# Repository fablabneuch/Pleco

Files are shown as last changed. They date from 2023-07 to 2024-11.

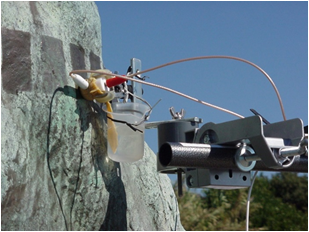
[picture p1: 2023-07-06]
wiki/images/5. Evaluation des protections/download (8).png

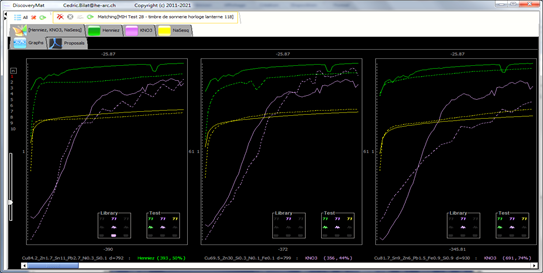
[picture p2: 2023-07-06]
wiki/images/1. Analyse - Outil CLAMTEC/download (2).png

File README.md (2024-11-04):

# Pleco

Pleco est un pinceau électrolytique d’un nouveau genre, constitué d’éléments à fabriquer et à assembler soi-même, ergonomique et d’utilisation facile. Conçu initialement pour le nettoyage localisé et par réduction électrolytique du ternissement de pièces en argent, il permet de proposer une alternative au traitement par immersion des éléments métalliques.

Shield: [][cc-by-sa]

This work is licensed under a
[Creative Commons Attribution-ShareAlike 4.0 International License][cc-by-sa].

[][cc-by-sa]

[cc-by-sa]: http://creativecommons.org/licenses/by-sa/4.0/
[cc-by-sa-image]: https://licensebuttons.net/l/by-sa/4.0/88x31.png
[cc-by-sa-shield]: https://img.shields.io/badge/License-CC%20BY--SA%204.0-lightgrey.svg

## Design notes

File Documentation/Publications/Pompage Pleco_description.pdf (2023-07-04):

# Travail de Bachelor Pompes Pleco

A l’attention de Vassili Tikhomirov et Christian Degrigny

Par Andreas Lazzarotto

Juillet 2017

### Abstract

The Pleco, an electrolytic tool designed by the HE-ARC, is an Open Source project involving two pumps. The pumps used are expensive laboratory pumps. Within the 2nd year of my bachelor diploma, I have been proposed to study the context of use of those pumps. Furthermore I have been asked to continue this work for my bachelor final work, and to design some cheap Open Source pumps for the Pleco.

This project first involved a complete context and user analysis to understand the end-users needs. The idea was to develop pumps that would be more adapted to the Pleco use. The design itself followed and permitted to build a first prototype. The final goal of this project was to produce a batch of pumps and a full documentation for anyone to make them.

### Résumé

Le Pleco, outil électrolytique développé par la HE-ARC, est un projet Open Source nécessitant l’utilisation de deux pompes. Les pompes utilisées jusqu’à aujourd’hui sont des modèles de laboratoire très coûteuses. Il m’a été proposé en deuxième année d’étudier le contexte d’utilisation de ces pompes, et de continuer cette étude en projet de bachelor en développant des pompes de remplacement bon marché et open source.

Ce projet a été mené d’abord par une analyse poussée du contexte et des utilisateurs qui a permis de bien comprendre les besoin réels et de créer des pompes plus adaptées et plus fonctionnelles que celle utilisées à l’origine. Suit la conception en elle-même, qui a mené à la construction d’un premier prototype fonctionnel. L’objectif final du projet est la fabrication d’une petite série de pompes et la mise à disposition complète de la documentation permettant de les construire.

### Remerciements

Je tiens à exprimer ma gratitude et mes remerciements à :

M. Christian Degrigny, professeur à la He-Arc, pour avoir proposé et suivi ce travail de bachelor,
M. Vassili Tichomirov, professeur à la He-arc, pour avoir tutoré ce travail de bachelor,
M. Romain Jeanneret, assistant de recherche à la He-Arc pour le temps qu’il m’a consacré en entretiens et observations,
M. Gaëtan Bussy, assistant de recherche à la He-arc pour son aide concernant l’électronique et la programmation, ainsi que son expertise concernant le FabLab,
Mme. Carole Baudin, professeur à la He-Arc, pour son soutien au cours du projet,
La société Minivalves (NL) pour la fourniture d’échantillons gratuits de duckbill valves,
L’association Fritzing Fab (D) pour la fabrication rapide de prototypes de PCBs.

## Table des matières

7.1.1 Boite | Erreur ! Signet non défini.

## 1 Introduction

Le sujet de mon projet de Bachelor est la conception de pompes, accessoires indispensables au fonctionnement du Pleco. Le Pleco est un nouveau pinceau électrolytique permettant le nettoyage d'objets patrimoniaux en argent terni ou la stabilisation d’objets en plomb sujets à des phénomènes de corrosion active. L'innovation vient du renouvellement continu de l'électrolyte via un système de pompage. Ce pinceau a été développé en collaboration entre la HE-ARC Ingénierie et la HE-ARC Conservation-Restauration. Il est entièrement fabricable dans un FabLab, un espace normalement équipé d’une imprimante 3D et d’une découpeuse laser. Le réseau FabLab est implanté dans de nombreux pays. De plus, le Pleco est mis à disposition du public sous licence Open Source, afin que la communauté mondiale des professionnels de la conservation-restauration puisse en bénéficier tout en ayant la possibilité de l'améliorer. Mon projet entre dans cette philosophie et a pour but de mettre à disposition de cette même communauté des pompes Open Source, à prix réduit et fabricables avec les mêmes outils que le Pleco. On devrait ainsi remplacer les pompes actuelles du pinceau électrolytique Pleco par une alternative open source / open hardware meilleur marché.

### 1.1 Objectif

L’objectif est de concevoir deux pompes pour le pinceau électrolytique Pleco en tenant compte de différentes contraintes liées à l’environnement de production, à la philosophie open source et à la conception orientée vers l’utilisateur, en abaissant au maximum le coût de revient.

Le cahier des charges officiel du travail de Bachelor est consultable en annexe A1

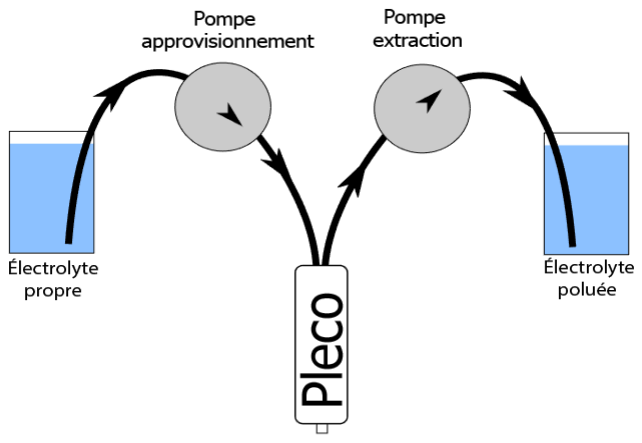
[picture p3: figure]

Schéma de fonctionnement du Pleco

Note : le volume d’électrolyte est en réalité suffisant pour n’avoir qu’un seul récipient avec une recirculation du fluide.

### 1.2 Pompes actuelles

Pompe de chimie KNF Simdos 10

Caractéristiques techniques :

- Débit de 1 à 100 mL/min grande précision
- Hauteur de colonne d’eau de 3m (aspiration)
- Pression max 85psig / 5.6bar
- Alimentation 100 - 240 V / 50 - 60 Hz
- Température d’opération +5 to +40° C
- Température du liquide +5 to +80° C
- Viscosité jusqu’à 500 cSt
- Précision +/-2% (nominal)
- Répétabilité +/-1%
- Consommation 24 W
- IP65
- Dimensions: 150 x 93 x 144 mm
- Poids: 0.9 kg

Avantage :

- Silencieuse
- Débit maîtrisé et mesuré
- Fonction amorçage
- Débit par à-coups
- Capable d’aspirer de l’air (non calculé dans le débit)
- Chimiquement résistant

Inconvénient :

- Prix élevée ~1000.-
- Trop d’options non-utilisées
- Difficultés d’accès au réglage à la volée
- Temps d’accès à la fonction d’amorçage trop long
- Nécessite un filtre pour protéger la pompe de toute microparticule, poussière issues du traitement et pouvant l’endommager
- Poids élevé, tout en restant gérable
- Réparation (due au blocage du système des membranes) nécessitant de faire intervenir le fabricant

### 1.3 Contraintes

- De fonctionnement
- Avoir un rapport de débit entre les deux pompes de 1 à 10 (débit entre 10 et 100mL/min) (Extraction avec un débit supérieur à l’approvisionnement)
- Avoir une fonction amorçage (bouton mettant débit max)
- Avoir une fonction pause
- Contraintes exogènes
- Faire circuler des bulles d’air dans l’électrolyte
- Supporter des pH compris entre 4 et 10.5
- Imposées par l’utilisateur
- Donner un moyen de comparaison visuel entre les débits
- Créer un produit robuste avec une bonne durée de vie
- Etre le plus silencieux possible
- Adapter l’ergonomie aux conservateurs-restaurateurs
- Mettre le projet sous licence Open Source / Open hardware
- Coûter le moins cher possible
- Autres contraintes
- Produire les pièces dans un Fablab (outils spécifiques)

## 2 Analyse de la demande

### 2.1 Cahier des charges fonctionnel

Une première analyse méthodique a permis d’identifier et de caractériser les fonctions que doit remplir l’objet. Cette analyse par méthode APTE® est en annexe A2.

De cette analyse découle une liste de fonctions qui doivent être satisfaites. La plupart de ces fonctions impliquent des solutions techniques simples pour être réalisées, et ne seront pas explicités dans le présent rapport. Les fonctions faisant intervenir le facteur humain ou l’environnement de travail sont plus complexes à traiter, et sont présentées dans la suite de ce cahier des charges.

### 2.2 Cahier des charges ergonomique

2.2.1 Fonctions sujettes à une analyse
Suite à la définition des fonctions, certaines requièrent une analyse ergonomique et anthropotechnologique pour mieux cerner les contraintes et l’attente des utilisateurs.
- FC1 : Faciliter l’assemblage
- FC2 : Fournir à l’utilisateur les informations et outils nécessaires au montage
- FP3 : Permettre à l'utilisateur de régler les deux pompes (physiquement)
- FP4 +FP4bis : Contrôler les 2 pompes (de manière différentielle)
- FC16 : S’intégrer sur le plan de travail
- FC17 : Contrôler la pompe (IHM et feedback)
- FP6 : Fabriquer la pompe dans un environnement Fablab

2.2.2 Analyses nécessaires

FC1 + FC2
Cerner les capacités de l’utilisateur (en l’occurrence des conservateurs-restaurateurs) en termes d’assemblage, et déterminer les limites de leurs compétences.
Déterminer les outils nécessaires à la compréhension des systèmes à assembler, et construire la documentation de montage en fonction de ces données.

FP3 + FP4 + FP4bis + FC17
Déterminer comment le réglage des pompes doit être opéré en fonction de l’utilisation du Pleco : différentes possibilités de réglages sont imaginables, elles doivent être testées pour déterminer laquelle est la plus appropriée.
Concernant le contrôle physique, il est nécessaire d’essayer deux types de curseurs : rotatifs et linéaires. Je suis personnellement convaincu que les curseurs linéaires donnent un meilleur feedback visuel de leur position par rapport à des curseurs rotatifs.
Une observation du travail journalier d’un conservateur-restaurateur pourrait aussi permettre d’identifier des routines reproductibles et ainsi alléger la charge cognitive.
La fonction FC17 : Contrôler la pompe, pose aussi la question de la position de l’interface de contrôle sur le plan de travail en parallèle à la position des pompes. Une observation de la fréquence de réglage des pompes, de l’environnement de travail des conservateurs-restaurateurs et de l’utilisation des pompes permettra de faire des choix sur ce sujet.

FP6
L’intégration dans la conception de l’environnement de fabrication et des outils à disposition est ici primordiale. Il faudra analyser les contraintes liées à l’environnement d’un Fab Lab.

## 3 Reformulation de la demande

Suite à ce premier travail d’analyse, la demande a été reformulée comme suit :

L’objectif du travail sera de concevoir un ensemble de pompes avec leurs contrôles en respectant les points suivants, dans leur ordre d’importance :

- Egaler les performances de débit des pompes originalement utilisées
- Fabriquer les pompes dans un FabLab
- Faire intervenir au maximum des outils Open Source
- Prendre en compte au maximum l’utilisateur dans la conception
- Limiter au maximum les coûts
- Faciliter les réglages des pompes
- Faciliter le transport et le rangement de l’ensemble
- Ajouter des fonctionnalités (contrôle de l’électrochimie)

## 4 Proof of concept

Le premier objectif de mon travail est de valider la possibilité de construire une pompe étanche et fonctionnelle dans un FabLab, avec comme outils principaux une découpeuse laser et une imprimante 3D.

### 4.1 Choix de la technologie

Il s’agit donc tout d’abord de choisir une technologie de pompage compatible avec la fabrication en FabLab, les débits définis ainsi que d’autres critères comme les saccades de débits.

Type | Péristaltique | À membranes

Illustration

Principe physique

On comprime un tube souple localement pour pousser le fluide qu'il contient

Un mouvement d'aller-retour d'une membrane dans une
chambre, associé à des valves antiretour met le fluide en mouvement
Stabilité du débit | pulsé | pulsé
Résistance chimique | Seul le tuyau est en contact avec le fluide | possibilité d'utiliser des membranes résistantes chimiquement (PTFE / AL / etc.)
Type d'étanchéité | Pas d'étanchéité | membrane / fermeture de carter
Précision de la fabrication | Très tolérante | Tolérante
Fabrication dans un Fablab | Facile | Moyennement difficile
Bruit | Bruyant | Modéré

Bon Acceptable Médiocre

Voir la boite morphologique complète en Annexe A3.
Après avoir essayé des pompes péristaltiques, j’ai pu noter que ces pompes réclament un très fort couple moteur et que le fonctionnement est assez bruyant, entre autre à cause des prise de contact alternatives des galets avec le tuyau. Cette solution n’a pas pu être choisie car le bruit est un des critères très importants pour le travail en continu avec les pompes du Pleco. Le choix s’est donc porté sur une technologie de pompes à membrane.

### 4.2 Conception d’une pompe à membrane

4.2.1 Définition

Les pompes à membrane fonctionnent avec, comme leur nom l'indique, une membrane qui oscille. L'oscillation de la membrane peut être créée par un excentrique mû par un moteur, un piston, un moteur linéaire, une vibration électromagnétique ou actionnée par de l'air comprimé.

Le mouvement de la membrane, accompagné de clapets d'entrée et de sortie, permet le plus souvent de réunir la fonctionnalité, pour tous les fluides, de pompages difficiles et précis.

La technologie de la simple ou double membrane, permet de réaliser des pompes capables de rester dans des dimensions extrêmement réduites (micro pompes) et d'être placées dans toutes les positions (même en immersion totale). D'autre part, elle ne transforme en rien la nature des liquides transportés.

Les applications touchent donc les secteurs, du médical, de l'alimentaire, de la chimie et pétrochimie, de l'analyse, de l'aquariophilie, du transport de liquides en petite quantité, etc.

[Wikipedia]

4.2.2 Principe de conception

Une solution simple serait de créer un empilement de plaques découpées au laser, prenant en sandwich une membrane en polymère.

Pompes « sandwich »

Se pose alors la question de l’étanchéité entre les plaques.

Utiliser une membrane en élastomère permettrait d’obtenir directement l’étanchéité en la serrant entre les plaques. Un joint pourrait être réalisé dans la même matière que la membrane pour l’interface chambre / couvercle.

Le point suivant est la mise en mouvement de la membrane. Percer la membrane reviendrait à créer une source de fuite potentielle, il faut donc identifier des moyens de mettre en mouvement la membrane sans la percer.

Une solution valable serait de maintenir la membrane entre deux aimants permanents (voir figure ci-contre), l’un étant dans la chambre et l’autre au bout d’une biellette à l’extérieur de la chambre.

4.2.3 Dimension de la membrane et de la chambre

Le débit max doit être de 100mL/minute

En considérant 2 cycles par seconde (chiffre empirique), au régime maximal, on obtient un volume par cycle de 0.85mL. En modélisant le volume balayé par la membrane avec un déplacement de la partie centrale de 3mm au centre, le diamètre minimal de la chambre a été fixé à 30mm.

Solide définissant le volume de la chambre de pompage

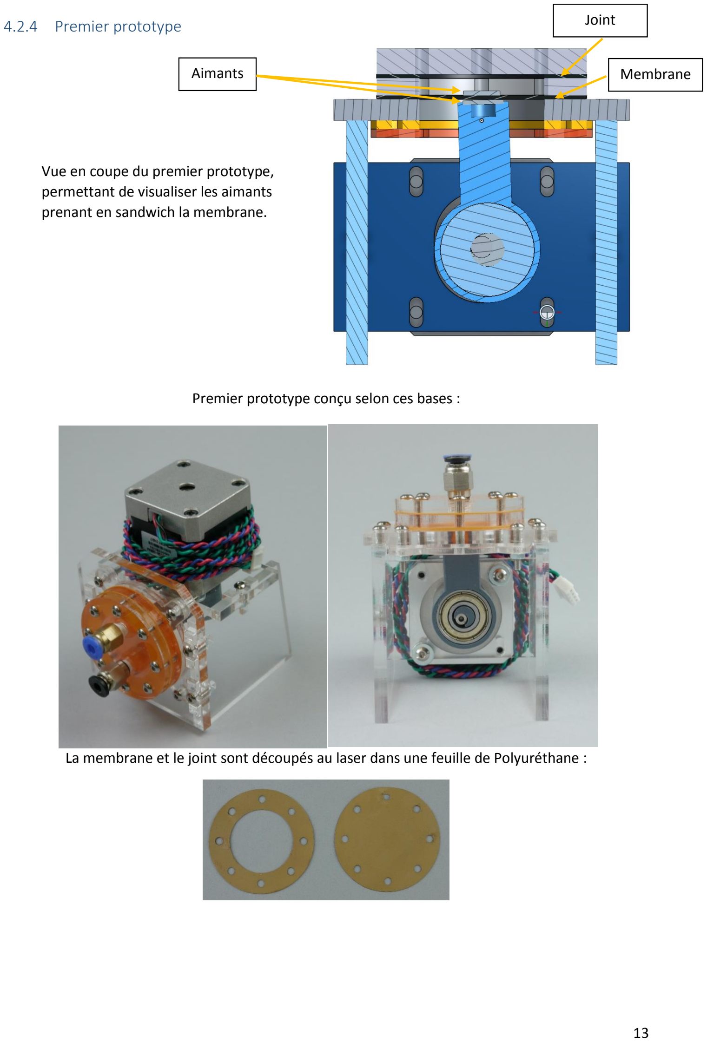
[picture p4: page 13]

4.2.4 Premier prototype

Premier prototype conçu selon ces bases :

La membrane et le joint sont découpés au laser dans une feuille de Polyuréthane :

Vue en coupe du premier prototype, permettant de visualiser les aimants prenant en sandwich la membrane.

Aimants | Membrane

Joint

Pour garantir le fonctionnement de la pompe, il faut ajouter des valves antiretour à l’entrée et à la sortie de la pompe.

Ces valves sont disponibles dans le commerce dans les secteurs de l’aquariophilie et dans le médical, où elles sont principalement utilisées dans les lignes de perfusion.

Ces valves fonctionnent pour la plupart sur la technologie « duckbill valve » (valve bec de canard).

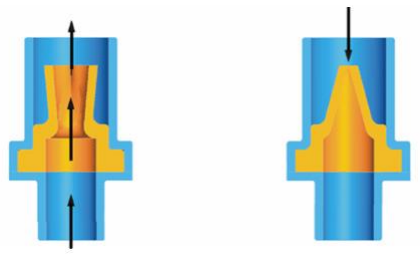
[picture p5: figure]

Fonctionnement d’une « duckbill valve »

Sur le premier prototype, ces valves sont des antiretours de perfusion obtenues auprès d’un assistant de recherche du domaine santé.

Elles sont montées sur les tubes d’entrées et sortie de la pompe.

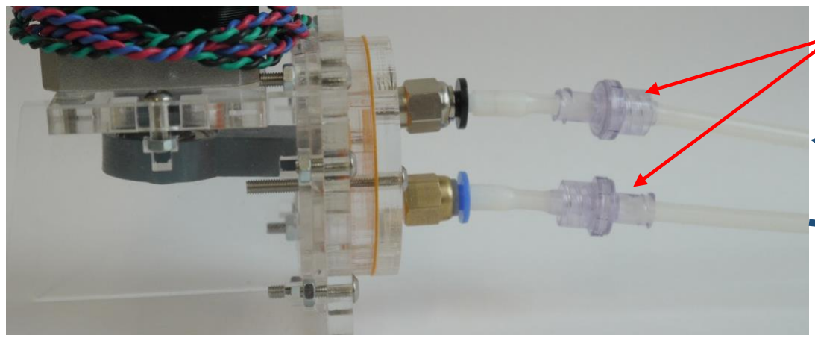
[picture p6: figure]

Antiretours de perfusion utilisés sur le premier prototype

4.3

### Validation du prototype

Le premier prototype s’est avéré fonctionnel, me confirmant qu’il est possible de construire une pompe à membrane dans un FabLab en utilisant des éléments standards disponibles partout dans le monde. Ce prototype n’est cependant pas parfait, et des défauts ont pu rapidement être identifiés : les aimants ont tendance à se décoller parfois, et la membrane est trop souple.

Antiretours

Circulation
d’électrolyte

Fluide en
contre
pression : la
valve bloque
le fluide

Fluide en
pression : la
valve laisse
passer le
fluide

### 4.4 Optimisation du prototype

Suite à cette première expérience, il semblait intéressant d’expérimenter l’utilisation de fil souple imprimé en 3D. Ces filaments sont disponibles chez plusieurs fabricants, et sont fabriqués à base de polyuréthane thermoplastique.

Le fait d’imprimer la membrane permet de lui intégrer un élément de mise en mouvement directe, évitant l’utilisation d’aimants. On peut ainsi accoupler directement la membrane avec la biellette sans autres éléments mécaniques.

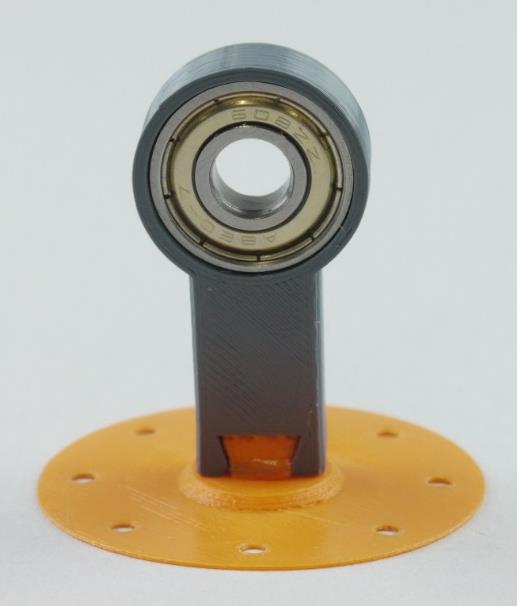
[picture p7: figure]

Assemblage de la membrane imprimée à la biellette

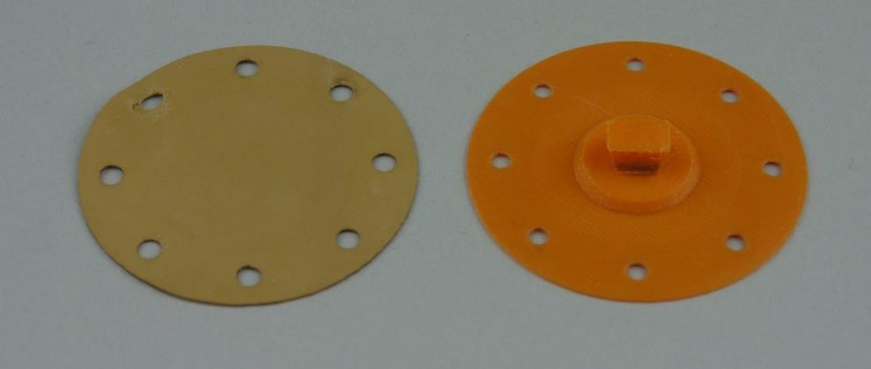
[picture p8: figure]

Comparaison entre les membranes découpée et imprimée

Suite à cette modification, le pompage s’est avéré plus constant (membrane plus rigide), le défaut de déconnection a disparu et l’étanchéité est restée parfaite.

Le principe de pompage est validé, et il faut maintenant s’intéresser à l’utilisation des pompes dans leur contexte particulier.

## 5 Recherches ergonomiques et anthropotechnologiques

### 5.1 Observations

5.1.1 Public concerné : les conservateurs-restaurateurs

La présente conception s’adresse à un public très ciblé : les conservateurs-restaurateurs (C-Rs). Afin de mieux centrer la conception autour des utilisateurs, il faut cerner leur profil et comprendre les représentations qu’ils se font de leurs outils et des pièces sur lesquelles ils travaillent.

Suite à plusieurs entretiens et observations avec Romain Jeanneret et Christian Degrigny (assistant de recherche et professeur du domaine C-R), le point le plus important est le fait que l’objet est le centre de leur attention. En effet, les objets à restaurer ou stabiliser ont une forte valeur historique et parfois une valeur pécuniaire élevée. La plus grande inquiétude des C-R est de dégrader l’objet, ce qui est une cause importante d’anxiété.

Il est intéressant de noter que leur travail s’articule autour des qualités suivantes : les C-R sont minutieux, précis, consciencieux et appliqués. Il est aussi important de prendre compte de l’environnement économique de la conservation-restauration. Ce milieu n’est pas facilement financé et les C-Rs sont souvent obligés de contourner un manque de moyen par du système-D. Ils sont donc assez bricoleurs et débrouillards.

5.1.2 Outil associé : le Pleco

Le Pleco est un pinceau électrolytique permettant le nettoyage de l’argent terni et la stabilisation de pièces en plomb oxydées. Il fait intervenir une solution électrolytique. Les réactions électrochimiques induites lors du nettoyage de l’argent génèrent des gaz, et il est donc préférable d’utiliser le Pleco sous une hôte.

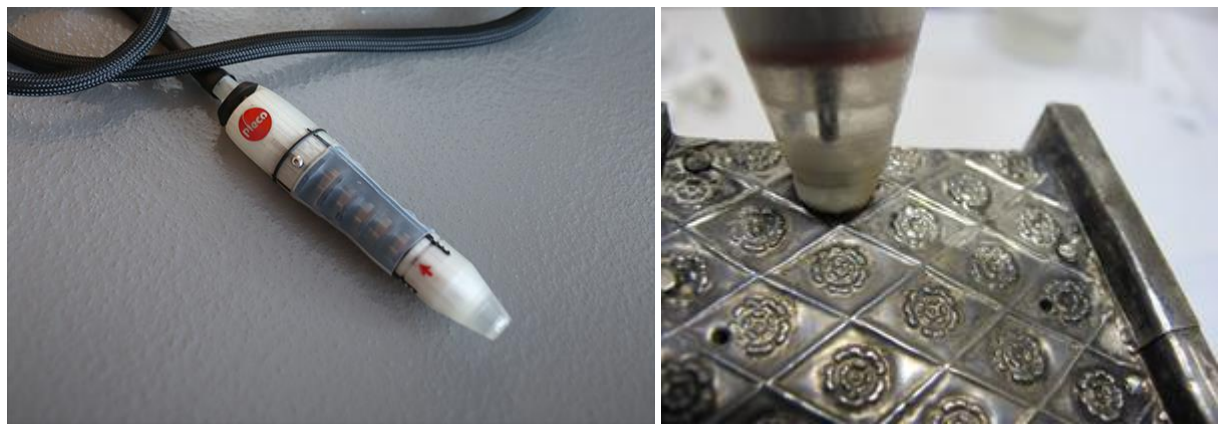
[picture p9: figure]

Le Pleco | Pièce en argent terni en cours de nettoyage
Cet | environnement | est | particulier :
paillasse carrelée avec peu de surface, souvent encombrée d’autres accessoires
(alimentation | stabilisée, | multimètre,
support, etc.). Il faudra tenir compte de cette observation pour optimiser la disposition des outils sur le plan de travail. Il faut aussi noter que les carreaux sont parfois humides, les matériaux des pompes devront donc être à l’épreuve de l’eau. (Il faut aussi prendre en compte le risque de fuite ou de fausses manipulations avec des liquides sur le plan de travail.)

L’un des aspects intéressants du Pleco est sa dimension communautaire. En effet, il a été développé pour et par une communauté de C-R, et des workshops permettent aux C-R de se rassembler pour construire et apprendre à utiliser leur nouvel outil. Le développement de cette petite communauté favorise une conception itérative par l’utilisation, comme elle est décrite dans le schéma suivant :

Cycle de conception du Pleco

5.1.3 Environnement de fabrication : Le Fab Lab

« La notion de Fab Lab (contraction de l’anglais FABrication LABoratory, traduction : laboratoire de fabrication) désigne un atelier composé de machines-outils pilotées par ordinateur pouvant fabriquer rapidement et à la demande des biens de nature variée. […] Pour être appelé Fab Lab, un atelier de fabrication numérique doit respecter la charte Fab Lab, (http://fab.cba.mit.edu/about/charter/) mise en place par le MIT. (http://fr.wikipedia.org/wiki/MIT) Les Fab Labs sont réunis en un réseau mondial très actif. » [Wikipédia]

La charte FabLab éditée par le MIT:

Mission: les fab labs sont un réseau mondial de laboratoires locaux, qui rendent possible l’invention en donnant aux individus accès à des outils de fabrication numérique.

Accès: vous pouvez utiliser le fab lab pour fabriquer à peu près n’importe quoi (dès lors que cela ne nuit à personne) ; vous devez apprendre à le fabriquer vous-même, et vous devez partager l’usage du lab avec d’autres usagers et utilisateurs.

Éducation: la formation dans le fab lab s’appuie sur des projets et l’apprentissage par les pairs ; vous devez prendre part à la capitalisation des connaissances et à l’instruction des autres utilisateurs.

Responsabilité: vous êtes responsable de :
– La sécurité : savoir travailler sans mettre en danger d’autres personnes ni endommager les machines,
– La propreté : laisser le lab plus propre que vous ne l’avez trouvé,
– La continuité : contribuer à entretenir et réparer les outils, à gérer les stocks de fournitures et à rendre compte des incidents.

Secret: les concepts et les processus développés dans les fab labs doivent demeurer disponibles pour un usage individuel même si la propriété intellectuelle peut être protégée.

Business: des activités commerciales peuvent être initiées dans les fab labs, mais elles ne doivent pas faire obstacle à l’accès ouvert. Elles doivent se développer au-delà du lab plutôt qu’en son sein et bénéficier à leur tour aux inventeurs, aux labs et aux réseaux qui ont contribué à leur succès.

[fablab-neuch.ch]

En d’autres termes, l’utilisation d’un Fab Lab s’articule autour du partage des ressources et des connaissances, et il faudra donc sensibiliser les utilisateurs du Pleco et de ses pompes à cette philosophie.

Ce milieu de fabrication particulier implique donc que les sources de l’objet créées soient disponibles, donc Open Source / Open Hardware.

Afin de protéger la propriété intellectuelle liée aux pompes, mais aussi afin de protéger ses créateurs contre toute action en justice liées à une utilisation inadéquate, il est nécessaire de placer les sources sous une licence spécifique réglementant l’usage des fichiers mis à disposition. Les licences standards Creative Common et leurs dérivés, plutôt appliquées aux créations artistiques, ne protègent pas les « objets » et la meilleure alternative pour l’open-hardware est la licence CERN, éditée par l’organisme du même nom dans le cadre de son programme de partage de technologies ouvertes. (Voir Annexe B1.1 pour la licence originale et B1.2 pour la licence traduite en français.)

Cette licence protège les créateurs de toute malfaçon ou mauvaise utilisation de l’objet, mais « oblige » aussi toute personne appliquant une modification à partager cette modification, tout en citant la source de base. Cette « obligation » est un encouragement au partage des connaissances et à l’amélioration continue à travers une communauté d’utilisateurs, et cette notion extrêmement importante devra être bien expliquée aux conservateurs-restaurateurs, notamment dans la notice de montage et au cours des workshops.

Les outils à disposition pour la fabrication des pompes, que l’on devrait pouvoir retrouver dans la plupart des FabLab, sont les imprimantes 3D (FDM disponibles partout), et une découpeuse laser. Il faudra se limiter au maximum à ces deux outils, et éviter les usinages « conventionnels », extrêmement chronophages et demandeurs de compétences et d’outillages peu répandus (tournage, fraisage)

5.1.4 Ergonomie de montage

[Note : il est admis que dans un premier temps la fabrication des éléments des pompes sera assurée par moi ou par une autre personne familiarisée avec le Fab lab, dans le but de créer des kits qui seront assemblés par des conservateurs-restaurateurs lors de workshops.

La question de la fabrication n’est donc pour le moment pas abordée dans d’autres mesures que de prévoir des petites séries]

L’assemblage du Pleco est principalement basé sur l’emboîtement d’éléments en plastique, maintenus en position par des boulons métriques. L’utilisation d’écrous noyés dans des emplacements spécifiques permet de mettre en place des vis dans des trous borgnes, sans avoir à maintenir manuellement l’écrou. Il permet de plus de fixer ensemble des plaques perpendiculaires les unes aux autres.

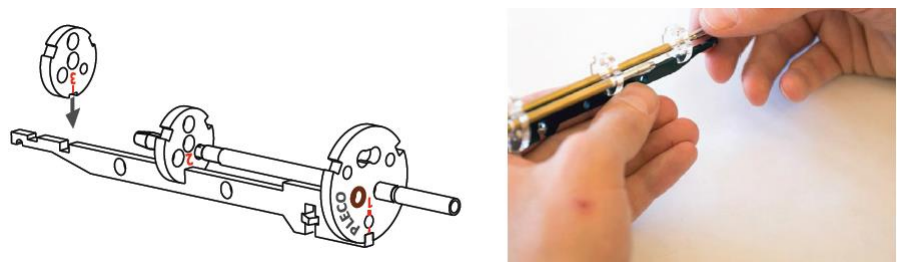
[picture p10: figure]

Illustrations extraites de la notice de montage du Pleco

Ces opérations sont simples à la condition que le logement d’écrou soit de la bonne taille, en garantissant un bon maintien de l’écrou, et que l’insertion de celui-ci ne brise pas la pièce.

L’assemblage par gaine thermo rétractable est intéressant dans son principe, mais s’est montré complexe à exécuter et requiert la création d’un outil d’assemblage spécifique.

Afin de simplifier le montage des pompes, il serait préférable de normaliser les types d’assemblages, en réutilisant la méthode des écrous noyés.

Il sera aussi important de normaliser la visserie (diamètre et longueur) afin d’éviter une charge cognitive supplémentaire lors du montage. 3 tailles de vis différentes au maximum semblent être idéales (en prenant en compte les vis déjà employées sur le Pleco). Ces vis devront toutes être assemblées avec le même outil, encore une fois dans un souci simplicité pour le monteur.

La question des compétences des monteurs reste entière, des tests itératifs sur des prototypes avec des notices provisoires permettront d’atteindre les objectifs fixés en termes de difficulté et temps maximum de montage.

La conception finale ainsi que la notice d’assemblage s’appuieront donc sur ces tests et sur les recommandations précédentes liées à l’assemblage.

### 5.2 Création de situations de références

Suite à ces observations, il reste quelques points obscurs pour lesquels aucune situation de référence n’a été trouvée. Il est donc nécessaire de les générer, en créant des tests impliquant les utilisateurs. Ces tests concernent la disposition des pompes sur le plan de travail, les méthodes d’assemblages et l’interface homme machine.

5.2.1 Disposition sur le plan de travail

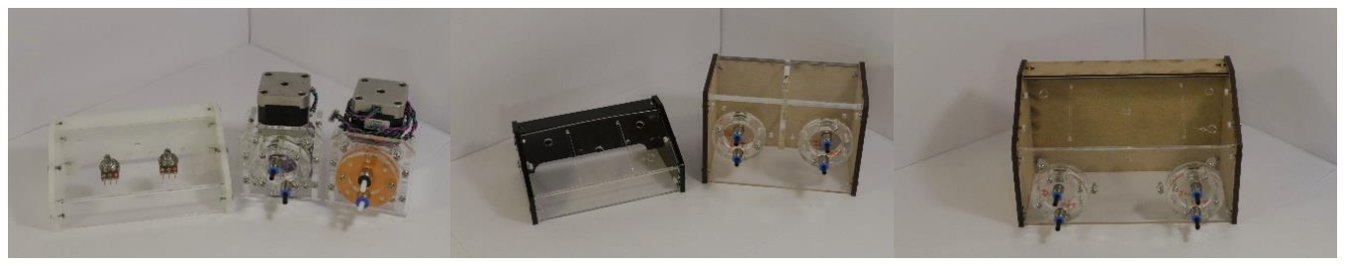
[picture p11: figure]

Console + 2 pompes | Console + pompes combinées | All in One

5.2.1.1 Test 1 : Pompes et console de contrôle séparés

Observations :

La console est placée en premier, à gauche de l’alimentation stabilisée, puis les pompes sont disposées de part et d’autre du réservoir d’électrolyte, au centre de la paillasse,
légèrement en arrière du statif.

Suite au constat que les pompes n’ont pas

besoin d’intervention durant l’utilisation, elles ont été reculées au fond de la paillasse pour dégager de la place autour de l’objet.

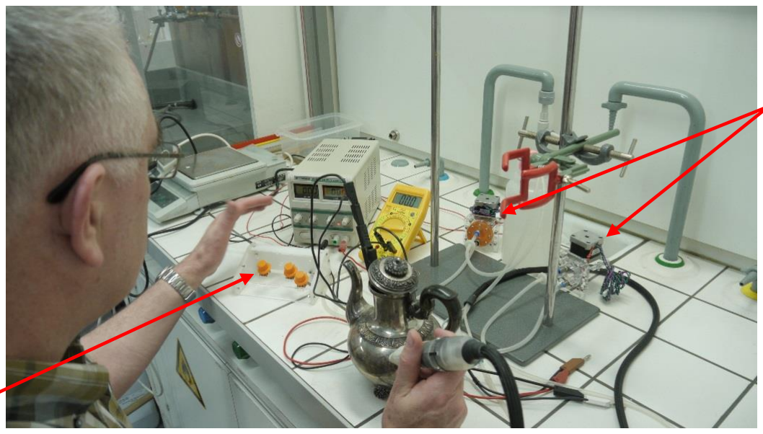
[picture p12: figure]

Pompes

Console de
contrôle

5.2.1.2 Test 2 : Pompes combinées et console de contrôle séparés.

Observations :

La console est placée à nouveau à gauche de l’alimentation stabilisée.

Le système des pompes est placé à côté du réservoir, avec une réflexion concernant le fait qu’elle pouvait être placée loin des mains. Elle est cependant placée bien en face de l’opérateur, à portée de vue.

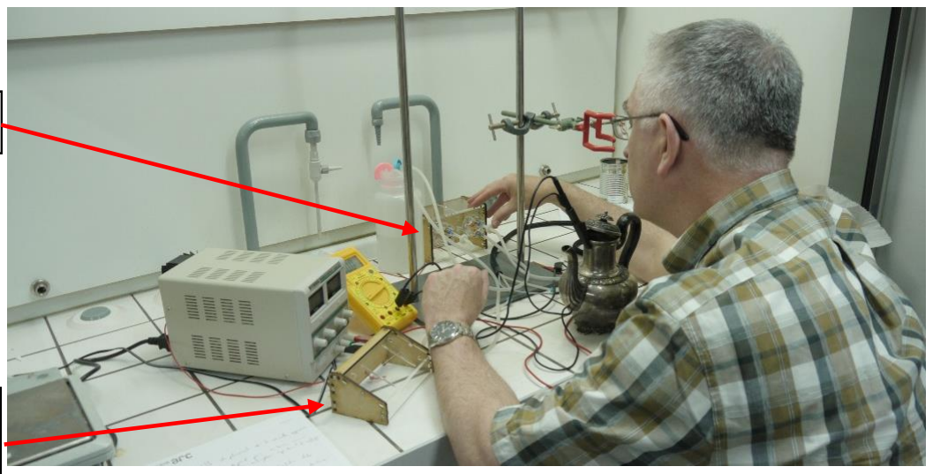
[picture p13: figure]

5.2.1.3 Test 3 : All in one

Observations :

Le boîtier est d’abord placé à gauche de l’alimentation stabilisée, puis un commentaire est fait sur la longueur des tubes pour aller au réservoir, jugés trop longs. Le boitier est alors déplacé entre l’alimentation stabilisée et le réservoir.
C. Degrigny constate alors que les contrôles sont trop loin. De plus la fluidique s’en retrouve très rapprochée des éléments électriques et circule entre l’utilisateur et les contrôles.

Pompes

Console de
contrôle

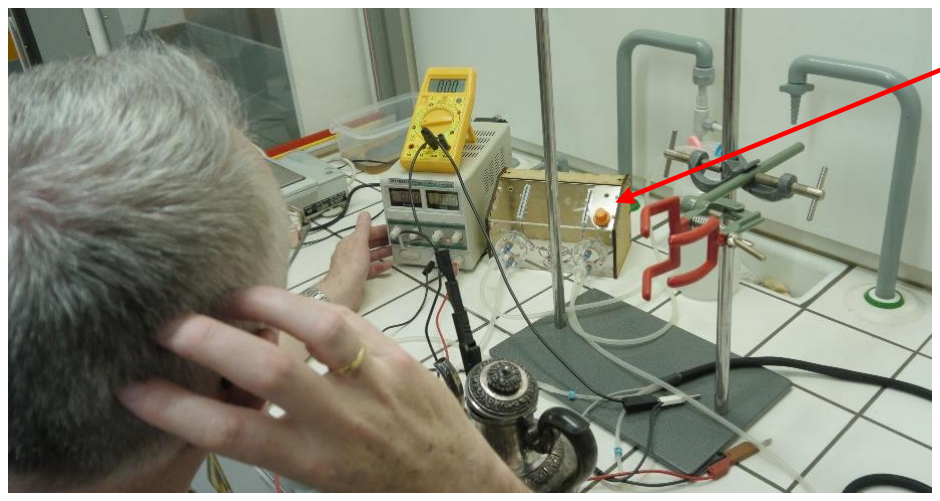
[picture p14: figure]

All in one

5.2.1.4 Choix suite à cette analyse

La solution All in one, séduisante par sa compacité et sa simplicité de mise en œuvre (aucun câble), se révèle inutilisable en situation réelle. Cette solution génère trop de risques de fausses manipulations, de débranchements accidentels de tubes et de potentielles éclaboussures. De plus, une impression de lourdeur se dégage de l’objet selon Mr Degrigny.

La solution de deux pompes séparées séduit Mr Degrigny, mais pose des problèmes techniques et pratiques à l’installation, comme le dédoublement des câbles qui augmente le risque d’erreurs de montage du système, et l’inversion possible des pompes. De plus, bien que les pompes soient individuellement plus compactes, elles occupent plus d’espace que la combinaison de pompes sur la paillasse. Elles offrent cependant plus de souplesse de positionnement. C’est de plus le système auquel
C. Degrigny est habitué.

Le choix du combo de pompes a été appuyé par R. Jeanneret et D. Witschard, qui considèrent que la solution des pompes séparées est à éliminer, convaincus que la multiplication des connections amène un risque d’erreur de manipulation trop important.

Le choix final se porte donc sur une combinaison de pompes et une console de contrôle séparée, avec la possibilité de les superposer.

5.2.2 Tests de montage

L’objectif ici n’était pas de mettre en concurrences des méthodes de montages différentes, mais de valider et améliorer celles utilisées dans le monde de l’open source.

5.2.2.1 Assemblage par vis-écrou encastré

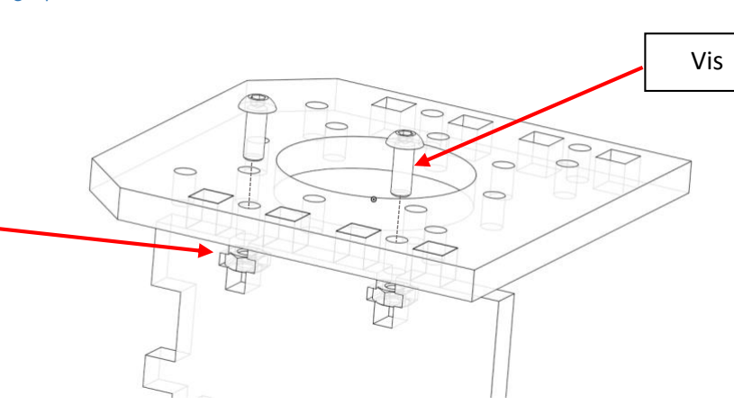
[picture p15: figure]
Vis

Exemple d’assemblage par écrou-vis encastré

La méthode d’assemblage par vis-écrou encastré est utilisée dans de nombreux projets utilisant des plaques découpées au laser. Elle a l’avantage d’être très simple à mettre en œuvre et de ne demander aucune retouche après découpe. Cependant, pour être pratique à utiliser, il faut que l’écrou, une fois inséré dans son logement, ne bouge plus. Cet encastrement est facile à obtenir dans des matériaux mous comme le MDF, mais plus compliqué dans du PMMA (plexiglass) car celui-ci est très cassant. Il est extrêmement difficile de trouver les cotes juste du logement de l’écrou pour qu’à l’insertion l’écrou ne passe pas à travers la plaque ni ne provoque une fissuration. De plus, la répétabilité dimensionnelle de la découpe des logements n’est pas excellente. Pour contourner ce problème, utiliser des écrous en nylon semble être la solution idéale. En effet, c’est l’écrou qui se déforme légèrement à l’insertion, ce qui évite de détériorer le PMMA.

Ecrou

5.2.2.2 Maintien d’écrous difficiles d’accès

La partie active de la pompe (le sandwich de plaques contenant la chambre) est maintenue sur la face avant du boîtier par 8 vis M3 sur son pourtour. Le but est de répartir au mieux le serrage pour garantir l’étanchéité. Une fois le boîtier fermé, les écrous sont très difficiles d’accès, c’est pourquoi il était nécessaire de trouver un moyen de les maintenir dans le cas d’une intervention sur les pompes, par exemple pour remplacer la membrane ou un joint.

Vue filaire du système de maintien des écrous

L’idée ici est de prendre en sandwich les écrous entre la face du boitier et une autre plaque, tout en les empêchant de tourner grâce à une plaque intermédiaire découpée à la forme des écrous. Ces deux plaques sont-elles mêmes maintenues à l’arrière de la face du boîtier par trois vis. Lors de l’assemblage, on commence par monter ces deux plaques et les écrous sur la face du boitier, ce qui permet d’ajouter la partie active des pompes en fin de montage.

Plaque empêchant la rotation des écrous

Corps de
pompe

5.2.3 Interface homme machine

Le dernier point critique concernant l’ergonomie d’utilisation est l’interface homme-machine. Sur les pompes originalement utilisées, l’IHM est complexe (accès aux fonctions par des menus/ sous menus, besoin de valider les valeurs, etc.). L’idée ici est de donner l’accès direct à chaque fonction à l’utilisateur pour simplifier le réglage, l’amorçage ou la purge des pompes.

La fonction la plus intéressante étant le réglage, plusieurs types de commandes sont disponibles : le potentiomètre linéaire, comme utilisé sur les tables de mixage sonore par exemple, et les potentiomètres rotatifs, plus courants.

Exemple de potentiomètres linéaires et rotatifs

Le choix de ces interfaces n’est cependant pour l’instant pas possible et des tests en utilisation réelle des pompes seront nécessaires. Ces deux solutions sont facilement permutables, et il n’est pas préjudiciable de continuer la conception sans en avoir choisi une.

## 6 Concept final

Le chapitre suivant décrit la conception des pompes et des périphériques intégrés. Il est à noter que cette conception sera poursuivie après le rendu du présent rapport, et que certains points de conception auront possiblement évolué ou disparu.

### 6.1 Modification du cahier des charges

A la semaine 5 du travail de bachelor, il a été ajouté au cahier des charges l’intégration d’un voltmètre programmable à l’électronique des pompes. Cette fonction était au départ listée dans les options à intégrer dans le futur. Il en résulte l’intégration d’un dispositif d’affichage comprenant un écran 16x2 caractères et d’un clavier 5 touches associé, ainsi que des bornes de connexion en façade de la console de contrôle (voir le chapitre « électronique » en page 35).

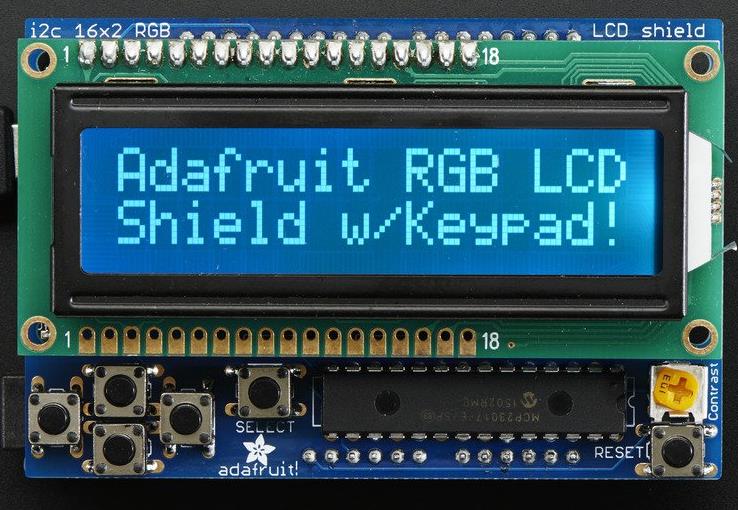
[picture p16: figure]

Il a aussi été demandé de trouver une solution mieux intégrée pour les valves antiretours des pompes. Les valves doivent être internes aux pompes et non en ligne sur les tubes sortants, afin d’éviter toute possibilité d’erreur de montage. L’utilisation d’éléments non disponibles dans les circuits de grande distribution est tolérée car la solution initiale utilisant des valves externes reste tout de même disponible pour qui voudrait fabriquer ces pompes en dehors d’un workshop organisé par le FabLab-Neuch (voir page 29 pour les détails de conception).

### 6.2 Scénario d’utilisation

6.2.1 Utilisation

Situation de départ : Le Pleco et les pompes, ainsi que tous les accessoires nécessaires au fonctionnement de l’outil sont rangés dans une boite. L’alimentation stabilisée, le statif, l’objet à nettoyer et le matériel de laboratoire sont déjà sur la paillasse.

Opérations :

- Sortir les éléments de la boite
- Disposer les pompes et la console de contrôle sur la paillasse
- Brancher le câble électrique entre les pompes et la console
- Brancher la fluidique du Pleco
- Brancher les câbles électriques du Pleco
- Remplir le réservoir d’électrolyte
- Brancher le transformateur des pompes au secteur
- Amorcer les pompes
- Régler le potentiel électrique à l’aide du voltmètre intégré à la console
- Régler le régime des pompes sur la console
- Nettoyer l’objet

6.2.2 Rangement et transport

Situation de départ : Le Pleco est en état d’être utilisé sur la paillasse.

Opérations :

- Purger les pompes
- Eliminer l’électrolyte souillé
- Débrancher le transformateur du secteur
- Débrancher les câbles électriques du Pleco
- Débrancher la fluidique du Pleco
- Débrancher le câble électrique entre les pompes et la console
- Ranger les éléments dans la boite
- (Ranger la boite dans le placard)
- (Ranger la boite dans un sac de protection et le transporter)

6.2.3 Débordement imprévu de l’électrolyte sur l’objet

Situation de départ : Le nettoyage de l’objet est en cours. L’électrolyte n’est pas suffisamment aspiré et une coulure apparaît sur l’objet.

Opérations :

- Appuyer sur le bouton forçant la pompe d’extraction au régime maximal
- Essuyer la coulure avec un chiffon
- Appuyer à nouveau sur le bouton pour revenir au régime réglé

### 6.3 Revue de conception

6.3.1 Principes d’ensemble

La conception des pompes, de la console de contrôle et de la boîte de rangement doit répondre à des exigences communes à ces trois objets, comme suit :

6.3.1.1 Machines à disposition

Comme indiqué précédemment dans l’analyse de l’environnement de production, les outils de production à disposition se résument aux imprimantes 3D (technologie FDM) et à la découpe laser.

6.3.1.2 Production en petite série

Le gros point faible du Pleco pour la production en petite série est sa conception articulée autour de pièces imprimées en 3D : les temps d’impression sont élevés et les pièces demandent à être ajustées après l’impression. Il faut en tirer la leçon suivante : limiter l’utilisation de pièces imprimées au maximum, et concevoir les pièces de manière à ce qu’elles ne demandent aucune retouche après l’impression. Il faut donc privilégier au maximum l’utilisation de la découpe laser qui est très fiable et rapide.

6.3.1.3 Matériaux

Les boîtiers des pompes doivent être découpables au laser et résistants à l’eau. Le plexiglass a donc été choisi pour sa facilité de découpe au laser, sa résistance élevée au milieu humide et sa disponibilité. De plus, il est disponible dans divers coloris (transparent, translucide, fumé, etc.)

La membrane et les joints seront imprimés en matériaux souple (filaflex, ninjaflex ou autre). Ces pièces demandent une attention particulière, et seront certainement le point faible pour la production en série.

6.3.1.4 Visserie

La visserie doit être normalisée au maximum. Des vis M3 à tète 6 pans creux, déjà utilisées sur le Pleco, seront employées au maximum. La longueur de ces vis doit elle aussi être uniformisée pour limiter le nombre de références et simplifier l’approvisionnement dans le cadre de petites séries.

Comme vu précédemment, les écrous utilisés seront en Nylon. Les vis elles seront en acier inox pour prévenir une oxydation due au milieu humide.

6.3.1.5 Logiciel de conception

Pour ce projet, le logiciel «OnShape » a été choisi pour le dessin 3D des pièces. Ce choix est justifié par la volonté des créateurs de ce soft à le mettre à disposition de makers. En effet, l’utilisation est gratuite pour les makers, et il est très facile de récupérer les fichiers 3D car ceux-ci sont stockés dans le cloud, et visible par le public.

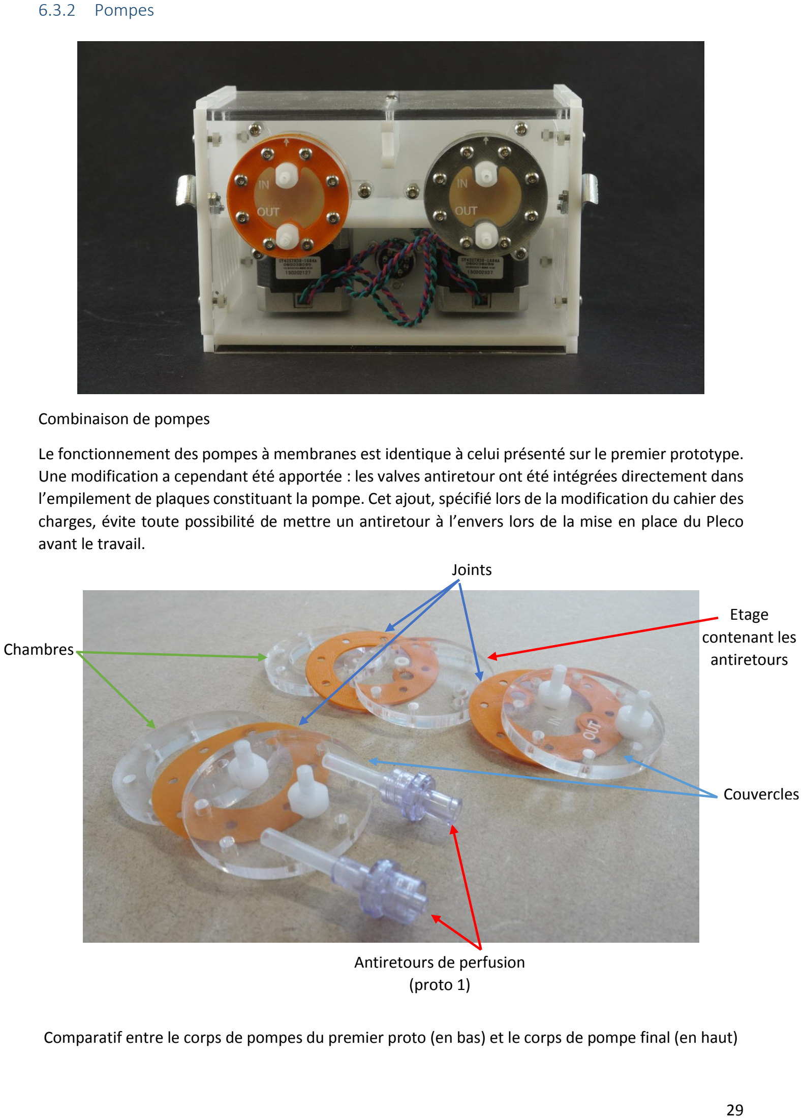
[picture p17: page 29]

6.3.2 Pompes

Combinaison de pompes

Le fonctionnement des pompes à membranes est identique à celui présenté sur le premier prototype. Une modification a cependant été apportée : les valves antiretour ont été intégrées directement dans l’empilement de plaques constituant la pompe. Cet ajout, spécifié lors de la modification du cahier des charges, évite toute possibilité de mettre un antiretour à l’envers lors de la mise en place du Pleco avant le travail.

Comparatif entre le corps de pompes du premier proto (en bas) et le corps de pompe final (en haut)

Chambres

Joints

Etage
contenant les
antiretours

Couvercles

Antiretours de perfusion
(proto 1)

Antiretour de perfusion et duckbill valve Détail de l’étage antiretour

Les duckbill valves utilisées ici proviennent de la société Minivalves dont le siège est au Pays Bas. Ces valves présentent des caractéristiques compatibles avec la pompe : pression d’ouverture de 0.05bar et contrepression admissible de 5bar.

Duckbill
valves

6.3.3 Console de contrôle

La console de contrôle intègre les éléments suivants :

- L’électronique de contrôle des moteurs
- Les éléments d’interaction pour le contrôle des pompes
- Bouton d’amorçage
- Bouton de démarrage/arrêt
- Bouton d’urgence
- Potentiomètres pour le réglage des débits
- L’écran affichant le potentiel entre la pièce et l’électrode de référence
- Les boutons servant à régler les potentiels de référence
- Les connectiques
- Puissance (12v venant du transformateur)
- Connecteur pour les pompes
- Electrochimie : fiches bananes 4mm blanche pour électrode de ref et noire pour masse

Amorçage

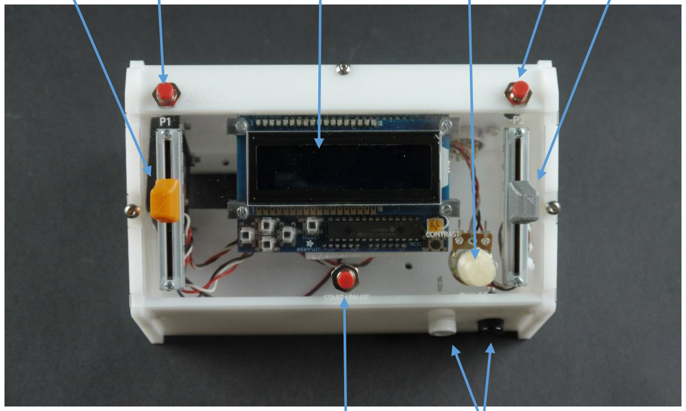
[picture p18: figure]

Bouton
start/stop

Borniers
voltmètre

Les contrôleurs de moteurs pas-à-pas chauffent rapidement, et pour les maintenir à température de fonctionnement il faut les ventiler, c’est pourquoi des évents sont creusés sur les flancs de la console. Un ventilateur de 40mm est intégré à la console pour garantir le refroidissement.

La console de contrôle peut être superposée aux pompes si besoin

7.1.1 Le coffret

Le coffret s’assemble sur le même principe que les pompes et la console de commande, et intégrera des logements et points de fixations pour ranger le Pleco, le transformateur électrique, une boite de tampons pour le Pleco, ainsi que le câble électrique reliant les pompes à la console. Le développement de ces espaces de rangement est prévu pour la poursuite du projet de Bachelor après le rendu du rapport.

La fermeture du coffretse fait grâce à deux ferrures standard facilement trouvables dans le commerce. Pour garantir le bon fonctionnement de ces fermetures dites « grenouillères » il faut donner un peu de souplesse à la structure qui les supporte. Pour ce faire, un emplacement pour un pad en caoutchouc est creusé dans les flancs du coffret. Le caoutchouc permettra de garantir l’auto verrouillage des grenouillères.

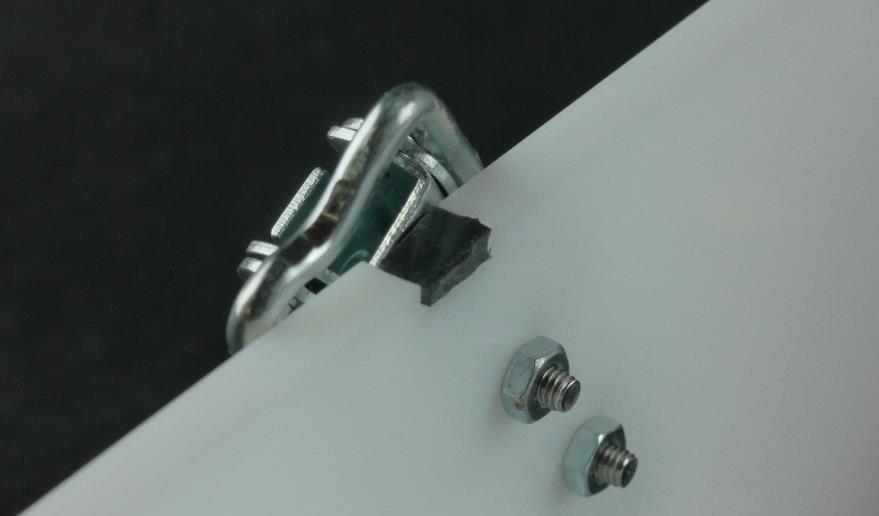
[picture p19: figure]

La poignée de transport est sur ce prototype une poignée de tiroir standard. Cette protubérance empêche l’empilement de boites, ce qui est péjoratif pour le stockage. Une réflexion autour d’une poignée escamotable sera menée après le rendu du présent rapport.

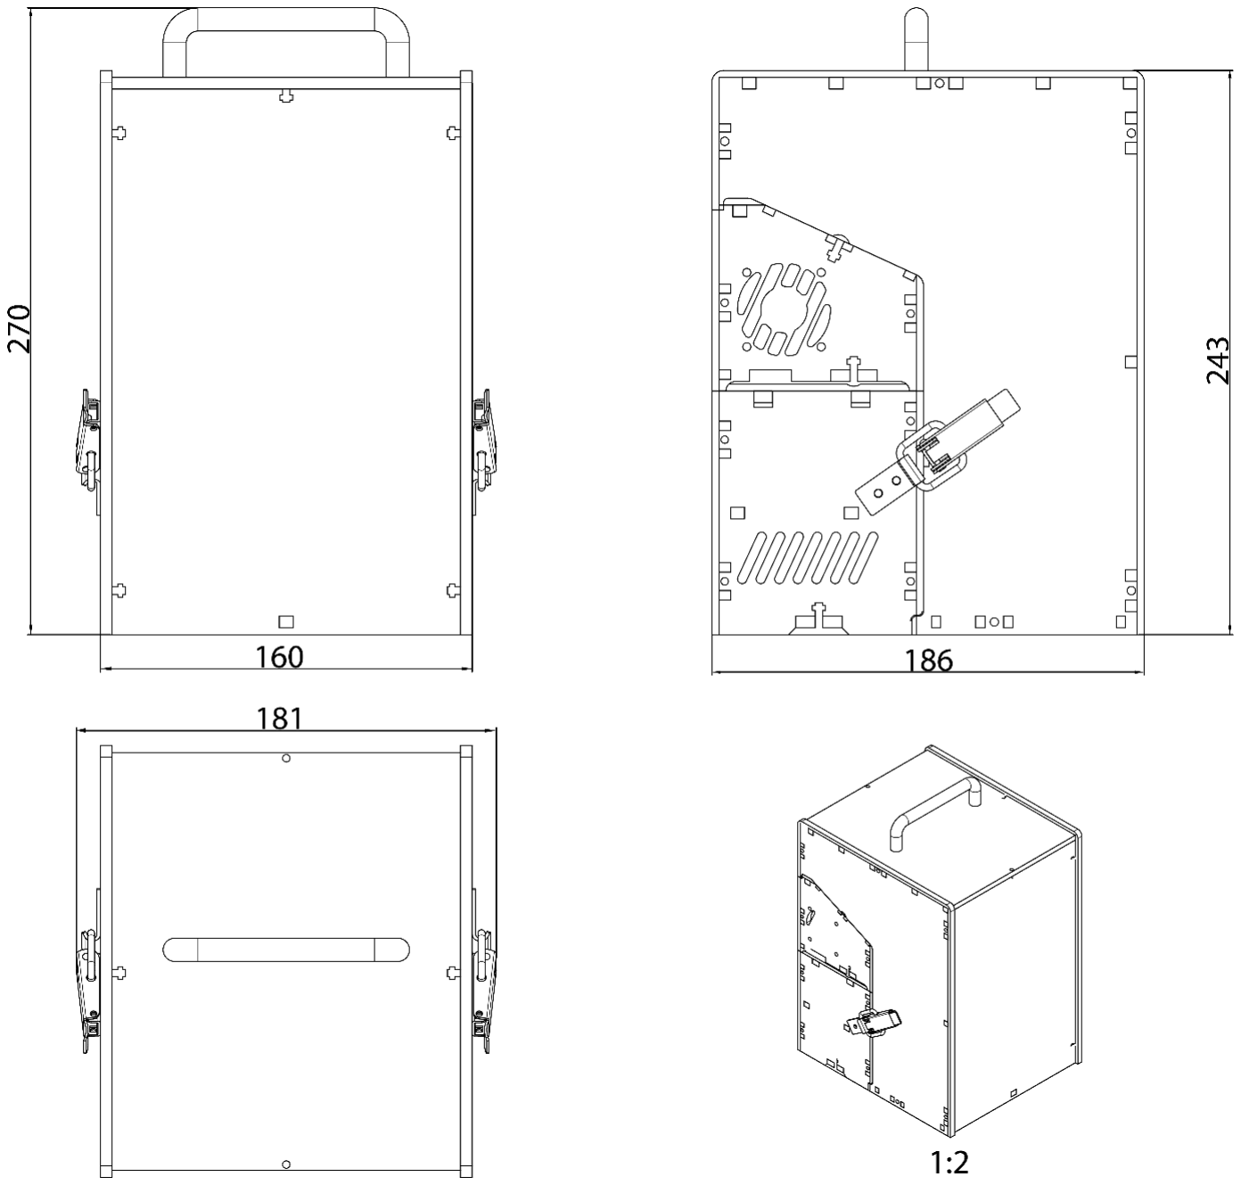
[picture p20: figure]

Dimensions générales des pompes dans leur coffret

7.1.2 Electronique

La conception de l’électronique ne fait au départ pas partie du cahier des charges de mon projet de bachelor. C’est cependant un point très important, aussi bien pour la conception de la console de contrôle que pour la réalisation de tests réels avec les prototypes futurs. Il a donc paru nécessaire de concevoir rapidement une électronique permettant le contrôle des pompes, en adéquation avec les contraintes ergonomiques mises en avant dans le présent rapport.
Ce module est divisé en deux parties : la commande et la puissance. La partie commande fait intervenir un microcontrôleur programmable et divers capteurs, boutons et potentiomètres. La partie puissance fait intervenir deux contrôleurs de moteurs pas-à-pas.

La partie commande emploie une carte Arduino Léonardo : le choix de
celle-ci est justifié par la simplicité du langage de programmation Arduino,
par la facilité à se procurer cette carte, et par le fait que l’ensemble du
projet arduino est Open Source. (Datasheet en Annexe B2)

Les contrôleurs de moteurs choisis sont du type Pololu A4988, car ils sont extrêmement faciles à se procurer du fait de leur très large emploie dans les imprimantes 3D. Ils ont de plus un coût très abordable, et font partie du matériel standard trouvé dans un FabLab. (Datasheet en Annexe B3)

L’interfaçage de la partie commande avec les différents capteurs et la partie puissance demande la création d’un montage électronique. Ce montage a d’abord été réalisé sur une plaque d’essai.

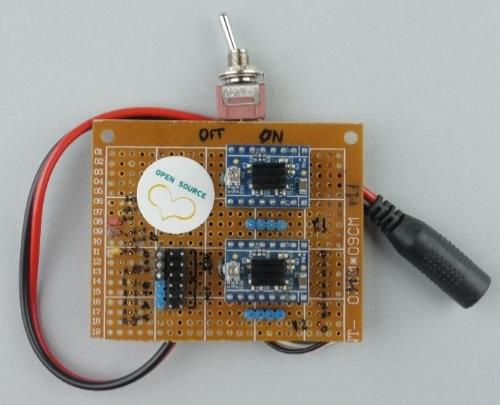
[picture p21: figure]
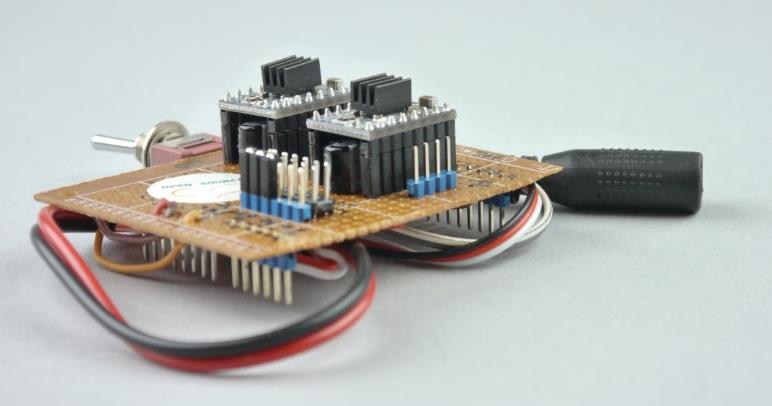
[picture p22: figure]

Cette première version a permis de valider le montage, et a servi de base à la création d’une version industrielle du PCB. Le shield (PCB accessoire emboitable sur un Arduino) a été dessiné sur Fritzing, un logiciel open-source, et produit par Fritzing-Fab, un service de fabrication de PCB à coût faible organisé par les créateurs de Fritzing.

Vue dessus / dessous du PCB conçu avec Fritzing

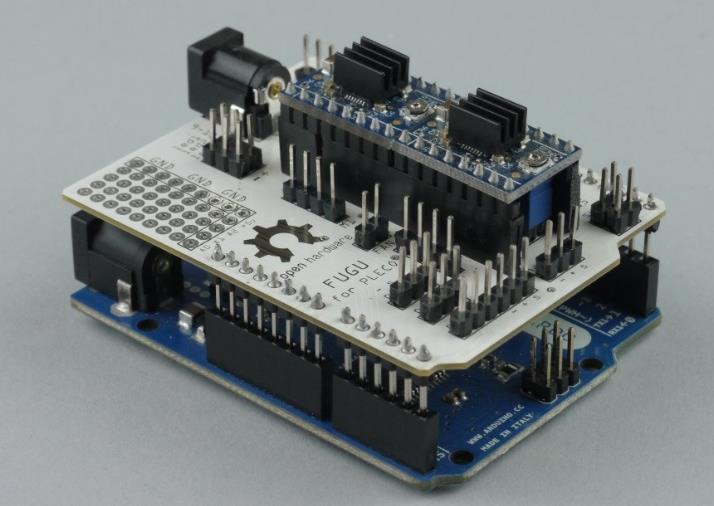
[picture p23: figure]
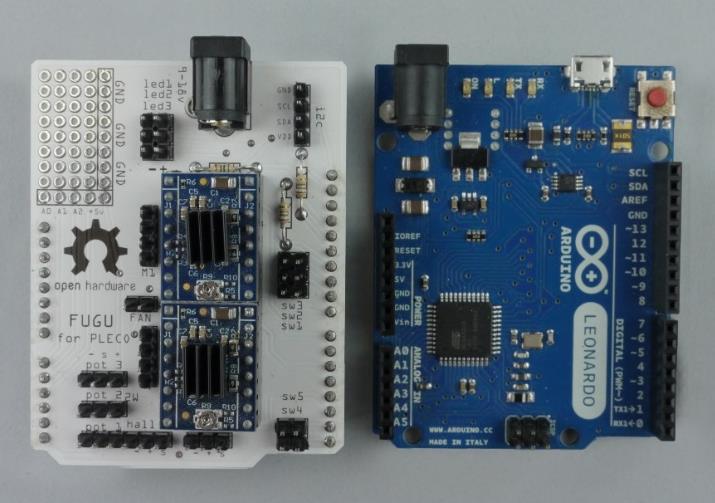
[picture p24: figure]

Le shield assemblé à côté d’un arduino Leonardo | Le shield monté sur l’arduino Léonardo

Ce premier shield a permis de valider complètement le choix de l’électronique, cependant il s’est avéré manquer une chose : des points de fixation. Lors de la conception de la console de commande, il a été décidé de modifier le PCB en y ajoutant des trous de fixation.

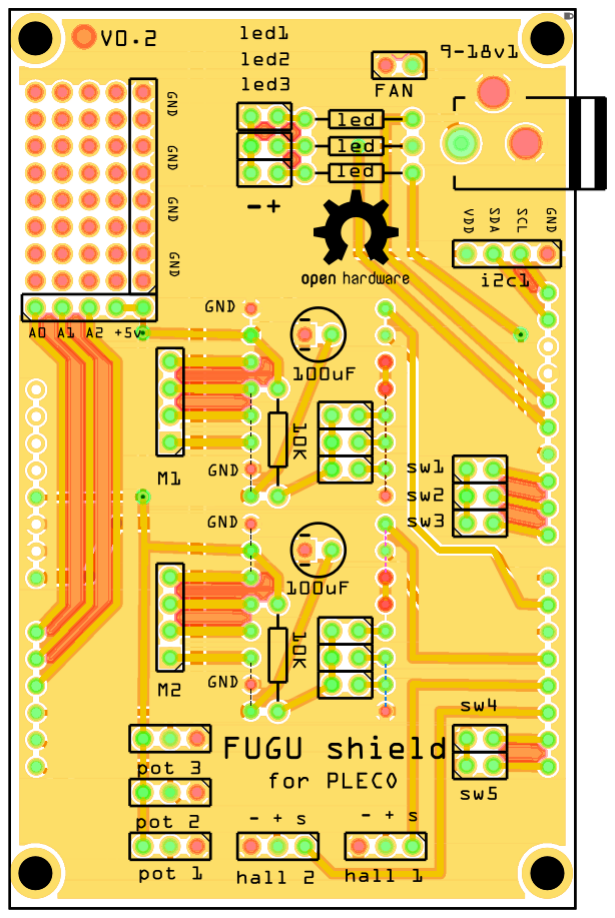
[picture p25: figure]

Shield V0.1 et V0.2 (échelle 1/1)

Le nouveau shield est un peu plus grand, mais intègre 4 points de fixation et voit sa prise d’alimentation déplacée pour faciliter l’intégration de l’électronique dans la console de commande.

Dans la perspective de la production d’une petite série, il sera possible d’avoir recours à une entreprise spécialisée dans la production de PCB.

## 8 Conclusion

### 8.1 Etat du projet

A la date de rendu du présent rapport, l’avancement du projet remplit les objectifs décrits par le cahier des charges. Un prototype fonctionnel a été réalisé. Les analyses fonctionnelles et anthropo-ergonomiques en début de projet ont permis de bien orienter la conception et de construire un produit au plus proche des utilisateurs. L’objet créé remplit des fonctions qui n’avaient pas été identifiées dans la demande initiale et qui s’avèrent très utiles, comme le coffret permettant le stockage des pompes et du Pleco dans un volume réduit.

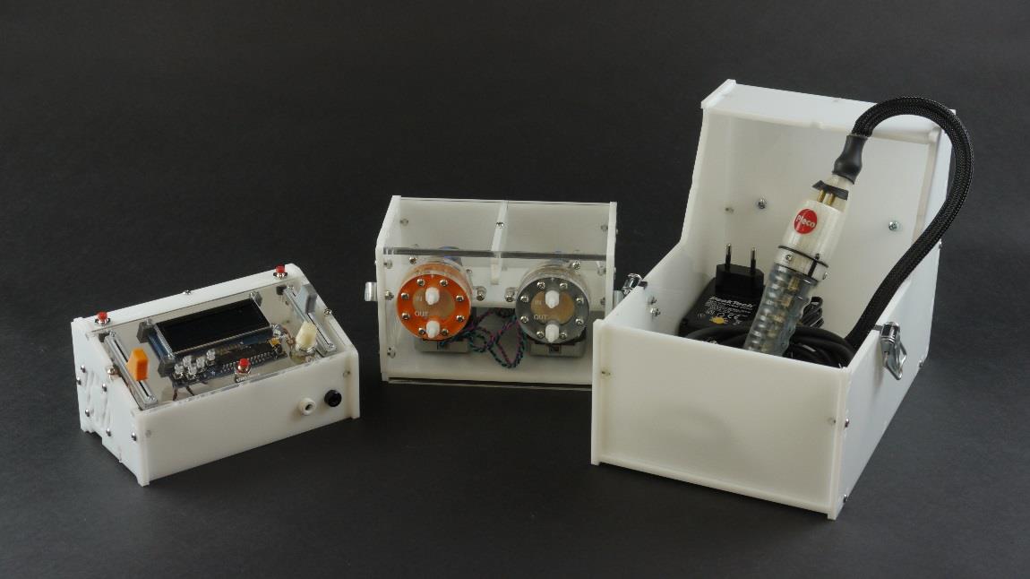
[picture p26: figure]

### 8.2 Poursuite

La suite du projet s’articulera autour de la documentation pour la construction des pompes ainsi que sur la fabrication d’une première petite série. L’objectif est de doter le département de conservation-restauration de quelques pompes à présenter lors du prochain workshop de fabrication du Pleco et de proposer aux C-Rs déjà équipés d’un Pleco d’acquérir un kit de pompes. L’utilisation des pompes par ces derniers sera la consécration du travail accompli et permettra l’amélioration du produit par ses utilisateurs.

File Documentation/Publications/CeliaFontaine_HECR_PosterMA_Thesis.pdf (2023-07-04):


Fig. 3: Détail de l‘interface métal/lacs de la bulle du Pape Nicolas V, conservée aux Archives départementales de Loire Atlantique, Nantes.


Fig. 2: Vue en coupe du principe de fonctionnement du Pleco : création de la cellule électrolytique (à gauche) et réduction des produits de corrosion (droite)

Introduction et problématique
Conservés dans un environnement contenant des vapeurs d‘acide organique, les objets en plomb et alliages plomb-étain peuvent développer une corrosion active se manifestant par la formation de produits de corrosion blancs et pulvérulents, de type carbonate. Des traitements électrolyques de réduction en immersion permettant la consolidation du métal réduit et la préservation du profil des produits de corrosion ont été développés. Bien que ces derniers aient fait leur preuve, ils présentent certaines limites. Les objets composites indissociables ne peuvent être immergés sans risque de dégradation des autres matériaux. Un projet de recherche a néanmoins rendu possible le traitement de réduction localisé sans immersion. Mené durant deux ans, le projet “Saint-Maurice“ dirigé par Christian Degrigny (Ra&D, HE-Arc CR) a permis le développement d‘un pinceau électrolytique, le Pleco. Conçu originellement pour traiter le ternissement de l‘argent, le Pleco a été éprouvé pour réduire localement les produits de corrosion du plomb et des alliages plomb-étain.
La recherche s‘est axée autour de deux problématiques de traitement:
- l‘interface métal/lacs (éléments de textile) des bulles attachées à des parchemins. Un protocole par immersion avait été mis au point au laboratoire Arc‘Antique (Nantes) mais ne donnait pas entière satisfaction car des zones de lacs non protégées apparaissaient au cours du traitement et étaient susceptibles d’être dégradées par l’électrolyte
- les objets peints présentant des lacunes au niveau desquelles se sont développés des produits de corrosion.

Echantillons
Afin de mener notre étude, trois types de matériaux de simulation ont été fabriqués. Les paramètres de traitement ont été déterminés en utilisant de simples coupons métalliques. D‘autres matériaux artificiels plus représentatifs d‘objets patrimoniaux simulaient des bulles attachées à des lacs en soie teintée et des objets peints avec un revêtement (apprêt + peinture glycérophtalique et peinture à l‘huile) lacunaires. Ces matériaux de simulation ont été corrodés artificiellement en présence de vapeurs d‘acide acétique et de copeaux de chênes.

Essais de traitement sur les simulations et cas pratique Les produits de corrosion situés au niveau de l‘interface métal/lacs ont pu être réduits au potentiel de -1.5V/CV sans que le textile, préalablement protégé par du cyclododécane, ne soit altéré. Le tampon du Pleco a été taillé en pointe de façon à se placer au plus près de l‘interface. Compte tenu des bons résultats obtenus, le protocole de traitement a été appliqué à une bulle en plomb du Pape Nicolas V datant du XVe

siècle et conservée au Archives départementales de Loire-Atlantique (Nantes) (Fig.3).
Concernant le traitement des matériaux de simulation d‘objets peints, les produits de corrosion sont réduits sans que le revêtement glycérophtalique ne semble altéré, contrairement à la peinture à l‘huile. En effet, celle-ci se plisse sous l’effet du traitement de réduction et lors du séchage de l’électrolyte, elle se soulève et se détache de la surface. Ce phénomène peut être dû au
Montage | fait que la peinture ne soit pas complètement sèche. électrolytique avec le Pleco
Tout montage électrolytique comprend trois électrodes en contact avec une solution conductrice appelée
électrolyte et nécessite un apport de courant.
Au sein du Pleco sont logées l‘électrode de référence en carbone vitreux CV (contrôle des réactions par mesure du potentiel entre elle et l‘objet) et la contre-électrode de platine. Leur extrémité située dans l‘embout de l‘outil sont immergées dans l‘électrolyte dont l‘apport et l‘extraction se fait par deux pompes à membranes. La solution passe au travers du tampon (mousse en formal polyvinylique) et mouille les produits de corrosion de l‘électrode de travail (objet en plomb). Il se crée ainsi une cellule électrolytique (Fig.2). Les électrodes sont reliées aux bornes d‘un potentiostat.

Etude voltammétrique
Les paramètres de traitement de réduction des produits de corrosion ont été déterminés en réalisant une étude voltammétrique dans le domaine cathodique. On impose une diminution du potentiel de l‘objet à partir du potentiel de corrosion. La densité de courant varie alors en fonction du potentiel appliqué et des pics de réduction sont mis en évidence. La valeur du potentiel de réduction des produits de corrosion, donné par rapport à l‘électrode de référence, correspond au maximum du pic de réduction. L‘électrolyte choisi est une solution neutre de sulfate de sodium (0.1M).

Etude chronoampérométrique
Une fois le potentiel de réduction des produits de corrosion déterminé, celui-ci est imposé à l‘objet faisant ainsi varier la densité de courant de l‘objet. L‘apport d‘électrons permet la réduction des produits de corrosion.

Résultats
Paramètres de traitement
Les produits de corrosion du plomb, type carbonate, sont réduits à partir de E=-1.1V/CV. La réaction est la plus rapide à E=-1.5V/CV. Dans le cas des alliages plomb-étain, on constate la formation d‘un second pic au potentiel E=-1.9V/CV. Ce dernier correspond à la réduction des oxydes d‘étain SnO2

qui se situent en dessous des produits de corrosion du plomb. Se réduisant à un potentiel plus négatif que les carbonates, ils pourront être conservés. En effet, ils sont stables et s‘ils sont réduits, les carbonates qui le sont également, n‘ont plus de points d‘accorches et se détachent de la surface.


Fig. 1: Pleco en cours d‘utilisation lors de la réduction des produits de corrosion au niveau de l‘interface métal/lacs de la bulle du Pape Nicolas V, conservée aux Archives départementales de Loire Atlantique, Nantes.

Présenté par : Célia Fontaine
Master of Arts HES-SO en Conservation-restauration Orientation : Objets scientifiques, techniques et horlogers

# Master-Thesis in Conservation-Restoration :

# Traitement électrolytique localisé des produits de corrosion du plomb et des alliages plomb-étain Mise en application du pinceau électrolytique, le Pleco

Mentor : Romain Jeanneret, Assistant de recherche, Ra&D HE-Arc CR, Neuchâtel
Resp.de stage : Dr. Elodie Guilminot, Ingénieure de recherche, Laboratoire Arc‘antique, Nantes Réalisation : semestre de printemps 2014

Conclusion
Le Pleco apparait aujourd‘hui comme un outil permettant la réduction localisée des produits de corrosion du plomb et des alliages plomb-étain. Ce type de traitement serait particulièrement approprié dans le cas de décors en relief dont la forme n‘est maintenue que par les produits de corrosion. Les réduire permettrait de conserver leur profil.
Il semble plus particulièrement adapté au traitement de surface d’aire réduite, comme nous avons pu le voir avec la réduction des produits de corrosion des bulles attachées à des lacs ou pour intervenir après traitement de réduction en immersion sur des zones non réduites. Enfin, il s‘agit d‘un outil dont l‘apprentrissage et la maîtrise sont aisées et rapides. Son avantage demeure également qu‘il peut être fabriqué par les conservateursrestaurateurs eux-mêmes.

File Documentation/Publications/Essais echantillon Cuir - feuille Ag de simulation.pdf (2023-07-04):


Echantillons de simulation feuille d’Ag ternie / cuir _ 2CRC | 1 | HE-Arc CR _ C. Degrigny / R. Jeanneret_ 27.02.2015

## Essais de nettoyage électrolytique avec le Pleco et en milieu NaNO3 tamponné d’échantillons de feuilles d’argent terni sur support cuir

Installation pour la définition des conditions opératoires du nettoyage électrolytique avec le Pleco utilisé en mode statique

Ces essais visent à tester la faisabilité du nettoyage électrolyte avec le Pleco de feuilles d’argent terni collées à la surface d’un support cuir simulant les panneaux en cuir doré polychrome (dits « cuirs de Cordoue ») utilisés aux XVI-XVIIIe siècles pour décorer les murs. Ces échantillons produits dans le cadre du projet CORDOBA de la Fondation des Sciences du Patrimoine ont été fournis par Laurianne Robinet du Centre de Recherche sur la conservation des Collections (CRCC – Paris) et Céline Bonnot-Diconne du Centre de Conservation et de Restauration du Cuir (2CRC¹
- Grenoble).

Les deux feuilles sont ternies à des degrés divers. Le ternissement est naturel (atmosphère de Paris).

1 www.bonnotdiconne.fr


Echantillons de simulation feuille d’Ag ternie / cuir _ 2CRC | 2 | HE-Arc CR _ C. Degrigny / R. Jeanneret_ 27.02.2015

Conditions du nettoyage :
- le contact électrique sur l’ensemble des feuilles a été vérifié préalablement.
- La solution est du NaNO3 tamponné (citrate de sodium / acide citrique, pH4.8). Les pompes à membrane sont réglées de telle sorte que leur débit limite au minimum la mouillabilité du tampon en mousse microporeuse : notre objectif est de prévenir toute humidification du support en cuir.
- Avant de procéder au nettoyage électrolytique en mode dynamique et à potentiel constant (chrono-ampérométrie – cliché ci-contre), nous avons déterminé les paramètres du traitement en mode statique (Pleco sur son support – cliché ci-dessus) par voltammétrie linéaire cathodique à
l’aide d’un potentiostat (OrigaLysâ, Origastat e200).

Le Pleco utilisé en mode dynamique

- Le balayage en potentiel a été mené de Ecorr à -1,8V/carbone vitreux (0,260V/ESH)) à une vitesse de 10mV/s, tout d’abord sur une plaquette d’argent ternie naturellement (référence) puis sur la feuille d’argent fortement ternie. Du fait du risque de provoquer un bullage d’hydrogène pouvant fragiliser la feuille d’argent, le balayage n’a été mené que jusqu’à -1.2V/carbone vitreux sur la feuille faiblement ternie (annexe).
- Le nettoyage a potentiel constant est mené à -1V/carbone vitreux, un potentiel correspondant à la réduction de certains produits de corrosion (Ag2S ?).

Le but recherché au cours des essais n’est pas de réduire l’ensemble des produits de corrosion mais de préciser le comportement du matériau composite au cours du nettoyage électrolytique (réductions possibles, pressions à appliquer sur le tampon en mode dynamique, risques d’épanchement de la solution).

Echantillons de simulation feuille d’Ag ternie / cuir _ 2CRC | 3 | HE-Arc CR _ C. Degrigny / R. Jeanneret_ 27.02.2015


Echantillons de simulation feuille d’Ag ternie / cuir _ 2CRC | 4 | HE-Arc CR _ C. Degrigny / R. Jeanneret_ 27.02.2015

Echantillon très terni

Utilisation d’un ruban d’aluminium maintenu sous | Tracé voltammétrique en cours jusqu’au bullage d’H2 | Vue approchée
pression pour assurer le contact électrique
L’échantillon après essai de nettoyage (non rincé) | Vue du revers du cuir : pas de tache | Le métal après rinçage à l’eau déionisée (décollement du film métallique)


Echantillons de simulation feuille d’Ag ternie / cuir _ 2CRC | 5 | HE-Arc CR _ C. Degrigny / R. Jeanneret_ 27.02.2015

Echantillon peu terni

Tracé voltammétrique en cours jusqu’au bullage d’H2 L’échantillon après l’essai de nettoyage (non rincé) | Vue du revers du cuir : légère marque
Le Pleco en modes chronoampérométrique | Poursuite du nettoyage (métal non rincé) | Vue du revers du cuir : pas de marque nouvelle
et dynamique


Echantillons de simulation feuille d’Ag ternie / cuir _ 2CRC | 6 | HE-Arc CR _ C. Degrigny / R. Jeanneret_ 27.02.2015

Poursuite des essais

Echantillon très terni : nettoyage en modes chronoampérométrique (-1V/C. vitreux) et dynamique

Echantillon peu terni (et non rincé) : poursuite du nettoyage en modes chronoampérométrique (-1V/C. vitreux) et dynamique

Partie nouvellement
nettoyée et non
rincée

Partie nouvellement
nettoyée et non rincée

Partie anciennement
nettoyée et rincée

Partie anciennement
nettoyée et non
rincée

Echantillons de simulation feuille d’Ag ternie / cuir _ 2CRC | 7 | HE-Arc CR _ C. Degrigny / R. Jeanneret_ 27.02.2015

Conclusion

Le nettoyage électrolytique localisé à l’aide du Pleco de l’argent terni sur support cuir est possible en milieu NaNO3 tamponné grâce à la bonne tenue de la feuille d’argent ternie naturellement. En effet le maintien, à la surface de la feuille, d’un contact électrique est une condition nécessaire à la bonne marche du traitement.

Le Pleco utilisé en mode statique pour la définition des paramètres de traitement ne repose que légèrement sur la surface métallique afin d’éviter tout risque d’épanchement de la solution contenue dans la cellule du pinceau par effet de pression. Cette précaution a pu entraîner des pertes de contact électrique (tracé bleu foncé ci-dessous). On a néanmoins pu mettre en évidence la présence de pics de réduction autour de -1V/C. vitreux sans pouvoir les interpréter clairement. Ce paramètre est utilisé ensuite pour mener le nettoyage en modes chronoampérométrique et dynamique. Le Pleco, pris en main, est déplacé à la surface de la surface à nettoyer.

En cas de ternissement faible, la réduction électrolytique est quasi immédiate et le Pleco peut être déplacé continûment sur la surface à nettoyer.

Si le ternissement est plus important, la réduction électrolytique prend davantage de temps. Le Pleco doit être maintenu en place plus longtemps (quelques secondes) avec le risque d’un épanchement éventuel si le tampon appuie trop sur la surface de l’objet à nettoyer.

Nous avons remarqué qu’après le nettoyage, le rinçage de la surface métallique à l’eau déionisée avec un papier absorbant occasionne la perte du décor métallique. Cela est dû à la colle de peau utilisée pour fixer la feuille métallique qui est soluble en milieu aqueux. Ce problème est accentué par l’effet abrasif du papier absorbant utilisé. Le problème est moindre si le rinçage se fait par tamponnage.

Pour conclure ces essais sont encourageants. Ils montrent toutefois que les paramètres de traitement, tout comme la manipulation du Pleco doivent être adaptés selon la nature du ternissement. Enfin les étapes de l’intervention (consolidation éventuelle de la feuille métallique et rinçage post-nettoyage en milieux non aqueux) doivent être redéfinies avec des spécialistes du matériau associé à l’argent, en l’occurrence des conservateurs-restaurateurs du matériau cuir.


Echantillons de simulation feuille d’Ag ternie / cuir _ 2CRC | 8 | HE-Arc CR _ C. Degrigny / R. Jeanneret_ 27.02.2015

Annexe

Tracés voltammétriques sur les feuilles d’argent différemment ternies (naturellement) et comparaison par rapport à une plaquette d’argent également terni naturellement (référence)

Les maxima des pics de réduction sont indiqués. L’attribution de ces pics sur les feuilles ternies naturellement n’est pas claire. Il semblerait qu’on observe des décalages des pics observés sur la plaquette d’argent.

Sur plaquette en
argent terni
(référence)

feuille Ag très
ternie / cuir

Feuille Ag peu
ternie / cuir

Potentiel de
réduction retenu

Ag2S

Pic intermédiaire

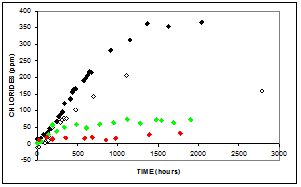
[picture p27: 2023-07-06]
wiki/images/Stockage des matériaux/download (1).png

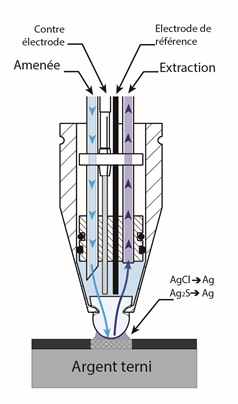
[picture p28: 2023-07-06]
wiki/images/Electrochimie - Principes de base/download (4).png

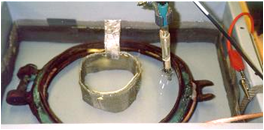
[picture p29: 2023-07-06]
wiki/images/4. Application en Conservation-restauration Stabilisation/download (3).png

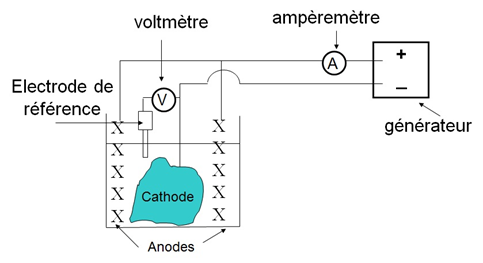
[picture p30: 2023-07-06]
wiki/images/Electrochimie - Principes de base/download (3).png

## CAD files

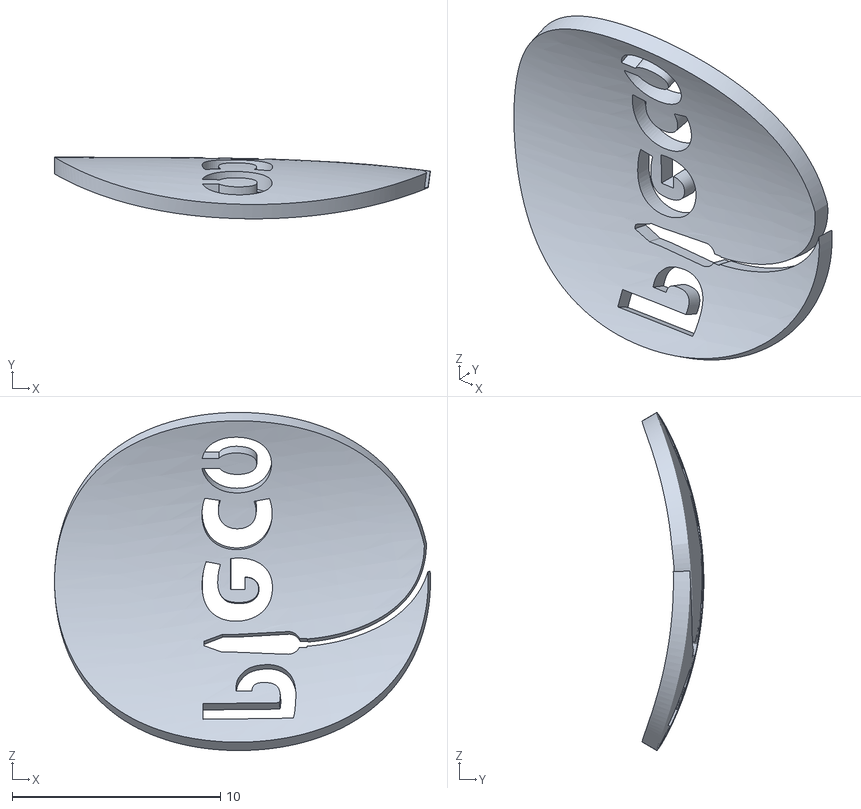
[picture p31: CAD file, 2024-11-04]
Fabrication/3DPrint_FDM/logo_aveccloche_2020.stl
18.0 x 2.96 x 16.2

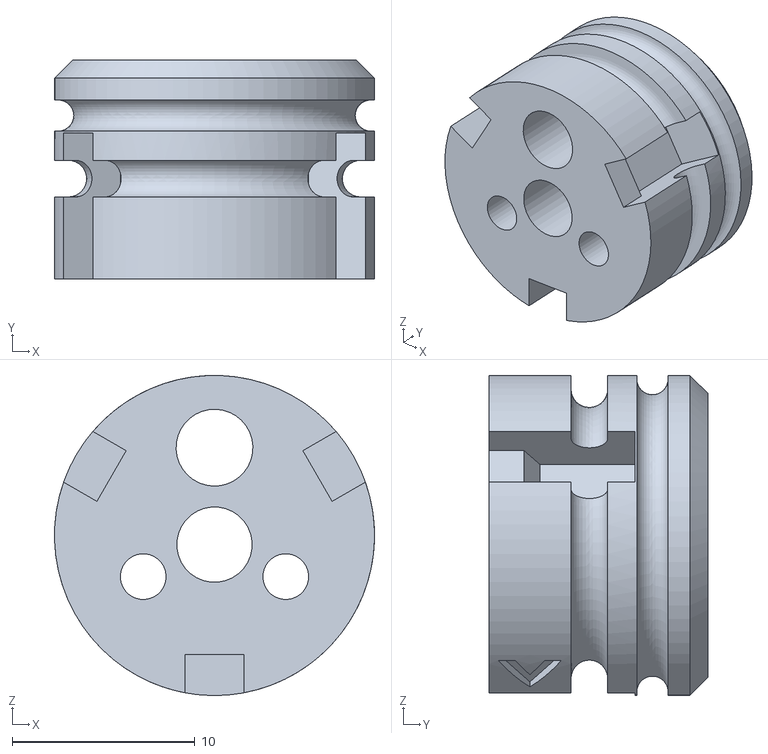
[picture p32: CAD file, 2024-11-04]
Fabrication/3DPrint_FDM/Tete_piston_2020.stl
17.5 x 12.0 x 17.5

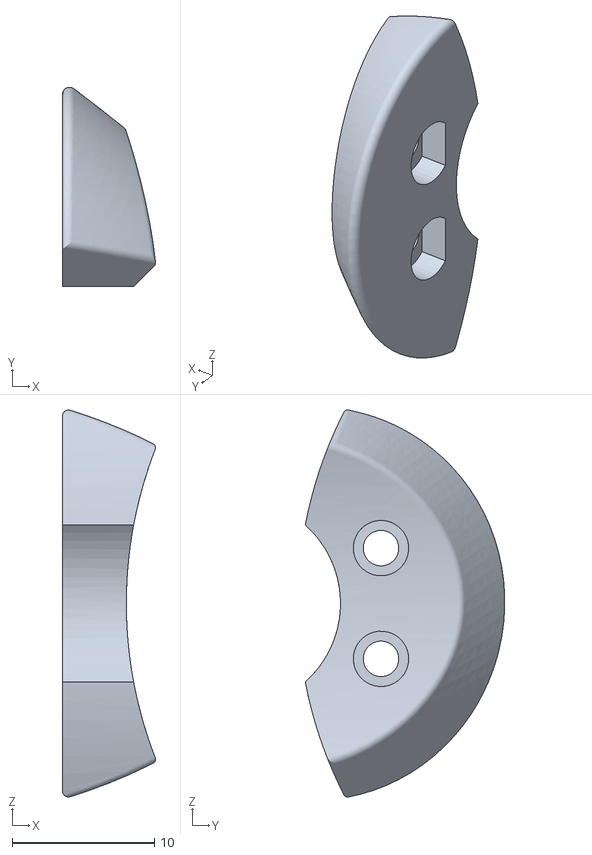
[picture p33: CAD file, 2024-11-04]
Fabrication/3DPrint_FDM/BoutonPoussoir_2020.stl
6.56 x 14.0 x 27.2

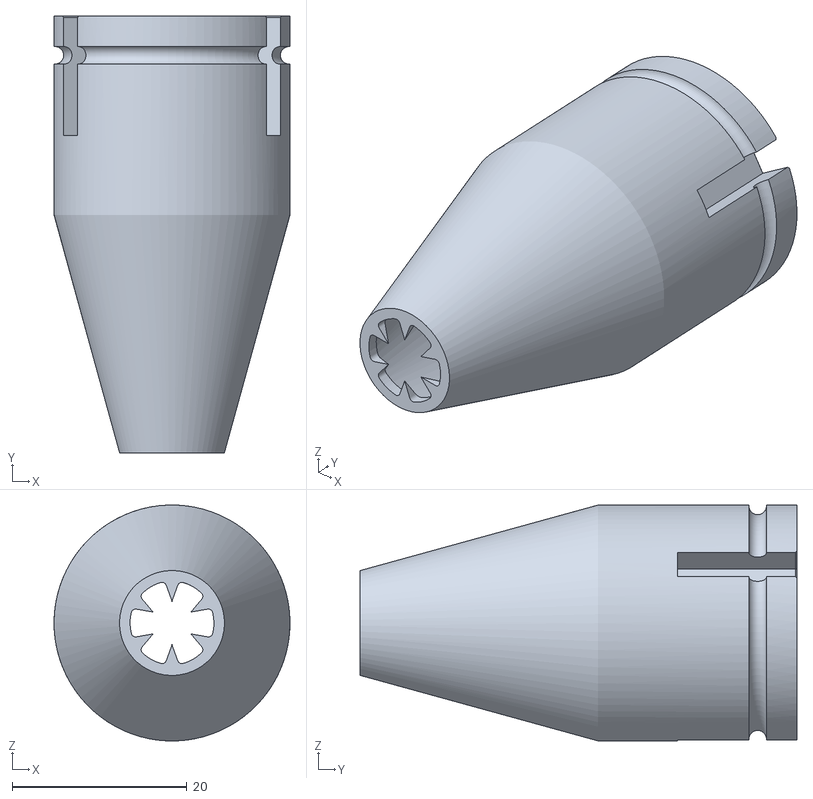
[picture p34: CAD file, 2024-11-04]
Fabrication/3DPrint_FDM/Embout_2020.stl
27.0 x 50.0 x 27.0

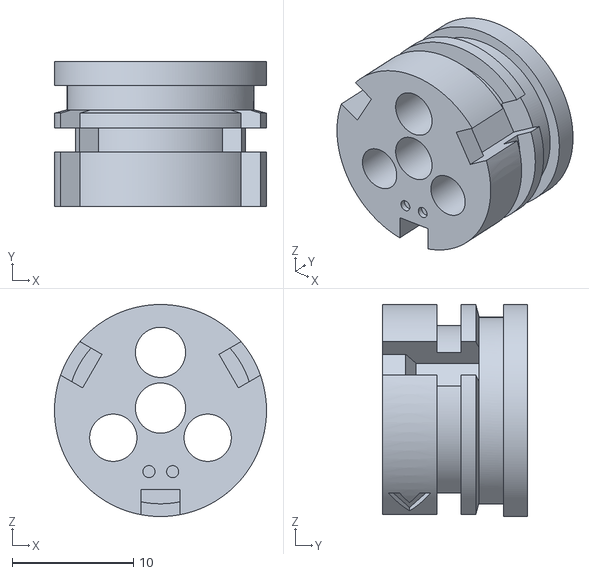
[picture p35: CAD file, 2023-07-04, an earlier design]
Fabrication/00_Archives/Impressions_3D_DLP/Tete_piston_3.9_oring_15.4_B9.stl
17.5 x 12.0 x 17.5

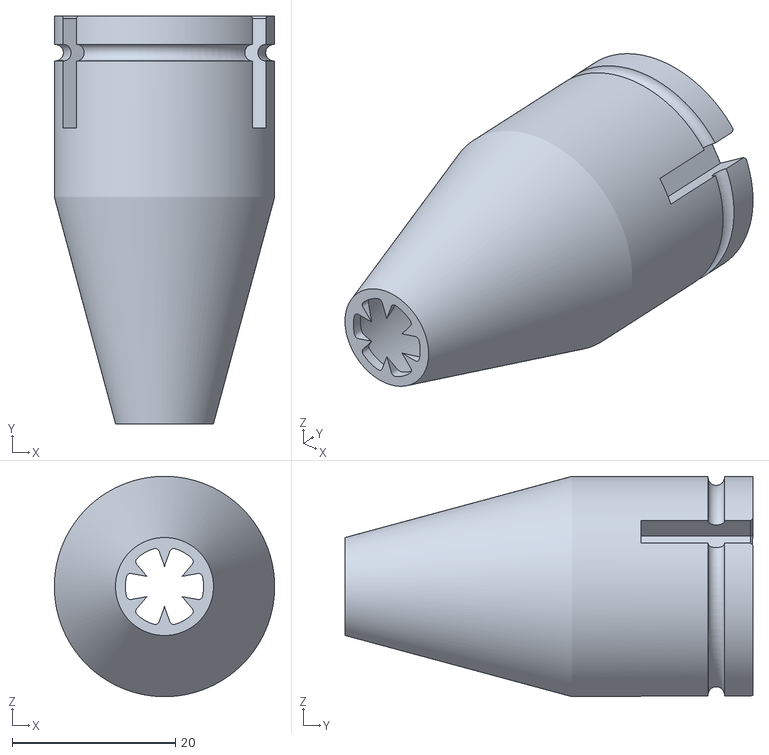
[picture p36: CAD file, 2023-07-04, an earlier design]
Fabrication/00_Archives/Impressions_3D_FDM/Embout_25.03.15.stl
27.0 x 50.0 x 27.0

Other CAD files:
Fabrication/00_Archives/Impressions_3D_FDM/BoutonPoussoir_25.03.15.stl

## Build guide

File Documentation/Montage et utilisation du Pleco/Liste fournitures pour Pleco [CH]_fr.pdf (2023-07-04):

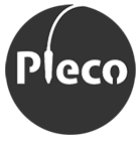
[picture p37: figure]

LISTE DES FOURNITURES POUR FABRICATION DU PLECO

## SUISSE

Distrelec | https://www.distrelec.ch
Type | Fabricant | Quantité (pour 1 Pleco) | N°article

Câble de commande sans
blindage 2 x 0.14mm2 | Kabeltronik | 1.7m | 513461
Gaine tressée 7...12mm noir | HellermannTyton | 1.4m | 506418
Fiche mâle 4mm blanc | SKS Kontakttechnik | 1 pièce | 104179
Fiche mâle 4mm brun | SKS Kontakttechnik | 1 pièce | 104177

Gaine thermo retractable 2:1 –
PVDF transparent 38.1mm x 19.1 mm x 1.2 m | HellermannTyton | 0.1m | 506820

Gaine thermo rétractable noir
19mm x 6mm x 1,2 m | TE Connectivity | 0.05m | 500094

Gaine thermo rétractable noir 6
mm x 2mm x 1,2 m | TE Connectivity | 0.05m | 500091

Gaine thermo rétractable noir
3mm x 1mm x 1.2m | Te Connectivity | 0.4m | 500090
Embout 0.34mm² / 5mm | Vogt | 6 pièces | 504239
Ruban de téflon | Fournisseur au choix | 1 pièce | 968094

Angst+Pfister | https://shop.angst-pfister.ch
Type | Fabricant | Quantité (pour 1 Pleco) | N°article

O-Ring NORMATEC NBR NT
70.11 OR 2118 DI 29,87 x | Angst+Pfister | 1 | 11.2003.0494
1,78mm
O-Ring NORMATEC NBR NT
70.11 OR 2093 DI 23,52 x
1,78mm
Angst+Pfister | 1 | 11.2003.0486

O-Ring NORMATEC NBR NT
70.11 OR 2050 DI 12,42 x
1,78mm
Angst+Pfister | 1 | 11.2003.0472

O-Ring NORMATEC NBR NT
70.11 ORM 0140-15 DI 14,00 x 1,50 mm
Angst+Pfister | 1 | 11.2003.0154

Plaque APSOplast HD-PE, noir
Epaisseur : 3 ± 0,12mm | Angst+Pfister | 0,1 x 0,2m | 01.2210.0030

Plaque APSOplast PMMA-XT,
transparent Epaisseur : 3 ± 0,15mm | Angst+Pfister | 0,07 x 0,03m | 01.2410.4030

CARL ROTH- | http://www.carlroth.com
Type | Fabricant | Quantité (pour 1 Pleco) | N°article

Tuyaux silicone Rotilabo
diamètres: int : 4mm, ext : 6mm | Rotilabo | 2m | 9566.1

Tuyaux silicone Rotilabo
diamètres: int : 2mm, ext : 4mm Rotilabo | 3.3m | 9559.1

Tuyaux silicone Rotilabo
diamètre: int : 1mm, ext : 3mm | Rotilabo | 0.1m | 9556.1

Raccord réducteur de mini-
flexibles Rotilabo (d1_int=2.4 d2_int=4 [mm]) | Rotilabo | 2 pièces | CT43.1

Raccord tubulaire mini Rotilabo
(d_int=2.4 [mm]) | Rotilabo | 2 pièces | CT34.1
HLD Clean Consult | http://www.hld.ch/
Type | Fabricant | Quantité (pour 1 Pleco) | Nomenclature produit
AION Clean Room Sponge D-3 | AION Co. | 1 (au minimum) | 39249011

Ressorts du Léman- | http://www.ressortsduléman.ch
Type | Fabricant | Quantité (pour 1 Pleco) | N°article

Ressort de compression:

De (diamètre extérieur en [mm])=5.33
D(diamètre du fil en [mm])=0.56 Lo (longueur libre en [mm])=17.53 Lc (longueur de compression max en [mm])=8.79 Fn(charge max en [N])=11.52 C(constante raideur en [N/mm])=1.31 | Ressort du Léman | 2 pièces | C02100220690M
Emballage (KIT) | Brieger (www.brieger.ch)
Type | | Quantité (pour 1 Pleco) | N°article
Sachet 12x18 cm | Brieger | 2 pièces | 77115
Sachet 10x15 cm | Brieger | 4 pièces | 77114
Sachet 6x8 cm | Brieger | 5 pièces | 77110

Boîte à montage rapide, brun,
Economy 232x165x60cm | Brieger | 1 pièce | 533/60

Quincaillerie | Kaufmann, la Chaux-de-Fonds
Type | Fabricant | Quantité (pour 1 Pleco) | N°article (chez Kauffman)

Vis M3 x 8mm à tête bombée à
6 pans creux, inox, BN 1593 | Bossard | 5 pièces | 3-00026226

Vis M3 x 10mm à tête bombée
à 6 pans creux, inox, BN 1593 | Bossard | 5 pièces | 3-00026227

Vis M2 x 8mm à tête
cylindrique avec fente, inox, | Bossard | 4 pièces | 3-0024595
bleu BN650
Vis M1.2 x 3 mm à tête
cylindrique avec fente, inox a,
BN 650
| Bossard | 4 pièces | 3-00026691

Ecrou hexagonal M3 (5,5 x 2,4
mm), inox, BN628 | Bossard | 8 pièces | 3-00024410

Colliers d’épaulement pour
arbres 2.3, inox, BN679 | Bossard | 4 pièces | 3-00025386
Rond plein laiton massif 4mm | - | 0.2m | 3-00253071

## Caran d’Ache

Sur demande auprès de la HE-Arc CR ou en ligne sur http://www.cultpens.com/i/q/CD02739/caran-dachereplacement-clutch-for-fixpencil (http://www.cultpens.com/i/q/CD02739/caran-dache-replacement-clutch-for-fixpencil)

Type | Fabricant | Quantité (pour 1 Pleco) | N°article
Mandrins pour fixpencil 2mm | Caran d’ache | 2 pièces | Non communiqué

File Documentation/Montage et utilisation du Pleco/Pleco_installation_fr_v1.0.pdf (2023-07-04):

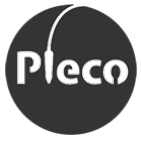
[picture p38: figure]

NOTICE D’INSTALLATION DU PLECO
www.fablab-neuch.ch/pleco

# Notice d’installation du Pleco

A. Liste du matériel requis pour le fonctionnement

Matériel et consommables nécessaires au Pleco

- Pleco monté.
- 1 électrode en carbone vitreux Metrohm® (tige : L 76mm et Ø 2mm) servant d’électrode de référence,
- 1 contre-électrode en platine (tige : L 40mm et Ø 2mm),
- 1cm de tuyau silicone, Øext 3mm et Øint 1mm, servant de joint d’étanchéité au niveau des électrodes,
- 1 éponge microporeuse en PVFM AION® (Clean Room Sponge D-3) pour la découpe des tampons.

Matériel nécessaire aux traitements électrolytiques
- 1 générateur de courant (potentiostat ou alimentation stabilisée),
- 1 système de contrôle du potentiel (boîtier de contrôle « Pleco » ou multimètre),
- 1 multiprise (min. 4 branchements perpendiculaires à la longueur du boitier), une pince crocodile, feuille d’aluminium et câbles électriques de laboratoire.

Eléments annexes

- pHmètre et conductimètre,
- 1 électrode de référence Ag-AgCl pour le contrôle de l’électrode en carbone vitreux,
- 1 multimètre de forte impédance,
- 1 statif de laboratoire ou support Pleco.

Matériel nécessaire à la circulation d’électrolyte

- 2 pompes doseuses à membrane SIMDOS 10 de chez ®KNF, modèle FEM 1.10KT (une pour l’amenée et une pour l’extraction de l’électrolyte),
- 2 filtres en-ligne FS 25T de chez ®KNF (liés aux pompes),
- 2m de tuyau silicone, Øext 6mm et Øint 4mm (Liaison Pleco → Pompes et Pompes → Réservoir),
- 5cm de tuyau en polyéthylène, Øext 6mm et Øint 4mm (Liaison filtre → Entrées des pompes),
- 1 bécher de récupération de l’épanchement de l’électrolyte à prévoir sous le support.

# Notice d’installation du Pleco

B. Préparation de l’électrolyte (solution 1% - en masse - de nitrate de sodium tamponné)

Pour une solution de 1L :
1. Préparer un litre d’eau deionisée ou distillée.
2. Préparer la quantité nécessaire de nitrate de sodium (1% - en masse).
- Peser 10g de nitrate de sodium et le mélanger à la solution.

### 3. Préparer la quantité nécessaire pour le tampon 10⁻⁴

M d’acétate de sodium et l’ajouter à la solution :
- Peser 0,0136g d’acétate de sodium trihydraté (préparation nécessitant l’utilisation d’une balance de laboratoire) et le mélanger à la solution.
-Insérer 0,1mL d’une solution 1M d’acide acétique dans la solution (d’où une dilution au final de 10 000 fois) et mélanger.

### 4. Contrôler la solution (valeurs attendues : pH 4,75 (+/- 0.5¹

) et conductivité 11,6mS/cm (+/- 0.5))
- Rincer les appareils avec de l’eau déionisée,
- Calibrer le pH-mètre et le conductimètre selon indication du fabricant,
- Vérifier le pH et la conductivité de l’eau deionisée (valeurs attendues : pH 6 (+/-1), conductivité <10µS/cm). Même chose avec la solution de nitrate de sodium tamponnée,
- Rincer les appareils avec de l’eau deionisée et les sécher en les tamponnant avec du papier absorbant.
C. Contrôle de l’électrode de carbone vitreux

### 1. S’assurer que l’électrode de référence de contrôle Ag-AgCl fonctionne correctement

(potentiel attendu autour de 210mV/ENH) avec une autre électrode Ag-AgCl de contrôle par comparaison de leur potentiel respectif en eau de ville.

### 2. Brancher les deux électrodes à un multimètre de forte impédance à l’aide des câbles de

laboratoire. L’électrode en carbone vitreux est connectée sur la sortie V et l’électrode de référence Ag-AgCl sur la sortie COM.
3. Changer l’eau de ville utilisée au point 1 pour la solution tamponnée de nitrate de sodium. Noter la différence de potentiel entre les deux électrodes qui doit décroître pour se stabiliser autour de +30 à +80mV. Cette valeur doit être inscrite dans un tableau afin d’appréhender d’éventuelles défectuosités de l’électrode en carbone vitreux. A noter que le potentiel de l’électrode en carbone vitreux (par rapport à ENH) doit également être inséré dans le logiciel de corrosion du potentiostat lors des tracés Ecorr vs temps et voltammétriques.

1 La valeur du pH dépend du pH de l’eau déionisée. Il est important de s’assurer que l’eau utilisée est correctement deionisée.

# Notice d’installation du Pleco

4. Rincer l’électrode de référence Ag-AgCl et la ranger dans sa boîte d’emballage.
5. Conserver l’électrode en carbone vitreux pour l’insérer dans le pinceau électrolytique (se référer à la section G3).
D. Rinçage et mise en forme des tampons
1. Déballer l’éponge microporeuse en PVFM (AION® Clean Room Sponge D-3, 125x85x35mm), normalement conservée humide dans une enveloppe en plastique étanche.
2. Rincer l’éponge afin d’éliminer toute substance biocide utilisée pour son conditionnement.
- L’éponge doit être rincée 5 fois dans des bains renouvelés d’eau déionisée. Pour chaque bain, l’éponge est pressée régulièrement pendant 5 minutes afin d’extraire le maximum de substances biocides. Entre chaque étape la mousse est rincée et à nouveau pressée sous eau déionisée courante.
- Un contrôle du pH de l’eau deionisée avant/après rinçage, permet de contrôler le bon rinçage de l’éponge.

### 3. Une fois rincée l’éponge doit être conservée sèche pour éviter un développement de

moisissure.

### 4. Débiter la mousse en petits morceaux :

- Humidifier l’éponge à l’eau deionisée,
- Découper aux ciseaux une bande de 12-15mm environ dans la largeur de l’éponge,
- Découper le long de cette bande des éléments de 12mm environ de large. Leur dimension est à peu près 12x12x35mm.
- Pour terminer, découper en deux parts égales ces éléments pour obtenir des petits blocs de mousse d’une dimension de 12x12x17mm environ servant ainsi d’ébauche pour la mise en forme des tampons.

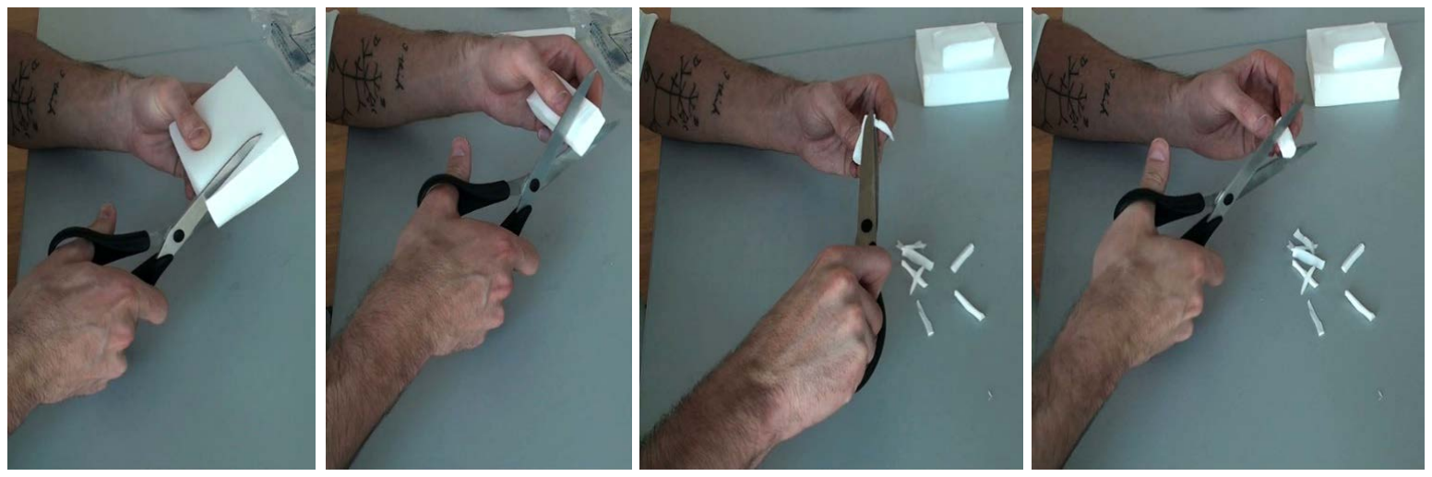
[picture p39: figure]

# Notice d’installation du Pleco

### 5. Mettre en forme un tampon :

- Si le tampon n’est pas humidifié, le faire
tremper dans l’eau déionisée,
- Tailler le tour du tampon au ciseau de sorte à fabriquer un cylindre de 10mm de diamètre,
- Tailler un arrondi à l’une des extrémités du tampon (hauteur d’environ un tiers à la moitié de la longueur totale).
- Pratiquer une fente sur le plat de l’autre
extrémité du cylindre pour l’insertion des
électrodes.

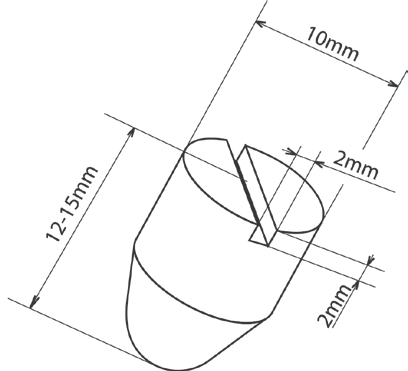
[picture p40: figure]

Astuce : Pour cela, réaliser deux incisions d’une profondeur de 2mm environ et distantes de 2mm, au milieu de la surface plane. Venir ensuite découper la languette formée en écartant avec les doigts les deux côtés du cylindre pour y glisser les ciseaux.

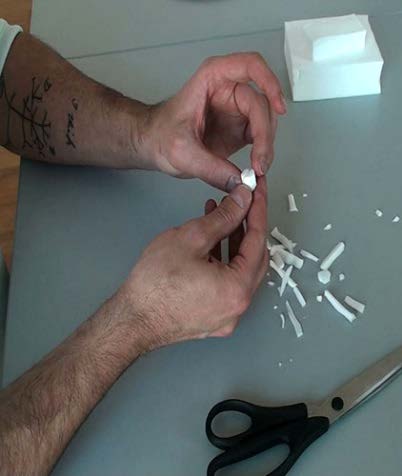
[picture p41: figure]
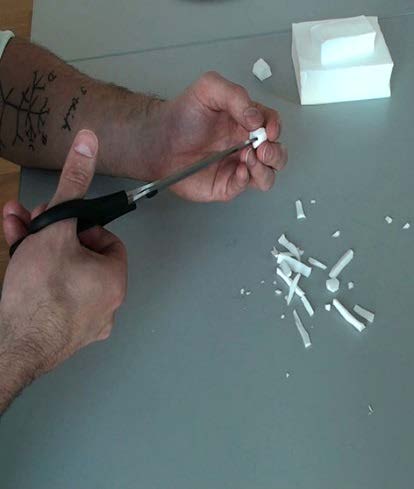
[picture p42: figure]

Voir vidéo de la découpe des tampons: http://www.fablab-neuch.ch/pleco/plus.php?id=17 .

### 6. Insérer le tampon humidifié dans l’embout en le compressant légèrement pour permettre

son insertion.

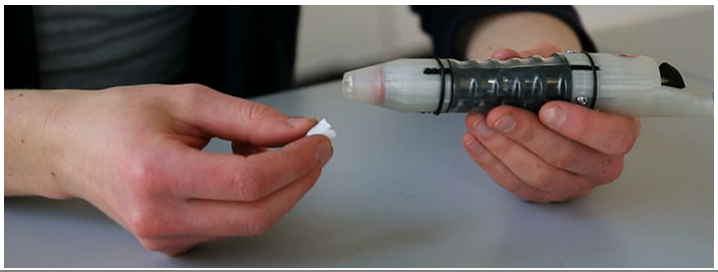
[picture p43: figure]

# Notice d’installation du Pleco

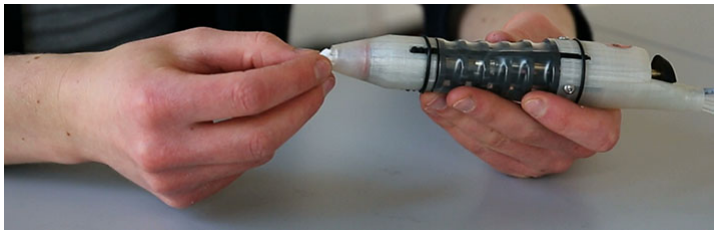
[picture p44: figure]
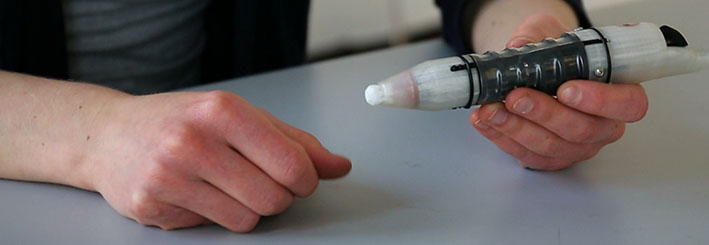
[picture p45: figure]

Voir vidéo de la notice de montage du Pleco: http://www.fablab-neuch.ch/pleco/plus.php?id=17 .

E. Branchement électrique pour un traitement cathodique
1. Disposer sur le plan de travail votre matériel.
2. Brancher la multiprise sur le secteur.
3. Brancher le câble d’alimentation du générateur de courant.

### 4. Brancher le câble d’alimentation du système de contrôle du potentiel ou de votre

multimètre (ou vérifier que la pile de ce dernier n’est pas usée).

### 5. Connecter l’électrode de travail et la contre-électrode:

- Brancher la fiche banane connectée à la contre-électrode du PLECO (fiche brune) dans la fiche + du générateur de courant ou la connexion CE (contre-électrode) du potentiostat. Si le fil est trop court vous pouvez utiliser un câble de laboratoire supplémentaire comme rallonge,
- Brancher un câble de laboratoire dans la fiche - du générateur ou la connexion WE (working electrode) ou ET (électrode de travail) du potentiostat. L’autre extrémité est connectée à une pince crocodile, elle-même reliée à l’objet à traiter. Une feuille d’aluminium repliée sur elle-même est placée entre la pince crocodile et l’objet afin d’éviter tout dommage mécanique de ce dernier.
Astuce : S’il n’est pas possible de fixer la pince crocodile sur l’objet vous pouvez préparer la feuille d’aluminium de sorte à créer une languette que vous insérerez dans

# Notice d’installation du Pleco

un interstice ou que vous pourrez maintenir sur la surface par une bande adhésive. Attention à bien nettoyer la zone à l’éthanol pour ne pas laisser de colle en surface. Il faut aussi éviter d’utiliser une bande adhésive sur une zone prétraitée pour ne pas laisser de marque.

### 6. Brancher le système de contrôle du potentiel/multimètre:

- Brancher la fiche banane connectée à l’électrode de référence du PLECO (fiche blanche) dans l’entrée COM ou REF du système de contrôle du potentiel/multimètre,
- Brancher un câble électrique de laboratoire dans le port V du système de contrôle du potentiel/multimètre. Brancher l’autre extrémité au dos de la fiche banane qui sera connectée à l’objet (là où vous avez branché la pince crocodile). Ce branchement vous permet de mesurer avec le boîtier de contrôle/multimètre le potentiel de votre objet par rapport à votre électrode de référence.

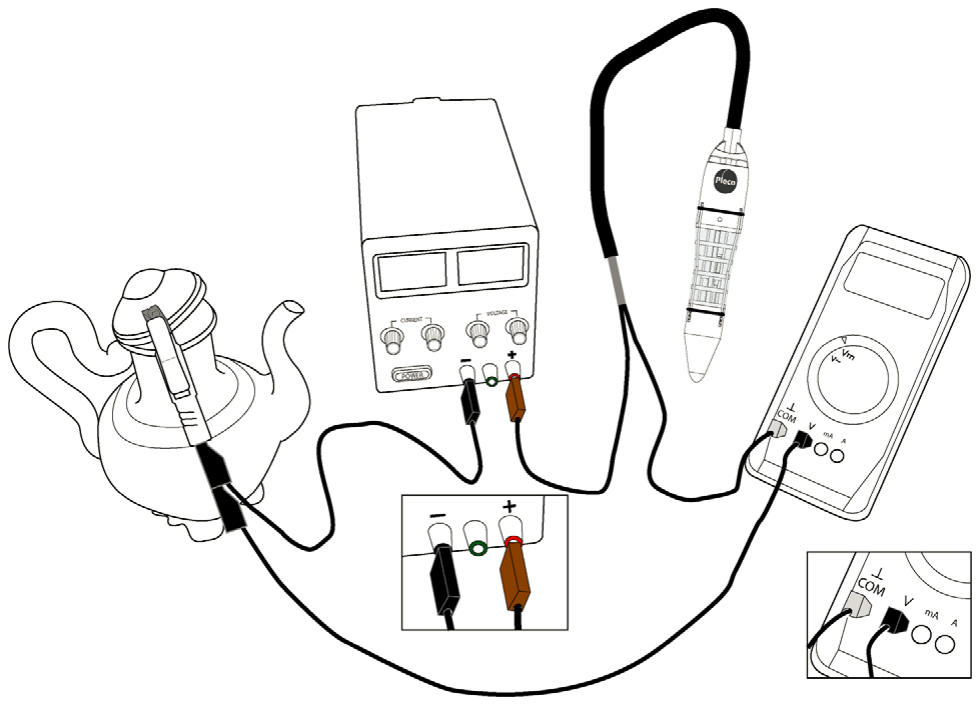
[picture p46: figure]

## F. Branchement électrique pour un traitement anodique

1. Disposer sur le plan de travail votre matériel,
2. Brancher la multiprise sur le secteur,

### 3. Brancher le câble d’alimentation du système de contrôle du potentiel ou de votre

multimètre (ou vérifier que la pile de ce dernier n’est pas usée),
4. Brancher le câble d’alimentation du système de contrôle du potentiel/multimètre,

# Notice d’installation du Pleco

### 5. Connecter l’électrode de travail et la contre-électrode:

- Brancher la fiche banane connectée à la contre-électrode du PLECO (fiche brune) dans la fiche - du générateur ou la connexion WE (working electrode) ou ET (électrode de travail) du potentiostat. Si le fil est trop court vous pouvez utiliser un câble de laboratoire supplémentaire comme rallonge,
- Brancher un câble de laboratoire dans la fiche + du générateur de courant ou la connexion CE (contre-électrode) du potentiostat. L’autre extrémité est connectée à une pince crocodile, elle-même reliée à l’objet à traiter. Une feuille d’aluminium repliée sur elle-même est placée entre la pince crocodile et l’objet afin d’éviter tout dommage mécanique de ce dernier.
Astuce : s’il n’est pas possible de fixer la pince crocodile sur l’objet vous pouvez préparer la feuille d’aluminium de sorte à créer une languette que vous insérerez dans un interstice ou que vous pourrez maintenir sur la surface par une bande adhésive. ! Attention à bien nettoyer la zone à l’éthanol pour ne pas laisser de colle en surface. Il faut aussi éviter d’utiliser une bande adhésive sur une zone déjà prétraitée pour ne pas laisser de marque.

### 6. Brancher le système de contrôle du potentiel/multimètre :

- Brancher la fiche banane connectée à l’électrode de référence du PLECO (fiche blanche) dans l’entrée COM ou REF du système de contrôle du potentiel/multimètre,
- Brancher un câble électrique de laboratoire dans le port V du système de contrôle du potentiel/multimètre. Brancher l’autre extrémité au dos de la fiche banane qui sera connectée à l’objet (là ou vous avez branché la pince crocodile). Ce branchement vous permet de mesurer avec le boîtier de contrôle/multimètre le potentiel de votre objet par rapport à votre électrode de référence.
G. Préparation et montage des électrodes
1. Monter le joint d’étanchéité en silicone sur la contre électrode (tige en platine).
- Découper une longueur de 5mm dans le tuyau en silicone (Øext 3mm, Øint 1mm),
- Enduire la tige de platine d’eau savonneuse pour faciliter l’insertion du joint,
- Insérer le joint silicone en laissant sous celui-ci une distance de 8 à 10mm. Ce montage nécessite d’appliquer une certaine force et peut prendre quelques minutes. Attention, à ne pas déchirer le joint lors de l’insertion.

### 2. Monter le joint d’étanchéité en silicone sur l’électrode de référence (tige de carbone

vitreux).
- Découper une longueur de 5mm dans le tuyau en silicone (Øext 3mm, Øint 1mm),
- Enduire l’électrode de carbone vitreux d’eau savonneuse pour faciliter l’insertion du joint,
- Insérer le joint silicone en laissant sous celui-ci une distance de 8 à 10mm. Ce montage nécessite d’appliquer une certaine force et peut prendre quelques minutes. Il faut faire très attention à ne pas briser l’électrode en carbone vitreux très fragile !

# Notice d’installation du Pleco

### 3. Retirer l’embout du Pleco pour avoir accès à la tête du piston et insérer les

électrodes :
- Insérer l’électrode de platine. Pour cela, presser sur le bouton de la cloche du Pleco, ce qui vous permet d’ouvrir le mandrin du support d’électrode le plus long. Soigneusement, insérer l’électrode au travers de la tête du piston jusqu’au mandrin, l’extrémité basse du joint en silicone arrivant au ras de la tête du piston. L’électrode dépasse ainsi de 8 à 10mm,
- Insérer l’électrode de référence (carbone vitreux) juste après son contrôle (voir section C). Attention, l’électrode de référence est très fragile ! Pour cela, presser sur le bouton de la cloche du Pleco, ce qui vous permet d’ouvrir le mandrin du support d’électrode le plus court. Soigneusement, insérer l’électrode au travers de la tête du piston jusqu’au mandrin, l’extrémité basse du joint en silicone arrivant au ras de la tête du piston. L’électrode dépasse donc de 8 à 10mm.
H. Branchement hydraulique
1. Brancher les câbles d’alimentation à l’arrière des deux pompes à membranes.

### 2. Dévisser les bagues filetées (deux par pompe) pour retirer les bouchons de protection

noirs que vous mettrez de côté afin de ne pas les égarer.

### 3. Découper le tuyau en polyéthylène (PE) de 5cm (Øext 6mm ; Øint 4mm) en deux sections

de même longueur.
4. Glisser sur les deux sections du tuyau en PE (1) les bagues filetées (2) et les collerettes
(3) correspondantes selon le schéma suivant :

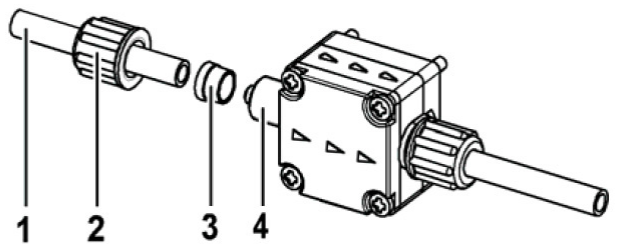
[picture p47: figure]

5. Insérer ces deux sections sur les entrées des pompes d’amenée et d’extraction jusqu’à la butée (4).
6. Revisser les bagues filetées correspondantes aux entrées des deux pompes.

### 7. Insérer un filtre en-ligne sur l’entrée des tuyaux en PE précédemment fixés sur les

pompes.

### 8. Brancher un tuyau silicone (Øext 6mm ; Øint 4mm ; L 75mm) pour l’amenée de

l’électrolyte entre le réservoir et le filtre de la pompe d’amenée.

### 9. Brancher un tuyau silicone (Øext 6mm ; Øint 4mm ; L 20mm) pour l’amenée de

l’électrolyte entre la sortie de la pompe d’amenée et le rapport réducteur – ou connecteur hydraulique (sur tube d’amenée du Pleco). Pour le branchement sur la pompe se rapporter aux points H2 à H5.
10.Brancher un tuyau silicone (Øext 6mm ; Øint 4mm; L 20mm) pour l’extraction de l’électrolyte entre le deuxième rapport réducteur – ou connecteur hydraulique (sur tube d’extraction du Pleco) et le filtre de la pompe d’extraction.

©KNF

# Notice d’installation du Pleco

11.Brancher un tuyau silicone (Øext 6mm ; Øint 4mm ; L 75mm) pour l’extraction de l’électrolyte entre la sortie de la pompe d’extraction et le réservoir. Pour le branchement sur la pompe se rapporter aux points H2 à H5.

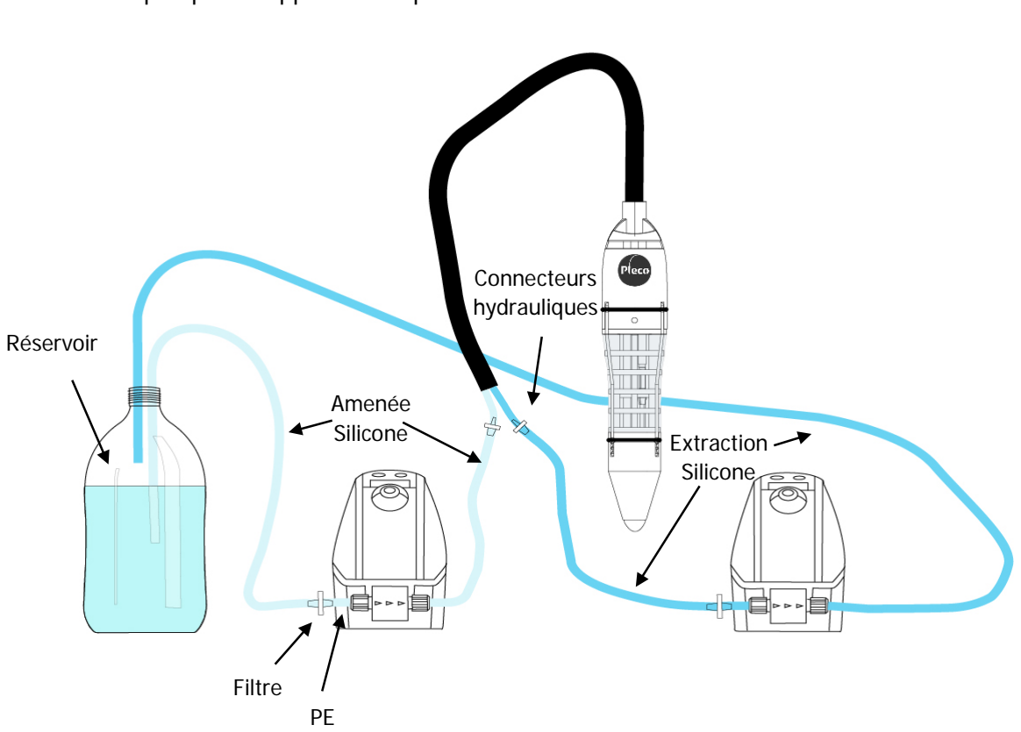
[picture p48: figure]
Filtre; Amenée Silicone; Connecteurs hydrauliques; Extraction Silicone; Réservoir

Vidéo du branchement hydraulique et électrique: http://www.fablab-neuch.ch/pleco/plus.php?id=17 .

I. Amorçage des pompes et réglage du débit de l’électrolyte

(Pour l’utilisation détaillée des pompes à membranes, le mode d’emploi du fournisseur est disponible en téléchargement sur le site internet de KNF). (http://www.knf.ch/?eID=downloadDialog)

### 1. Mise en route des pompes à membrane en maintenant une pression sur la touche

« mise sous tension » pendant 2-3 secondes.

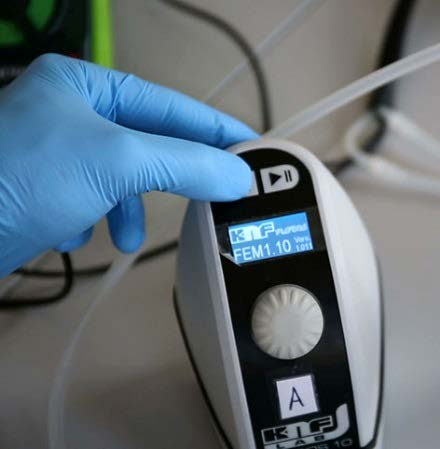
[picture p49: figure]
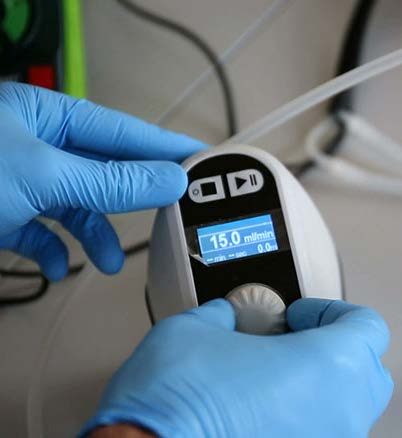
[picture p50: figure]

# Notice d’installation du Pleco

### 2. La première fois que vous utilisez les pompes, prérégler le débit de la pompe d’amenée

à 15mL/min en utilisant la molette de contrôle.
- En tournant la molette on peut parcourir le menu,
- Par pression on sélectionne le paramètre à modifier,
-Ensuite, en tournant à nouveau la molette on modifie le paramètre ou la valeur,
- Pour terminer on valide la modification par une nouvelle pression sur la molette.
3. De manière similaire, prérégler le débit de la pompe d’extraction à 30mL/min.
4. Amorcer les deux pompes simultanément.
- Placer un bécher de récupération sous le pinceau en raison du risque d’épanchement de la solution,
- Présélectionner le champ « Amorcer » puis presser sur la molette pour remplir les tuyaux,
- Le système est amorcé lorsque le tube d’extraction relâche l’électrolyte dans le réservoir.

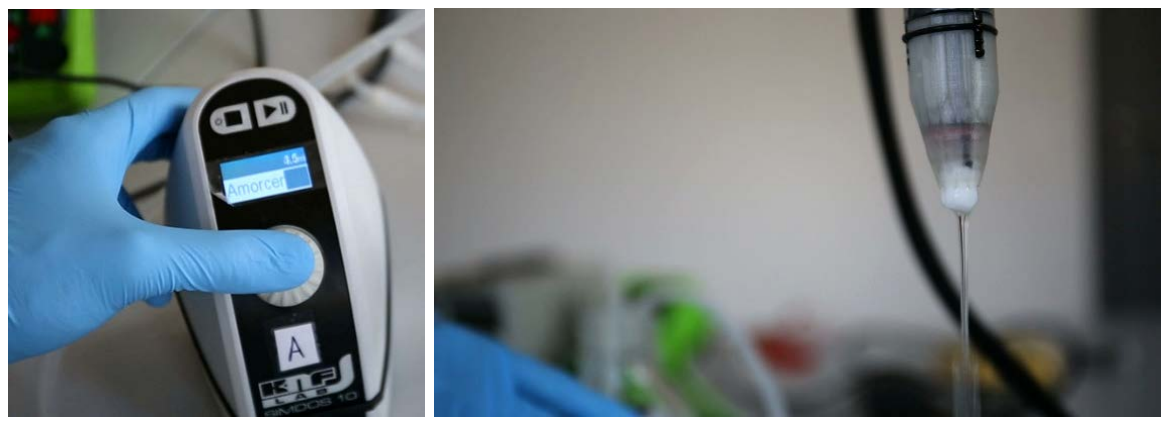
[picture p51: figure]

### 5. Une fois le système amorcé, il convient de régler l’équilibre amenée/extraction pour

que l’électrolyte imbibe suffisamment le tampon tout en évitant l’épanchement. L’état d’équilibre est atteint lorsque l’électrolyte « pulse » dans le tampon sans couler.
- Enclencher les pompes en appuyant sur le bouton « démarrer »,
- En fonction de l’humidification du tampon (trop sec, stable ou épanchement), il faut modifier les valeurs de débits des deux pompes afin d’atteindre un état stable,
- Pour s’assurer que l’état d’équilibre est atteint, il est conseillé de venir appuyer avec une plaquette métallique ou avec le doigt pour s’assurer qu’en mode dynamique de nettoyage (par déplacement du Pleco) le liquide ne s’épanche pas.

Voir vidéo de l’amorçage des pompes et réglage du débit de l’électrolyte : http://www.fablab-neuch.ch/pleco/plus.php?id=17 .

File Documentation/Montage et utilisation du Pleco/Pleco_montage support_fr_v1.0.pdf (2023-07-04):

### NOTICE DE MONTAGE DU SUPPORT DU PLECO

www.fablab-neuch.ch/pleco

# Notice de montage du support du Pleco

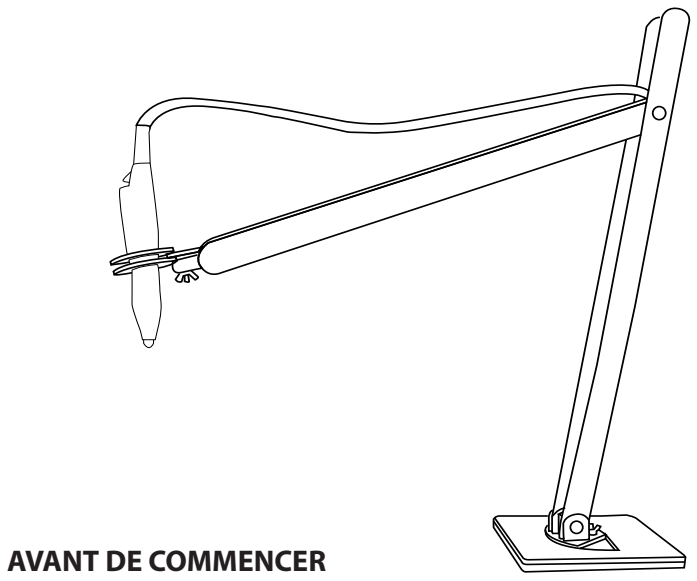
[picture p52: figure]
AVANT DE COMMENCER

Ce support adapté du Pleco a été réalisé afin d’améliorer le confort d’utilisation de ce dernier. Il est conçu selon la même philosophie que celle suivie pour fabriquer le Pleco (http://www.fablab-neuch.ch/pleco/plus.php?id=4).

Le support est entièrement réalisé à l’aide d’une découpe laser. Plusieurs assemblages consistent en des pièces emboitées et chassées les unes dans les autres. Ainsi, il faudra régulièrement appliquer une force importante pour assembler les différentes parties. Un marteau peut même s’avérer nécessaire.

### ASSEMBLAGE CENTRE - page 6

### BAGUE -

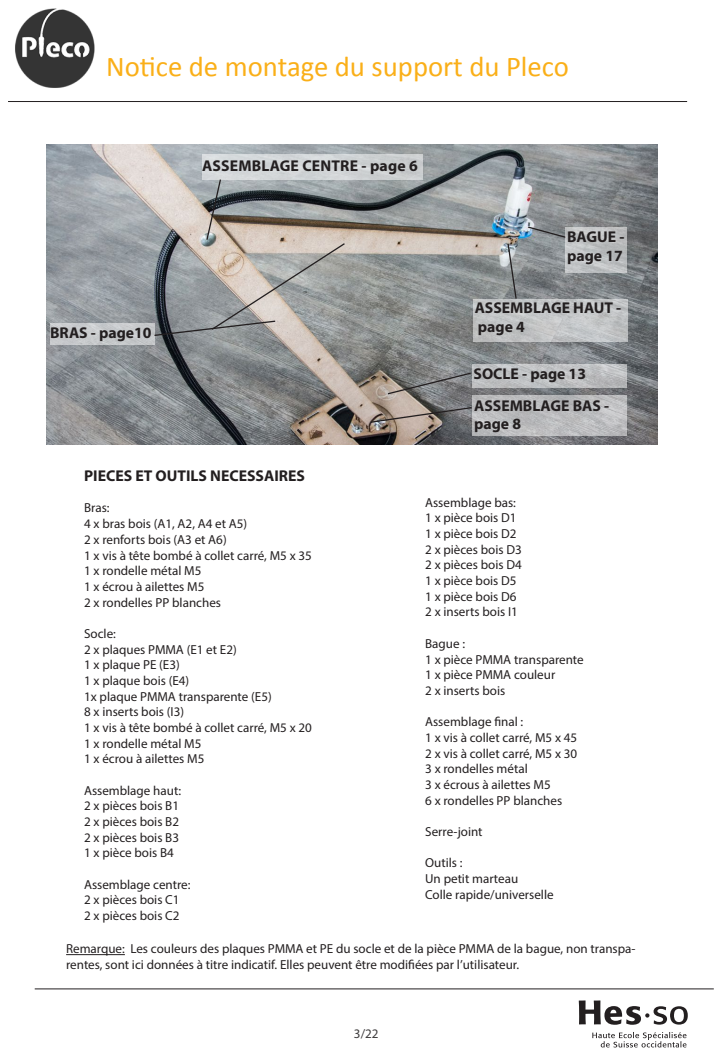
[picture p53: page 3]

PIECES ET OUTILS NECESSAIRES

Bras:
4 x bras bois (A1, A2, A4 et A5)
2 x renforts bois (A3 et A6)
1 x vis à tête bombé à collet carré, M5 x 35
1 x rondelle métal M5
1 x écrou à ailettes M5
2 x rondelles PP blanches

Socle:
2 x plaques PMMA (E1 et E2)
1 x plaque PE (E3)
1 x plaque bois (E4)
1x plaque PMMA transparente (E5)
8 x inserts bois (I3)
1 x vis à tête bombé à collet carré, M5 x 20

Remarque: Les couleurs des plaques PMMA et PE du socle et de la pièce PMMA de la bague, non transpa-
rentes, sont ici données à titre indicatif. Elles peuvent être modifiées par l’utilisateur.

### 1. MONTAGE DE L’ASSEMBLAGE HAUT

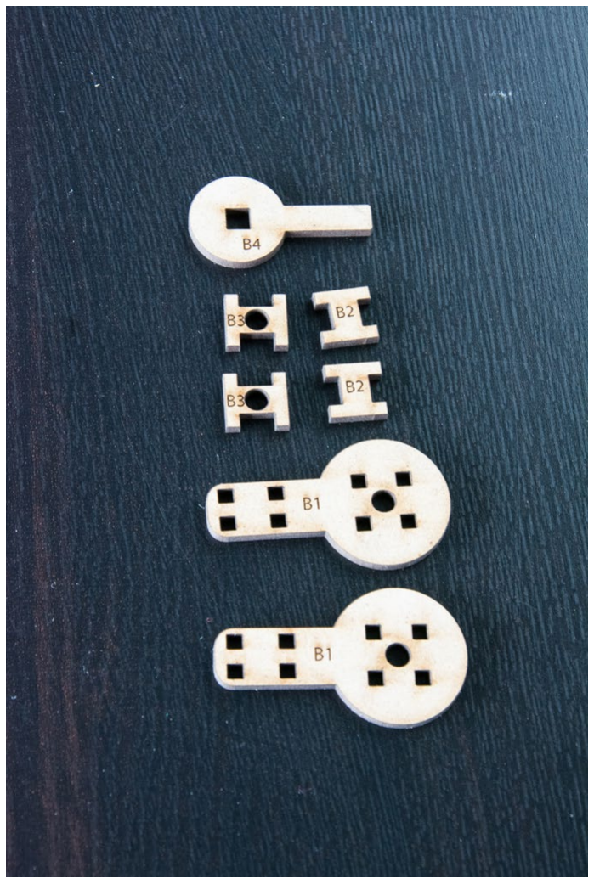
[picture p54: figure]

Dans le sachet « assemblage haut » :

2 x pièces bois B1
2 x pièces bois B2
2 x pièces bois B3
1 x pièce bois B4

### 1. MONTAGE DE L’ASSEMBLAGE HAUT

1.1
Chasser les 2 pièces B2 et les deux pièces B3 dans une des pièces B1.

1.2

Chasser la seconde pièce B1 sur l’ensemble précédent jusqu’à ce que le tout soit bien emboîté.

Astuce:

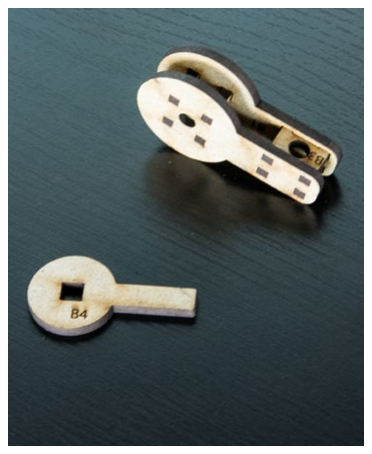
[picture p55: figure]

La découpe laser engendre une légère différence dimensionnelle entre le recto et le verso des pièces. Veillez à ce que les assemblages se fassent toujours du côté de la face marquée des différentes pièces.

### 2. MONTAGE DE L’ASSEMBLAGE CENTRE

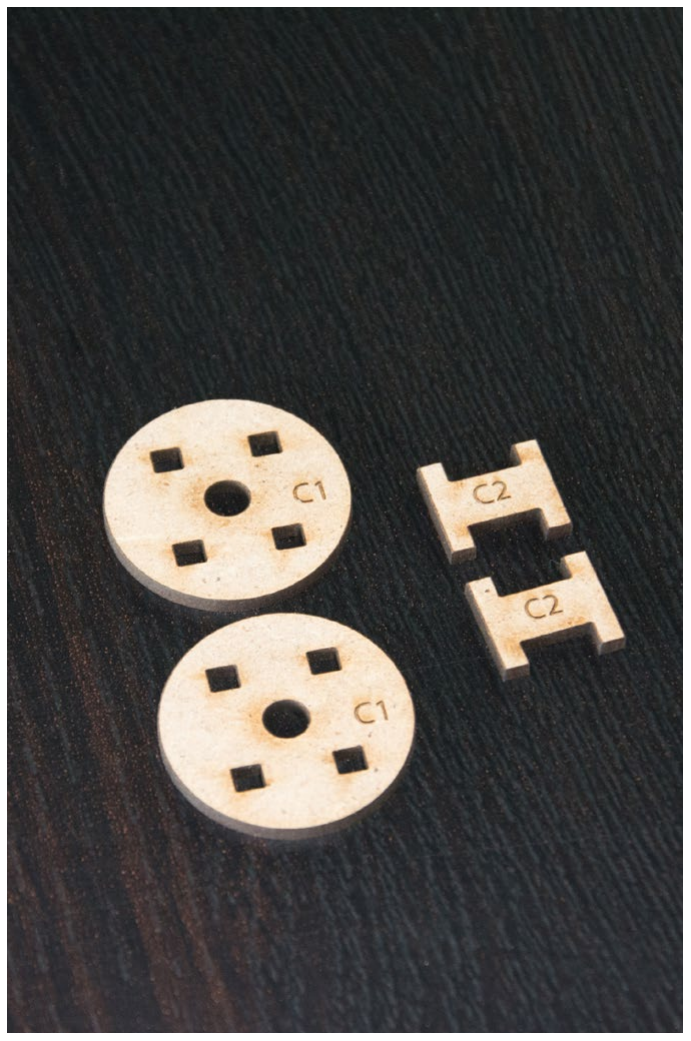
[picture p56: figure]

Dans le sachet « assemblage centre » :

2 x pièces bois C1
2 x pièces bois C2

### 2. MONTAGE DE L’ASSEMBLAGE CENTRE

2.1
Chasser les 2 pièces C2 dans une pièce C1.

2.2
Chasser la seconde pièce C1 sur l’ensemble précédent jusqu’à ce que le tout soit bien emboîté.

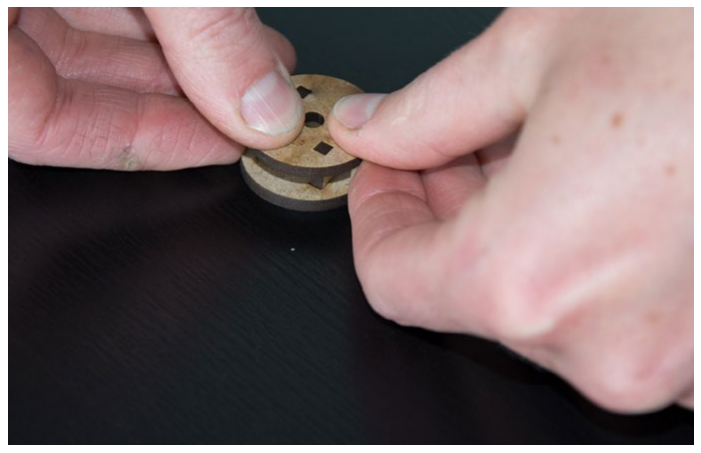
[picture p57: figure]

### 3. MONTAGE DE L’ASSEMBLAGE BAS

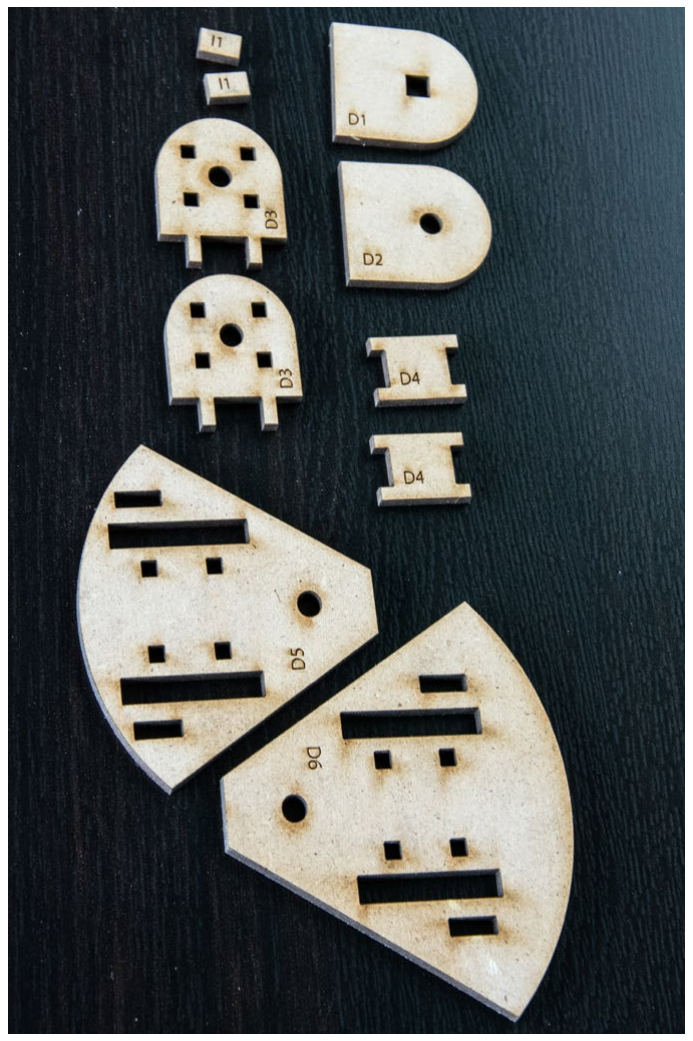
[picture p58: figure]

Dans le sachet « assemblage bas » :

1 x pièce bois D1
1 x pièce bois D2
2 x pièces bois D3
2 x pièces bois D4
1x pièce bois D5
1x pièce bois D6
2 x inserts bois I1

### 3. MONTAGE DE L’ASSEMBLAGE BAS

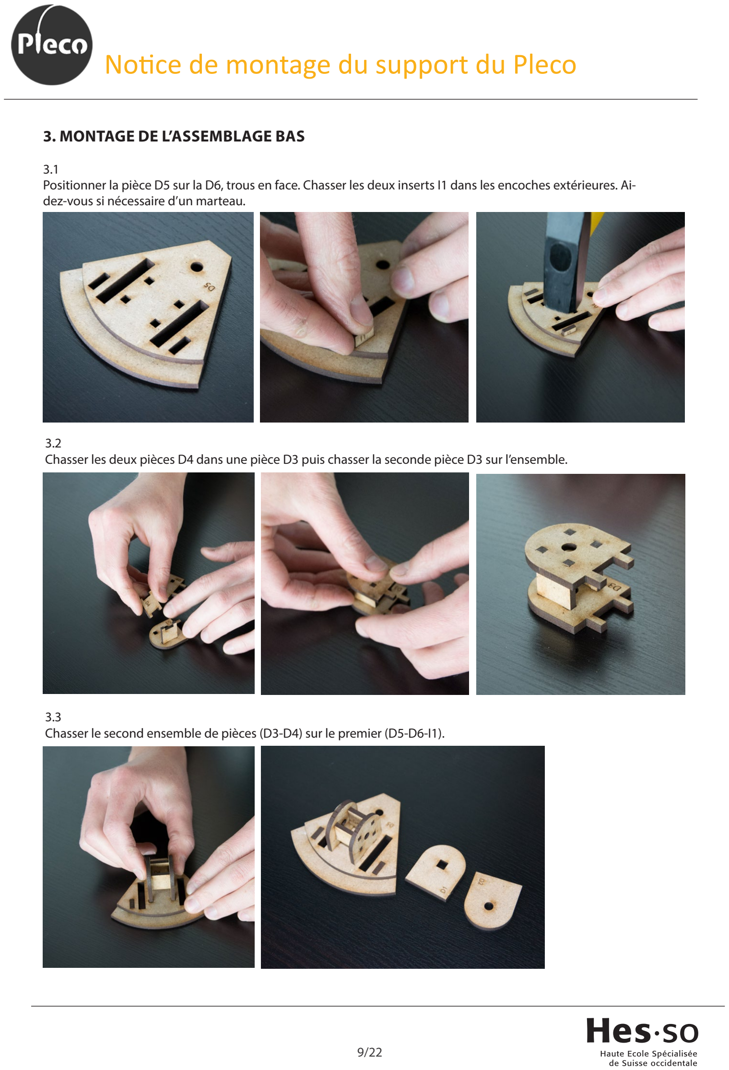
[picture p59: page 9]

3.1
Positionner la pièce D5 sur la D6, trous en face. Chasser les deux inserts I1 dans les encoches extérieures. Ai-dez-vous si nécessaire d’un marteau.

3.2
Chasser les deux pièces D4 dans une pièce D3 puis chasser la seconde pièce D3 sur l’ensemble.

3.3
Chasser le second ensemble de pièces (D3-D4) sur le premier (D5-D6-I1).

### 4. MONTAGE DU BRAS

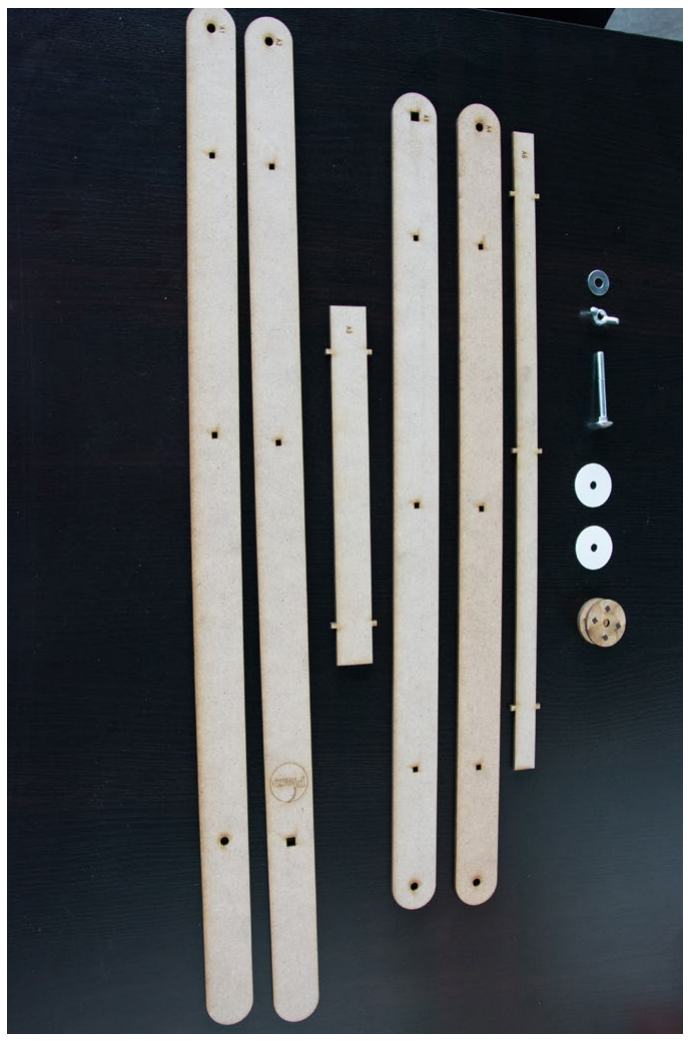
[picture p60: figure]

Dans le sachet « bras » :
4 x bras bois (A1, A2, A4 et A5)
2 x renforts bois (A3 et A6)
1 x vis à tête bombée à collet carré, M5 x 35 1 x rondelle métal M5
1 x écrou à ailettes M5
2 x rondelles PP blanches

### 4. MONTAGE DU BRAS

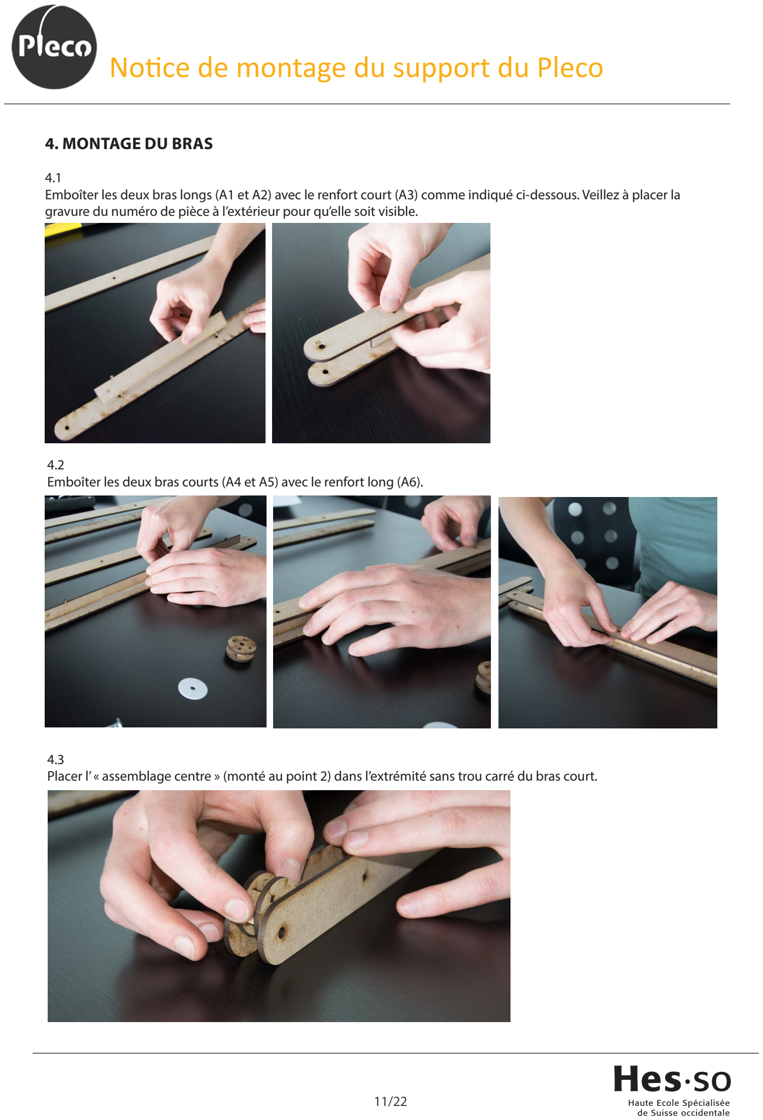
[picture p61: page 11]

4.1
Emboîter les deux bras longs (A1 et A2) avec le renfort court (A3) comme indiqué ci-dessous. Veillez à placer la gravure du numéro de pièce à l’extérieur pour qu’elle soit visible.

4.2
Emboîter les deux bras courts (A4 et A5) avec le renfort long (A6).

4.3
Placer l’ « assemblage centre » (monté au point 2) dans l’extrémité sans trou carré du bras court.

### 4. MONTAGE DU BRAS

4.4
Fixer les deux rondelles en PP de chaque côté du tout à l’aide de petits points de colle.

4.5

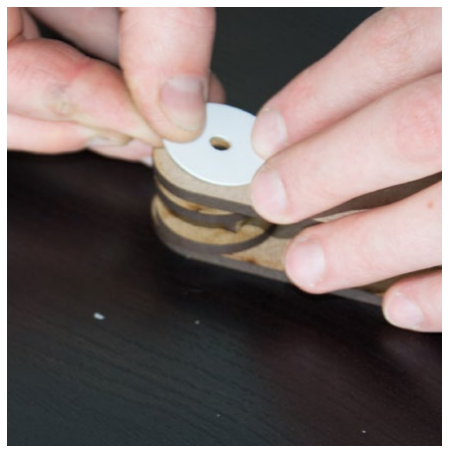
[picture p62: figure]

Placer l’extrémité du bras court avec l’ « assemblage centre » à l’intérieur de l’une des extrémités du bras long, au ni-veau des trous situés près du logo. Attention à ce que les trous carrés du bras court et du bras long soient situés du même côté de manière à ce que tous les écrous à ailettes permettant les réglages soient du même côté du support.

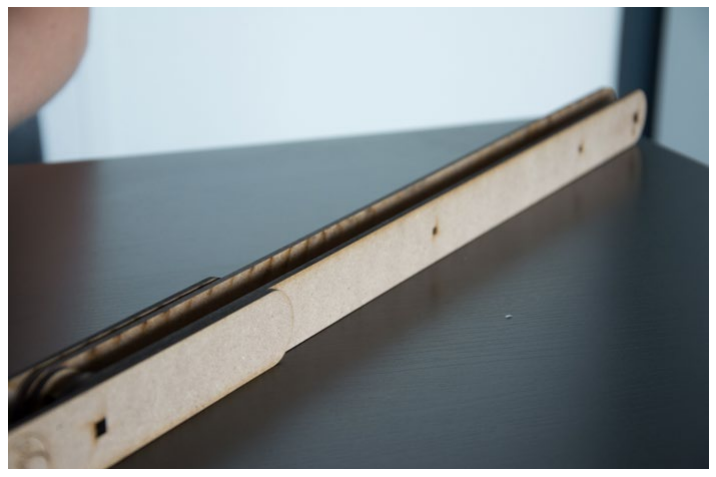
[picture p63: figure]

4.6
Insérer la vis, tête du côté du trou carré, la rondelle en métal et l’écrou à ailettes de l’autre côté puis serrer le tout.

### 5. MONTAGE DU SOCLE

Dans le sachet « socle » :

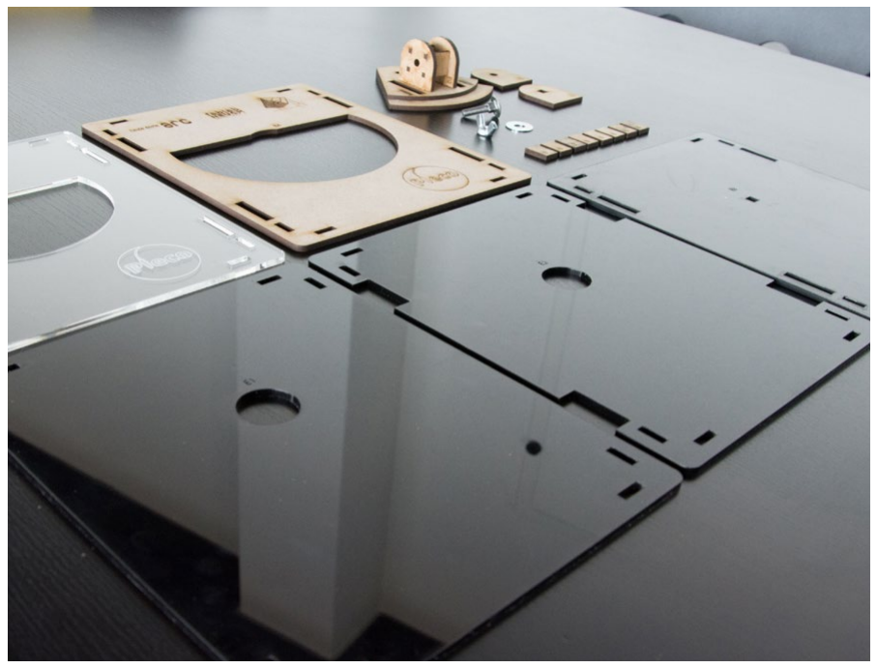
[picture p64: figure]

2 plaques PMMA (E1 et E2)
1 plaque PE (E3)
1 x plaque bois (E4)
1x plaque PMMA transparente (E5)
8 x inserts bois (I3)
1 x vis à tête bombé à collet carré, M5 x 20 1 x rondelle métal M5
1 x écrou à ailettes M5

### 5. MONTAGE DU SOCLE

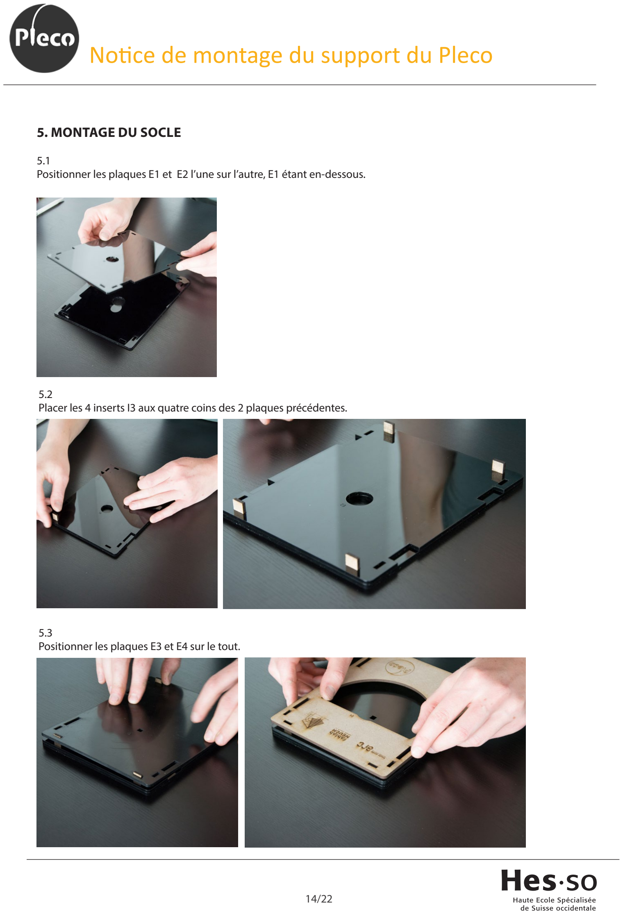
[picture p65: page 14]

5.1
Positionner les plaques E1 et E2 l’une sur l’autre, E1 étant en-dessous.

5.2
Placer les 4 inserts I3 aux quatre coins des 2 plaques précédentes.

5.3
Positionner les plaques E3 et E4 sur le tout.

### 5. MONTAGE DU SOCLE

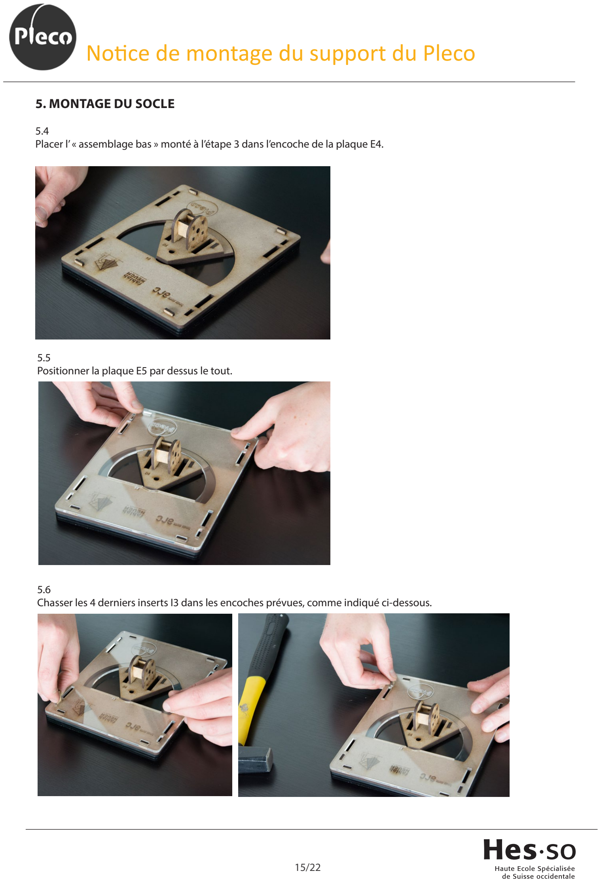
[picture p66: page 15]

5.4
Placer l’ « assemblage bas » monté à l’étape 3 dans l’encoche de la plaque E4.

5.5
Positionner la plaque E5 par dessus le tout.

5.6
Chasser les 4 derniers inserts I3 dans les encoches prévues, comme indiqué ci-dessous.

### 5. MONTAGE DU SOCLE

5.7
Insérer la vis à tête au-dessous du socle, la rondelle en métal et l’écrou à ailettes au-dessus puis serrer le tout.

### 6. MONTAGE DE LA BAGUE

Dans le sachet « bague » :

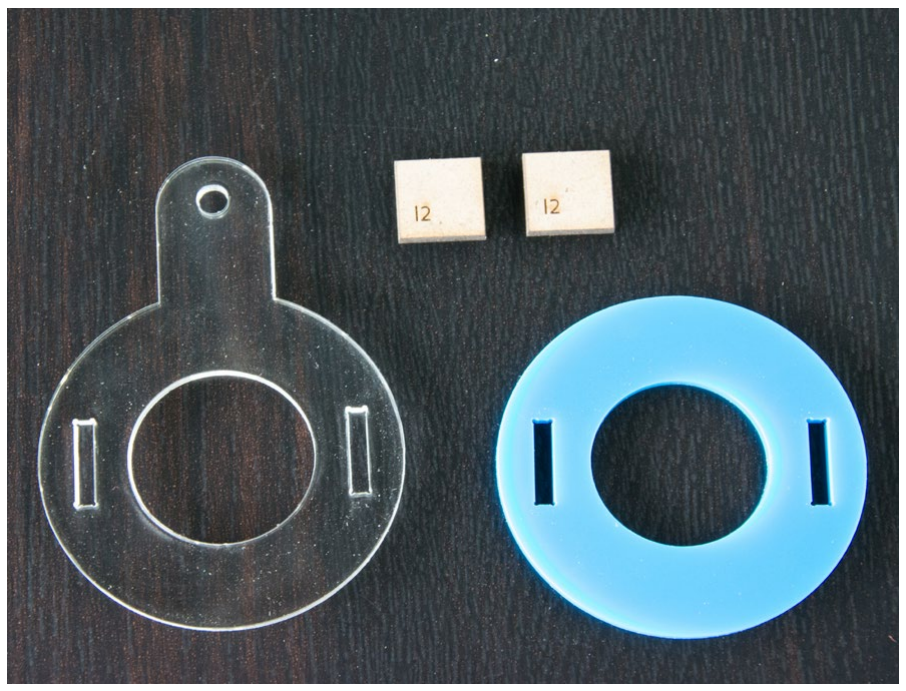
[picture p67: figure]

1 x pièce PMMA transparente
1 x pièce PMMA couleur
2 x inserts bois (I2)

### 6. MONTAGE DE LA BAGUE

6.1
Chasser les inserts I2 dans la pièce transparente en veillant à garder celle-ci bien à plat. Ces pièces plastiques sont très cassantes, c’est pourquoi il faut s’assurer que les inserts ne soient pas inclinés pendant le chassage.

6.2
Poser la pièce couleur à plat puis chasser la pièce transparente munie des inserts sur celle-ci en appuyant sur les inserts.

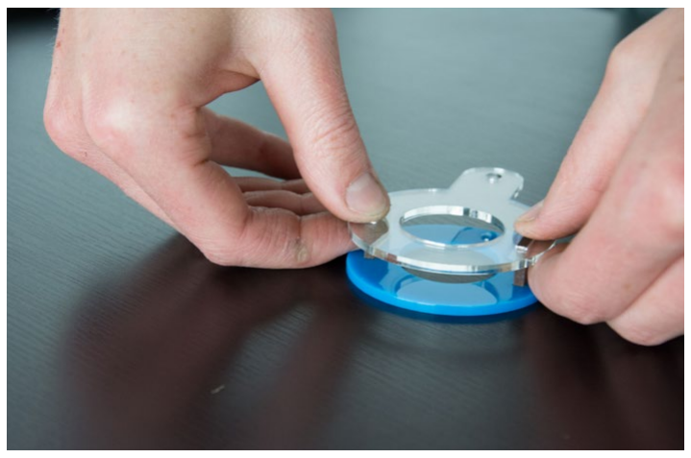
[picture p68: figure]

### 7. ASSEMBLAGE FINAL

Dans le sachet « assemblage final » :

1 x vis à tête bombée à collet carré , M5 x 45 2 x vis à tête bombée à collet carré, M5 x 30 3 x rondelles métal
3 x écrous à ailettes M5
6 x rondelles PP blanches

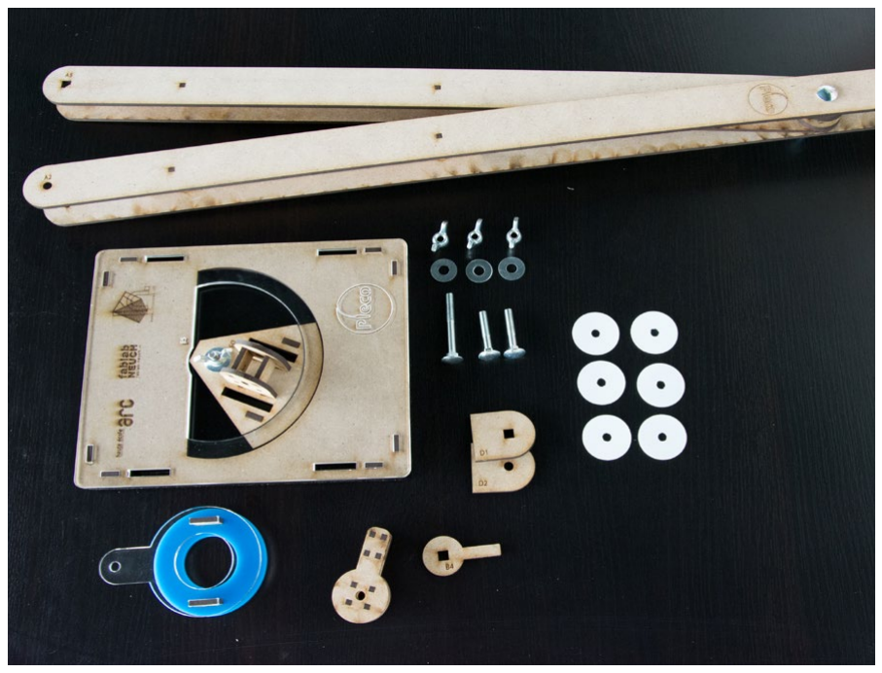
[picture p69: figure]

### 7. ASSEMBLAGE FINAL

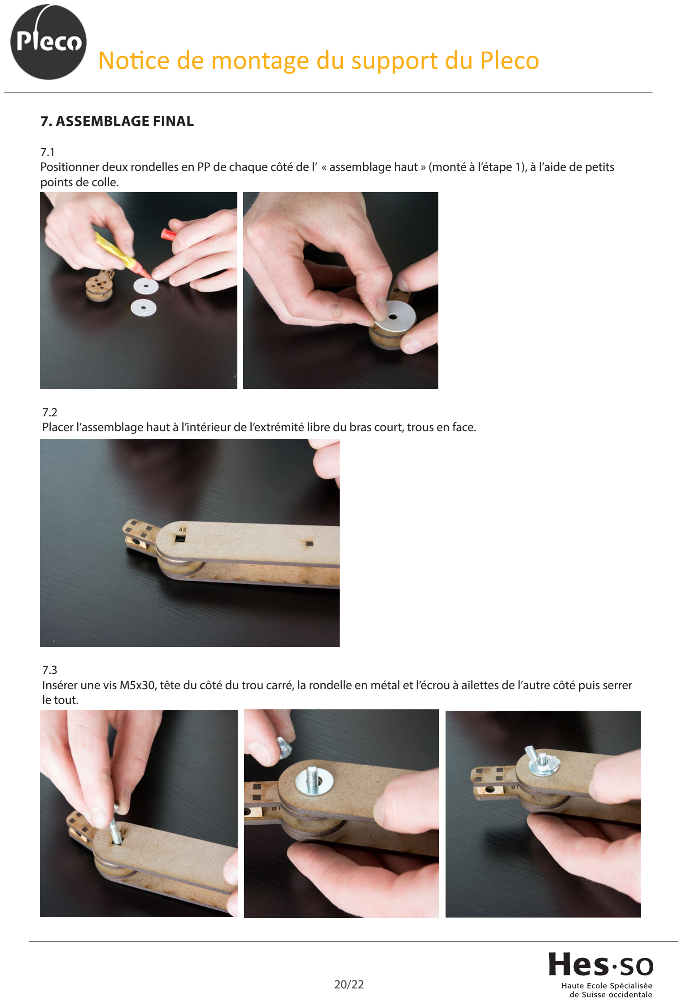
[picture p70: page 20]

7.1
Positionner deux rondelles en PP de chaque côté de l’ « assemblage haut » (monté à l’étape 1), à l’aide de petits points de colle.

7.2
Placer l’assemblage haut à l’intérieur de l’extrémité libre du bras court, trous en face.

7.3
Insérer une vis M5x30, tête du côté du trou carré, la rondelle en métal et l’écrou à ailettes de l’autre côté puis serrer le tout.

### 7. ASSEMBLAGE FINAL

7.4
Placer la « bague » (montée au point 6) sur l’ « assemblage haut », trou en face. Positionner la pièce B4 par-dessus en coinçant sa languette dans l’ « assemblage haut ».

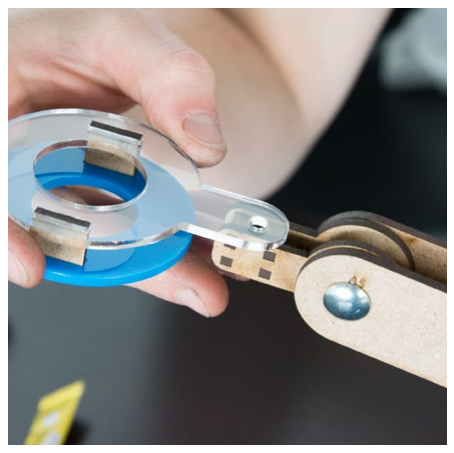
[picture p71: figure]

7.6

Fixer deux rondelles en PP de chaque côté de l’ « assemblage bas » (monté à l’étape 3), à l’aide de petits points de colle. Faire de même sur les pièces D1 et D2.

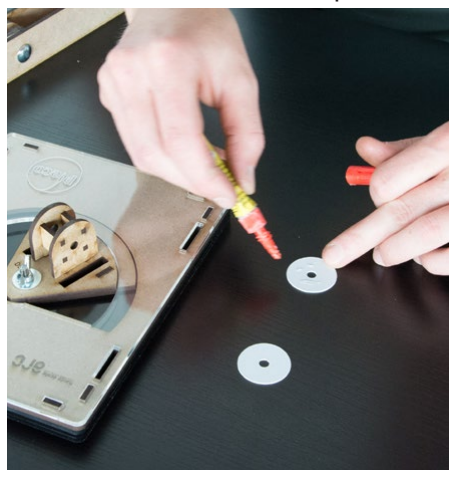
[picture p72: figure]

7.7

Placer les pièces D1 et D2 dans les encoches prévues du socle.

7.5 Insérer une vis M5x30, tête du côté du trou carré, la rondelle en métal et l’écrou à ailettes de l’autre côté puis serrer le tout.

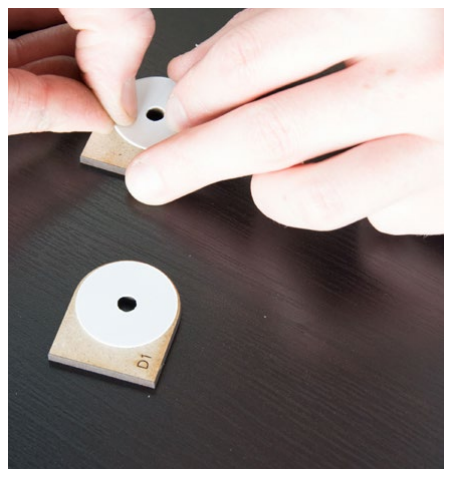
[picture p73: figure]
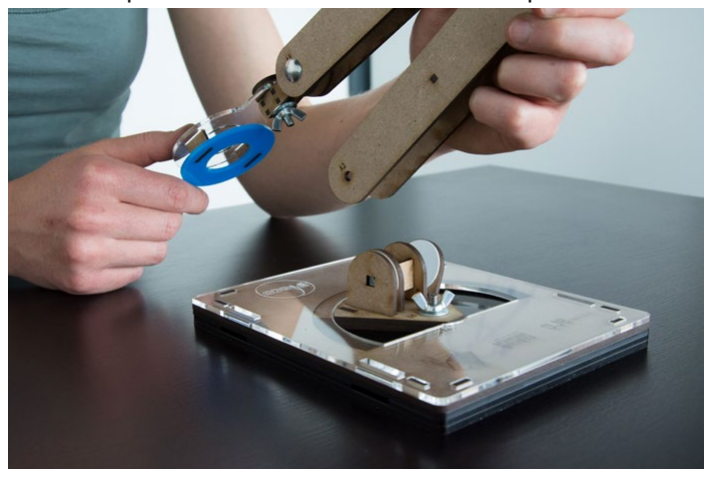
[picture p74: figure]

### 7. ASSEMBLAGE FINAL

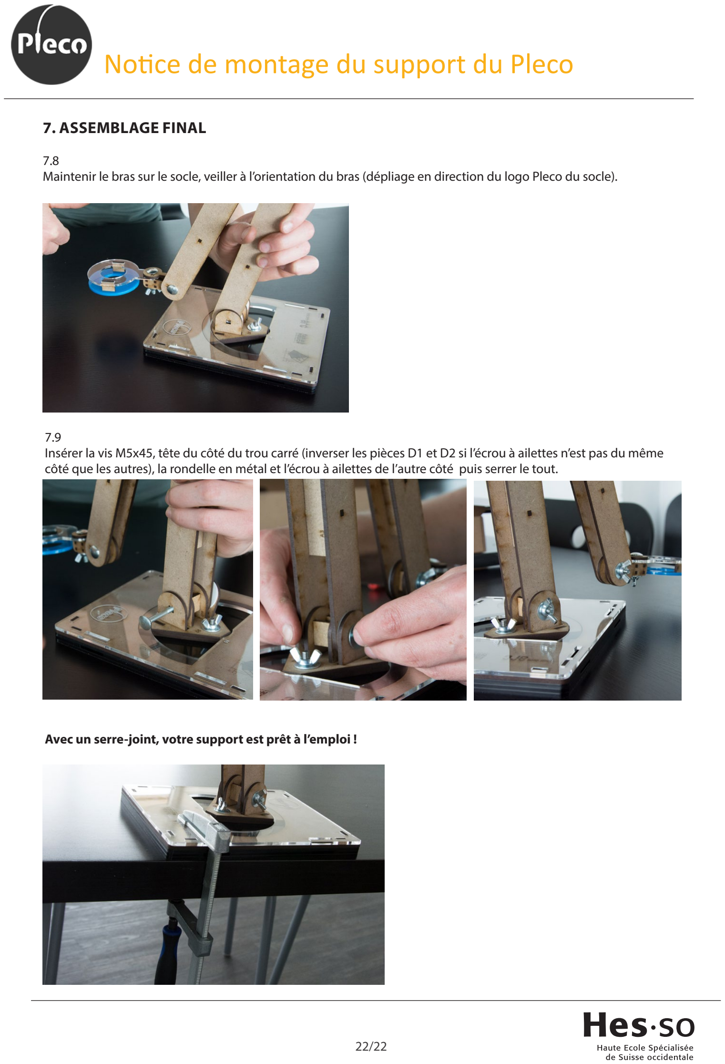
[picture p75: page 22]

7.8
Maintenir le bras sur le socle, veiller à l’orientation du bras (dépliage en direction du logo Pleco du socle).

7.9
Insérer la vis M5x45, tête du côté du trou carré (inverser les pièces D1 et D2 si l’écrou à ailettes n’est pas du même côté que les autres), la rondelle en métal et l’écrou à ailettes de l’autre côté puis serrer le tout.

Avec un serre-joint, votre support est prêt à l’emploi !

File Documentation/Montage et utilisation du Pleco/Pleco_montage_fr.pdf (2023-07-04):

# Notice montage du Pleco

AVANT DE COMMENCER

Le Pleco est un pinceau électrolytique d’un nouveau genre, constitué d’éléments à fabriquer et à assembler soi-même, ergonomique et d’utilisation facile. Conçu pour les traitements électrolytiques localisés, il permet de proposer une alternative au traitement par immersion des éléments métalliques.

Le Pleco est un outil réalisé en étroite collaboration entre l’unité de recherche en Conservation-restauration de la Haute Ecole Arc (UR-Arc CR) de Neuchâtel, l’atelier de restauration de l’Abbaye de Saint-Maurice (Valais) et l’Institut d’Histoire de l’Art et de Muséologie de l’Université de Neuchâtel. L’ergonomie d’ensemble du pinceau a pu être améliorée grâce à un partenariat avec le laboratoire EDANA de la HE-Arc Ingénierie, Neuchâtel. Sa conception et sa fabrication ont par ailleurs bénéficié de l’apport du FabLab de Neuchâtel qui a mis à notre disposition ses technologies de prototypage rapide (impression 3D et découpe laser) permettant de réduire le coût de réalisation du Pleco.

Il s’agit d’un outil unique car entièrement réalisable dans un FabLab. Il fait partie de ces objets dont la construction se développe de manière collaborative et ouverte, car tout à chacun peut améliorer le Pleco, à travers le réseau des FabLab.

Sa conception se poursuit donc à travers ses utilisateurs.

Sa vocation: être le média d’un partage de connaissances autour de l’électrochimie, de la restauration des objets patrimoniaux et de la fabrication FabLab. Pour ce faire, un forum est à votre disposition sur la page web du Pleco (http://fablab-neuch.ch/pleco/) pour nous faire part de vos appréciations, de vos modifications et/ou améliorations et pour partager vos expériences d’usage.

Nous vous invitons à consulter la page web du Pleco avant d’initier son montage. Vous y trouverez une vidéo permettant de préciser certaines explications de montage, ainsi que les informations nécessaires à son utilisation: (http://www.fablab-neuch.ch/pleco/plus.php?id=17).

# Notice montage du Pleco

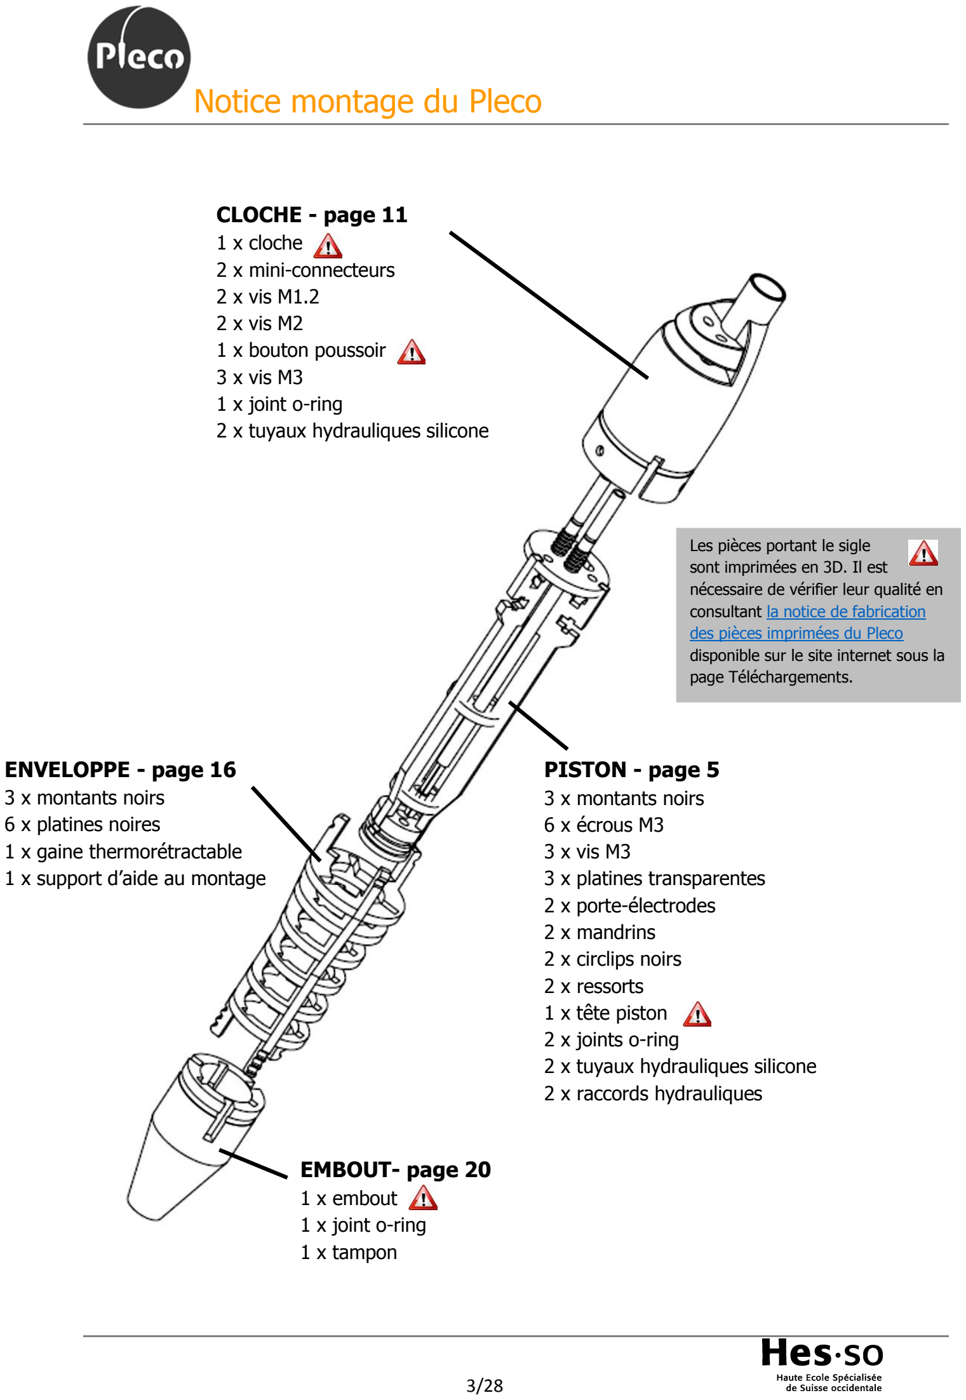
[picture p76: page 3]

### CLOCHE - page 11

1 x cloche
2 x mini-connecteurs
2 x vis M1.2
2 x vis M2
1 x bouton poussoir
3 x vis M3
1 x joint o-ring
2 x tuyaux hydrauliques silicone

Les pièces portant le sigle
sont imprimées en 3D. Il est nécessaire de vérifier leur qualité en consultant la notice de fabrication des pièces imprimées du Pleco (http://fablab-neuch.ch/pleco/files/Pleco_notice_fabrication_fr.pdf) disponible sur le site internet sous la page Téléchargements.

### PISTON - page 5

3 x montants noirs
6 x écrous M3
3 x vis M3
3 x platines transparentes 2 x porte-électrodes
2 x mandrins
2 x circlips noirs
2 x ressorts
1 x tête piston
2 x joints o-ring
2 x tuyaux hydrauliques silicone 2 x raccords hydrauliques

### ENVELOPPE - page 16

3 x montants noirs
6 x platines noires
1 x gaine thermorétractable 1 x support d’aide au montage

### EMBOUT- page 20

1 x embout
1 x joint o-ring
1 x tampon

# Notice montage du Pleco

### OUTILS NÉCESSAIRES

1 x tournevis (inclus dans le kit)
1 x clé Allen 2mm (inclus dans le kit) 1 x pince brucelles
1 x pince à couper
1 x pince plate
1 x scalpel (ou cutter ou ciseaux) 1 x pistolet à air chaud


# Notice montage du Pleco

### 1. MONTAGE DU PISTON


Dans le sachet «piston»:

3 x montants noirs
6 x écrous M3
3 x vis M3 -10mm
3 x platines transparentes 2 x porte-électrodes
2 x mandrins
2 x circlips noirs
2 x ressorts
1 x tête piston
2 x joints o-ring
2 x tuyaux hydrauliques silicone 2 x raccords hydrauliques

### REMARQUE

Vérifier la qualité de
l’impression de cette pièce en consultant la notice de fabrication des pièces
imprimées du Pleco (http://fablab-neuch.ch/pleco/files/Pleco_notice_fabrication_fr.pdf)
disponible sur le site
internet sous la page
Téléchargement.

# Notice montage du Pleco

### 1. MONTAGE DU PISTON

1.1
Positionner les écrous dans les encoches prévues à cet effet sur les 3 montants noirs. Pour un meilleur maintien des écrous, replier légèrement les montants pour réduire la largeur des encoches.

1.2
Positionner à l’aide des encoches prévues à cet effet les platines n°1 et 2 sur le montant noir disposant de deux trous. Bien respecter le dessin ci-dessous pour le positionnement des faces numérotées des platines.

1.3

Insérer le petit porte-électrode dans le trou sans gravure de la platine 1 puis dans le trou correspondant de la platine 2. Positionner un des mandrins sous la platine 2 pour le visser dans le porte-électrode. La platine 2 doit se trouver bloquée entre le porte-électrode et le mandrin.

1.4

Positionner la platine 3 dans l’avant-dernière encoche du montant (toujours avec le n° indiqué du côté du montant) puis insérer le grand porte-électrode en partant du trou marqué en brun sur la platine 1, jusqu’à la dernière platine. Visser le mandrin en le positionnant sous la platine 3.

Astuce:

Au moment de la fixation de la platine 3, appliquer une légère flexion sur l’extrémité du montant pour réduire artificiellement la taille de l’encoche et assurer ainsi la tenue de la platine 3.

# Notice montage du Pleco

### 1. MONTAGE DU PISTON

1.5
Positionner les deux autres montants dans les encoches prévues sur les trois platines.

1.6

Placer la tête du piston rouge sur la partie inférieure de ce montage. Si l’insertion n’est pas aisée, nettoyer les encoches sous microscope. Il faut que le montant du piston avec les trous soit inséré dans l’encoche de la tête signalée par les 2 flèches rouges.

1.7


Enfiler les joints o-ring dans les rainures de la tête du piston. Le plus petit joint o-ring (en diamètre) se place dans la rainure du haut de la tête (vers les platines), le joint de plus grand diamètre, dans la rainure du bas.

# Notice montage du Pleco

### 1. MONTAGE DU PISTON

1.8
Positionner les vis M3 sur le dessus de la platine 1. Visser avec la clé Allen fournie dans le kit.

1.9

Insérer les ressorts sur le haut des porte-électrodes.

1.10


Placer les circlips au-dessus des ressorts dans les encoches des porte-électrodes. Il est nécessaire de compresser légèrement chaque ressort avec l’ongle pour libérer l’espace nécessaire à l’insertion du circlips. Il est conseillé de s’aider d’une pince pour pouvoir positionner plus facilement les circlips. Ne pas hésiter à appliquer de la force pendant l’opération jusqu’à entendre un «clic» confirmant l’insertion du circlips.


Remarque :

Il est possible que les portes électrodes ne soient pas exactement à la même hauteur du côté supérieur du piston. Cela ne pose pas de problème pour la suite du montage et le bon fonctionnement du Pleco.

# Notice montage du Pleco

### 1. MONTAGE DU PISTON

1.11
Prendre les deux tuyaux hydrauliques en silicone et réaliser un biseau sur environ 2 cm à une extrémité de chacun d’eux à l’aide d’un cutter ou d’une paire de ciseaux. Cette forme biseautée vous permettra d’introduire plus facilement les tuyaux dans le piston.

1.12

Insérer les raccords hydrauliques aux extrémités non biseautées des tuyaux. Ensuite, enfiler les extrémités biseautées des tuyaux hydrauliques en silicone, en commençant par le tube central, dans les trous prévus en partant du haut de la platine 1, puis en les faisant passer dans les trous de chaque platine et de la tête du piston. Il faut que les extrémités munies des raccords se retrouvent à raz de la platine 1. Vous pouvez vous aider si nécessaire d’une pince brucelles.


# Notice montage du Pleco

### 1. MONTAGE DU PISTON

Remarque préalable à l’étape 1.13 :

Il peut être conseillé de reporter l’étape 1.13 en toute fin de montage. En effet, si l’embout et la tête du piston sont mal ajustés, il est possible que la tête du piston se décroche durant l’étape 6. Il est alors compliqué de réinsérer les tuyaux dans la tête du piston sans l’aide des biseaux. L’utilisation d’eau savonneuse permet de faciliter cette étape si les tuyaux ont déjà été coupés.

1.13
Couper avec un cutter ou des ciseaux les tuyaux qui dépassent de la tête du piston. Le tuyau positionné au centre de la tête doit être coupé à fleur de la tête du piston (avec un dépassement maximal de 1 mm). L’autre tuyau est à nouveau coupé en biseau, côté intérieur. La partie longue doit faire environ 1 cm, le côté biseauté, 0.5 cm, comme illustré sur la photo du bas. Le tuyau le plus long et biseauté correspond au tuyau d’amenée de la solution électrolytique, le tuyau coupé à raz de la tête du piston est le tuyau d’extraction de la solution.


# Notice montage du Pleco

REMARQUE

2. INSTALLATION DE LA CONNECTIQUE ET DE LA CLOCHE

Dans le sachet «cloche»:

2 x mini connecteurs
2 x vis M1.2 - 3mm
1 x câble électrique- 2 fils
2 x tuyaux hydrauliques de 1.5m
1 x cloche
2 x vis M2 - 8mm
1 x bouton poussoir
3 x vis M3 - 8mm
1 x joint o-ring

Vérifier la qualité de
l’impression de ces pièces
en consultant la notice de
fabrication des pièces
imprimées du Pleco (http://fablab-neuch.ch/pleco/files/Pleco_notice_fabrication_fr.pdf)
disponible sur le site
internet sous la page
Téléchargement.

# Notice montage du Pleco

### 2. INSTALLATION DE LA CONNECTIQUE ET DE LA CLOCHE

2.1
Dénuder le câble électrique à 2 fils d’environ 3 cm à l’aide d’un cutter ou d’une pince coupante électrique. Insérer le câble dans le trou de la cloche. Les deux fils électriques séparés doivent ressortir du côté de l’ouverture la plus large comme illustré sur la photo.

2.2


Ensuite, dénuder de la même manière l’extrémité de chaque fil (5 mm).

.3

Placer les petits connecteurs sur chacun des 2 fils dénudés précédemment. Serrer ensuite les connecteurs avec une pince plate afin d’assurer la connexion électrique. Une partie de la gaine doit être également serrée dans le connecteur afin de garantir une bonne tenue et éviter la fatigue des fils de cuivre.


# Notice montage du Pleco

### 2. INSTALLATION DE LA CONNECTIQUE ET DE LA CLOCHE

2.4
Placer les vis M1.2 dans les petits trous en haut des porte-électrodes (ceux qui se trouvent du côté du méplat). Tourner les portes électrodes de sorte à orienter les méplats en direction des tuyaux hydrauliques. Insérer ensuite les fils avec connecteurs dans les trous latéraux depuis l’extérieur. Le fil blanc (électrode de référence) doit être connecté au porte-électrode de plus petite taille. Serrer ensuite légèrement les vis - attention à ne pas endommager le taraudage des portes électrodes - de manière à ce qu’il y ait une connexion entre la vis et le connecteur. Contrôler la résistance du branchement en tirant légèrement sur les fils. Si cela ne suffit pas, repositionner les fils et serrer davantage les vis.


2.5
Faire passer les deux longs tuyaux hydrauliques de 1.5m par l’ouverture du dessus de la cloche, puis les connecter aux raccords hydrauliques sur le haut du piston.

Remarque :


Le marquage pour distinguer le tuyau d’amenée de celui de l’extraction nécessaire pour les branchements sur les pompes se fera en fin de montage.

# Notice montage du Pleco

### 3. MONTAGE PISTON – CLOCHE

3.1
Faire coulisser la cloche sur la gaine électrique et les tuyaux hydrauliques de manière à la positionner sur le piston. Les raccords hydrauliques, ainsi que le câblage électrique doivent être sous la cloche, bien tendus, seuls la gaine et les tuyaux doivent passer par l’ouverture du haut de la cloche, Attention, il faut veiller à ce que les porte-électrodes ressortent convenablement par les 2 trous prévus sur le haut de la cloche, en faisant correspondre les méplats des porte-électrodes et les trous de la cloche. Utiliser une pince pour faire pivoter les porte-électrodes si ceux-ci ne sont pas parfaitement en face.

3.2
Positionner les 3 vis M3 autour de la cloche, puis les visser au moyen de la clé Allen 2 mm inclue dans le kit.

3.3
Positionner le bouton poussoir sur les extrémités visibles des porte-électrodes, puis visser avec les deux vis M2.


# Notice montage du Pleco

### 3. MONTAGE PISTON – CLOCHE

3.4
Placer le joint o-ring sur la cloche, au niveau de la rainure prévue. Cette opération peut être réalisée avant, dès le placement de la cloche.

# Notice montage du Pleco

### 4. MONTAGE DE L’ENVELOPPE


Dans le sachet «enveloppe»:

3 x montants noirs
6 x platines noires
1 x gaine thermorétractable transparente
1 x support d’aide au montage

# Notice montage du Pleco

### 4. MONTAGE DE L’ENVELOPPE

4.1
Imbriquer les deux éléments en bois MDF afin de réaliser votre support d’aide au montage. Insérer ensuite les platines noires sur le support en veillant à ce qu’une des encoches de ces platines s’insère sur le montant du support marqué d’une flèche. Commencer par la plus grande platine, à positionner sur la première marque du haut du support. Continuer avec les autres platines par ordre de grandeur décroissant.


4.2

Positionner ensuite délicatement un des montants noirs. Il est recommandé de commencer par fixer l’encoche du haut en redescendant.

4.3

Fixer ensuite les deux autres montants de la même manière. Puis vérifier la mise en place en passant le doigt à l’intérieur ou extérieur de la structure obtenue pour contrôler que les platines se trouvent bien à fleur des montants.


# Notice montage du Pleco

### 4. MONTAGE DE L’ENVELOPPE

4.4
Placer la structure obtenue dans la gaine thermoplastique transparente en prenant soin de la positionner bien au milieu, dans la longueur et dans


la largueur.

4.5
Chauffer au moyen d’un pistolet à air chaud (entre 250 et 300°C), en faisant tourner l’enveloppe pour répartir l’air chaud. Prendre garde à ne pas surchauffer la

gaine thermoplastique pouvant entraîner la fonte des encoches du polyéthylène noir et rendant plus difficile l’insertion de l’enveloppe sur le piston.

4.6
Une fois la gaine rétractée, l’ajuster en la coupant avec un scalpel (ou cutter) juste à l’extérieur des platines, à chaque extrémité.


# Notice montage du Pleco


### 5. MONTAGE PISTON - ENVELOPPE

5.1
Faire coulisser l’enveloppe sur le piston. Vérifier que les extrémités hautes des montants de l’enveloppe s’encastrent sur les encoches de la cloche, sous le joint o’ring.

# Notice montage du Pleco

### 6. MONTAGE DE L’EMBOUT

Dans le sachet «embout»:

1 x embout
1 x joint o-ring
1 x tampon

REMARQUE

Vérifier la qualité de l’impression de cette pièce en consultant la notice de fabrication des pièces imprimées du Pleco (http://fablab-neuch.ch/pleco/files/Pleco_notice_fabrication_fr.pdf) disponible sur le site internet sous la page Téléchargement.

# Notice montage du Pleco

### 6. MONTAGE DE L’EMBOUT

6.1
Positionner le joint o-ring sur l’embout dans la rainure prévue à cet effet.

6.2

Insérer l’embout sur le bas du piston en prenant soin de rester dans le même axe. Lorsque l’ajustage tête du piston/embout est trop serré, il est obligatoire de mouiller l’intérieur de l’embout avec de l’eau. Les extrémités basses des montants noirs de l’enveloppe doivent passer sous le joint o-ring. Il peut être nécessaire de soulever un peu les montants afin de bien positionner l’embout.

Remarque :
C’est lors de cette étape que l’on vérifie le bon dimensionnement de la tête du piston et de l’embout. Si les ajustements sont trop serrés, il est probable que la tête du piston se détache lorsque l’on retire l’embout. L’ajout d’une bande de PTFE (téflon) autour de la tête du piston facilite l’insertion et l’enlèvement de l’embout tout en améliorant l’étanchéité.

Accessoires supplémentaires :
le kit dispose de bagues réhausseuses permettant d’augmenter le volume de la chambre électrolytique (contenu de l’embout). Ces bagues se positionnent lors de cette opération.

# Notice montage du Pleco

### 6. MONTAGE DE L’EMBOUT

6.3
Il ne manque plus qu’à insérer le tampon en mousse dans l’embout pour que votre Pleco soit prêt. Pour cela, humidifier préalablement la mousse. Le tampon en mousse se fixe directement sur l’embout, en prenant soin de faire correspondre l’axe médian creusé dans le tampon avec les électrodes.

# Notice montage du Pleco

### 7. POSE DE LA GAINE POUR LES CÂBLES ET LES TUYAUX HYDRAULIQUES


Dans le sachet «gaine»:

1 x mini gaine rétractable noire 1 x gaine tressée

# Notice montage du Pleco

### 7. POSE DE LA GAINE POUR LES CÂBLES ET LES TUYAUX HYDRAULIQUES

7.1
Enfiler le bout de gaine thermorétractable sur la gaine tressée, puis enfiler les tuyaux hydrauliques ainsi que la gaine électrique dans la gaine tressée. Si les extrémités de la gaine tressée s’effilochent, il faut utiliser la flamme d’un briquet pour faire fondre la gaine.
Astuce: la gaine tressée se compresse facilement permettant de faire glisser les câbles à l’intérieur. La tâche reste néanmoins fastidieuse.

7.2

Une fois les câbles et les tuyaux passés dans la gaine tressée, positionner celle-ci au-dessus de l’ouverture de la cloche, jusqu’au milieu de la gorge. Positionner par-dessus la gaine thermorétractable noire de manière à ce qu’elle déborde de quelques millimètres sur la cloche. Cela assurera que la jonction tienne bien une fois chauffée. Vous pouvez vous aider de la brucelle pour bien tirer la gaine noire.

7.3

Chauffer la gaine thermorétractable noire au moyen du pistolet à air chaud. A nouveau maintenir le pistolet à distance pour ne faire fondre la gaine et la résine de la cloche.

# Notice montage du Pleco


8. CONNEXIONS HYDRAULIQUES ET ELECTRIQUES FINALES

Dans le sachet «connexions finales»:
2 x mini connecteurs électriques
2 x fiches bananes (blanche et brune)
2 x gaines thermorétractables de 20 cm
2 x gaines thermorétractable de 3 cm
2x connecteurs hydrauliques

# Notice montage du Pleco

### 8. CONNEXIONS HYDRAULIQUES ET ELECTRIQUES FINALES

8.1
Insérer les connecteurs hydrauliques aux extrémités des tuyaux hydrauliques.

.2

Dénuder le câble électrique sur une longueur d’environ 20 cm (équivalente aux longues gaines thermorétractables). Pour ne pas endommager les câbles internes, il faut d’abord inciser légèrement la gaine afin de la casser.

8.3

Dénuder les câbles électriques internes blanc et brun sur 1 cm. Puis enfiler les mini-connecteurs au plus proche de la gaine. Sertir les connecteurs à l’aide d’une pince.


# Notice montage du Pleco

### 8. CONNEXIONS HYDRAULIQUES ET ELECTRIQUES FINALES

8.4
Introduire les 2 longues gaines thermorétractables (20 cm) sur chaque câble électrique. Réajuster la longueur de la gaine en prenant soin de laisser apparaître quelques mm du câble muni du connecteur et laissant deviner la couleur du câble, afin de les différencier par la suite.


8.5

Chauffer les 2 gaines thermorétractables à l’aide d’un pistolet à air chaud. A nouveau maintenir le pistolet à distance pour ne faire fondre les gaines. Enfiler ensuite la petite gaine thermorétractable, jusqu’au point de disjonction des câbles gainés, puis la chauffer.

8.6

Enfiler et chauffer la deuxième gaine thermorétractable au bout de la gaine textile et ainsi éviter que celle-ci ne s’effiloche avec le temps.

# Notice montage du Pleco

### 8. CONNEXIONS HYDRAULIQUES ET ELECTRIQUES FINALES

8.7
Pour fixer maintenant les fils aux fiches bananes, dévisser dans un premier temps la vis de fixation de chaque fiche afin de pouvoir insérer ensuite les câbles dans la fiche banane de couleur correspondante. Revisser la fixation puis insérer chaque fiche banane câblée dans le capot plastique de couleur correspondante.

Votre Pleco est prêt à l’emploi !!!

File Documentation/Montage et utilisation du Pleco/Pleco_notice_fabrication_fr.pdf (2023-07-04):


NOTICE DE FABRICATION DES PIÈCES IMPRIMÉES DU PLECO

## Notice de fabrication des pièces imprimées du Pleco

AVANT DE COMMENCER

Certaines pièces du Pleco sont fabriquées par impression 3D : l’embout, la cloche, la tête du piston et le bouton
poussoir. Les fichiers | 3D sont disponibles | en
téléchargement | à | ce | lien : | http://www.fablab-
neuch.ch/pleco/files/Pleco_v1.2_fr.zip (http://www.fablab-neuch.ch/pleco/files/Pleco_v1.2_fr.zip)

Afin de pouvoir assembler puis utiliser le Pleco correctement, il est important d’obtenir des impressions de qualité optimale en appliquant les conseils et paramètres présentés dans ce document.

Il contient également des conseils pour ébavurer les pièces sans les abimer et obtenir le meilleur parti de ces
technologies | de | prototypage. | Les | paramètres
d’impressions, de contrôle de la qualité et les traitements de finitions sont décrits pour chacune des pièces concernées.

Nous vous invitons à consulter la page web du Pleco avant d’initier ce travail. Vous y trouverez la vidéo de la finition des pièces en impression 3D permettant de préciser les opérations à mener: (http://www.fablab-neuch.ch/pleco/plus.php?id=17).

## Notice de fabrication des pièces imprimées du Pleco


CLOCHE - page 5

BOUTON POUSSOIR
- page 8

TÊTE DE PISTON - page 10

EMBOUT - page 6

## Notice de fabrication des pièces imprimées du Pleco

A. Liste du matériel requis pour la fabrication et la finition

Imprimante 3D

- Imprimante Ultimaker® Original +

Matériel annexe

- Ruban de masquage 3M® longue durée 2090
- Scalpel/Cutter et petite lime ronde
- Papier de verre - grain grossier (autour 120)
- Papier de verre - grain fin (autour de 280)

Remarques

Toutes les pièces sont imprimées avec une imprimante Ultimaker original + équipée d’un plateau chauffant¹

. Nous avons utilisé le logiciel Cura² pour la configuration de l’impression. Nous conseillons vivement d’utiliser les filaments de la marque Ultimaker® ou colorFabb® avec lesquels nous avons une expérience positive. Pour une meilleure accroche des pièces sur le plateau d’impression, il est nécessaire d’utiliser le ruban de masquage pour recouvrir le plateau en verre. :


1 L’impression des pièces du Pleco est aussi possible sur une Ultimaker sans plateau chauffant.
2 Lors de la rédaction de la présente notice, nous employions la version 15.04.2 du logiciel. Nous ne pouvons garantir qu’une version antérieure ou qu’une mise à jour du logiciel garantisse le dimensionnement final des pièces.

Filaments de matière

- Rouleau de filament transparent PLA pour imprimante 3D
- Rouleau de filament noir PLA pour imprimante 3D
- Rouleau de filament rouge PLA pour imprimante 3D

## Notice de fabrication des pièces imprimées du Pleco

### I. CLOCHE

Paramètres d’impression

Matière: PLA transparent
Configuration Cura pour mode simple : Profil d’impression : Qualité normale Matériau : PLA
Configuration Cura pour mode expert : Type d’accroche au plateau : Bordure (Brim) Orientation de la pièce :


Contrôle de la qualité de l’impression

Ci-dessous une cloche après impression (a) :


(a) (b)

Traitement de finition

Ebavurer à l’aide d’un cutter ou d’un scalpel le surplus de matière pour l’accroche sur le plateau, les pourtours ainsi que l’intérieur des encoches en faisant attention à ne pas exercer trop de pression sur la partie inférieure (image (b)) . En effet, la saignée pour accueillir le système d’assemblage (joint o-ring) est très fragile.

## Notice de fabrication des pièces imprimées du Pleco

### II. EMBOUT

Paramètres d’impression

Matière: PLA transparent
Configuration Cura pour mode simple : Profil d’impression : Qualité haute


Matériau : PLA
Configuration Cura pour mode expert : Type d’accroche au plateau : Sans Orientation de la pièce :

Contrôle de la qualité de l’impression

ATTENTION: Cette pièce doit impérativement être étanche pour assurer le bon fonctionnement de l’outil.

Observez tout d’abord l’aspect général de votre pièce en vous référant aux images ci-dessous.


## Notice de fabrication des pièces imprimées du Pleco

La partie cylindrique intérieure doit être exempte de tout matériau de soutien d’impression, comme c’est le cas ci-dessous sur l’image (a). La partie conique doit impérativement comporter des couches d’impression propres et soudées entre-elles. Il ne doit y avoir aucun trou dans la surface. Même si celle-ci parait fermée à l’œil nu, il est recommandé de contrôler son étanchéité en remplissant l’embout d’eau et d’en boucher la base avec le doigt comme indiqué sur l’image (b). Vous pouvez procéder à un deuxième contrôle en soufflant dans l’ouverture de l’embout, tout en bouchant la base du cône de la même manière qu’avec l’eau. Si vous sentez que du liquide ou de l’air s’échappe de l’embout, cela indique vraisemblablement un défaut d’étanchéité. Il est alors conseillé de réimprimer la pièce en vérifiant bien l’état de l’imprimante (hauteur de buse, alignement des axes, etc.).


(a) (b)

Traitement de finition

Poncer l’intérieur de l’embout en commençant par le papier de verre grossier, jusqu’à que la surface soit lisse et régulière. Attention à ne pas altérer la partie conique, très fine. Pour garantir une bonne étanchéité de la cellule électrolytique, l’ajustement est très serré, c’est pourquoi il est nécessaire d’améliorer au maximum cet état de surface. Passer ensuite au papier de verre fin afin de lisser la surface.


Durant le montage du Pleco, vous devrez tester l’ajustement du piston dans l’embout. Il doit pouvoir coulisser (avec toutefois une certaine résistance). Si ce n’est pas le cas, poncer encore l’intérieur en recommençant avec le papier de verre grossier. Cette étape peut s’avérer longue et fastidieuse si la qualité d’impression n’est pas optimale. L’ajout d’une bande de téflon autour du piston permet de faciliter le glissement de l’embout dans le cas d’un état de surface et un ajustement moins précis.

Astuce: Enrouler le papier abrasif autour d’un outil cylindrique (ici un stylo-bille), afin d’avoir un dispositif de ponçage plus efficace.

## Notice de fabrication des pièces imprimées du Pleco

### III. BOUTON POUSSOIR

Paramètres d’impression

Matière: PLA noir
Configuration Cura pour mode simple : Profil d’impression : Qualité haute Matériau : PLA
Configuration Cura pour mode expert : Type d’accroche au plateau : Sans Orientation de la pièce :


Contrôle de la qualité de l’impression

Ci-dessous un bouton après impression (pièce de gauche sur l’image (a)) :


(a) (b)

Traitement de finition

Ebavurer les bordures à l’aide d’un cutter ou d’un scalpel et d’une petite lime ronde pour l’intérieur des trous. Poncer ensuite la surface concave avec le papier de verre gros grain suivi du papier de grain plus fin jusqu’à obtenir une surface lisse (image (b)).

## Notice de fabrication des pièces imprimées du Pleco

### IV. TÊTE DE PISTON

Paramètres d’impression

Matière: PLA rouge (ou tout autres coloris) Configuration Cura pour mode simple : Profil d’impression : Qualité normale


Matériau : PLA


Configuration Cura pour mode expert : Type d’accroche au plateau : Sans Orientation de la pièce :

Contrôle de la qualité de l’impression

ATTENTION: C’est une pièce qui doit impérativement être étanche pour assurer le bon fonctionnement de l’outil.

Lorsque vous démarrez l’impression de la tête vous devez absolument contrôler l’état de la première couche. Il faut que la distance entre la buse et le plateau soit réglée de sorte à ce que le filament soit légèrement aplani lors de l’impression. Si la première couche n’est pas déposée de manière optimale, elle comportera des trous ne permettant pas d’assurer une bonne étanchéité. L’image ci-dessous permet de se rendre compte de la différence entre un bon départ d’impression et un mauvais.

## Notice de fabrication des pièces imprimées du Pleco


Une fois l’impression terminée, on voit la différence entre une surface étanche (pièce de droite) et une surface poreuse (pièce de gauche), sur l’image (a) ci-dessous.


(a) (b)

Traitement de finition

Ebavurer les bordures à l’aide d’un cutter ou d’un scalpel et d’une petite lime ronde pour l’intérieur des trous.

Il est possible que la gorge inférieure du joint o-ring présente une ouverture. C’est un défaut de fabrication qui peut se produire puisque l’épaisseur de la paroi est ici très fine. Cette surface n’étant pas en contact avec le liquide, elle ne contribue pas à l’étanchèïté. Ce défaut, courant, n’est donc pas problématique pour le bon fonctionnement du Pleco.

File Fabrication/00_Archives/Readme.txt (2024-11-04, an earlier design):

<<<<<<< HEAD:Fabrication/00_Archives/Readme.txt
*** Pleco ***

T�l�charg� sur:	http://www.fablab-neuch.ch/pleco

=======
>>>>>>> ccac0ef5721dddccdc55e0b70c647000087b3d4c:Fabrication/Readme.txt
*** FABRICATION ***

--->DECOUPES LASER

Les fichiers présents dans le dossier /découpes_laser sont destinés à la découpe.
Les matières à utiliser sont indiquées dans le document.

Lors de la conception des pièces, la découpeuse laser suivante a été utilisée: 	
TROTEC speedy 300

--->IMPRESSIONS 3D

Pour des questions d'étanchéité, les fichiers présents dans le dossier /impressions_3D_DLP sont à imprimer avec une technologie d'impression 3D DLP (Digital Light Processing) ou SLA (Stereolithography).
Lors de la conception des pièces, l'imprimante 3D suivante a été utilisée: 	
B9 Creator (http://www.b9creator.com/)

Les fichiers présents dans le dossier /impressions_3D_FDM sont à imprimer avec une technologie d'impression 3D FDM (Fused deposition modeling).
Lors de la conception des pièces, l'imprimante 3D suivante a été utilisée: 	
Ultimaker (http://www.ultimaker.com/)

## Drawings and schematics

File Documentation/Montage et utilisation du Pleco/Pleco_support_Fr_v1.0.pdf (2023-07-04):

# Bras

Socle | Socle

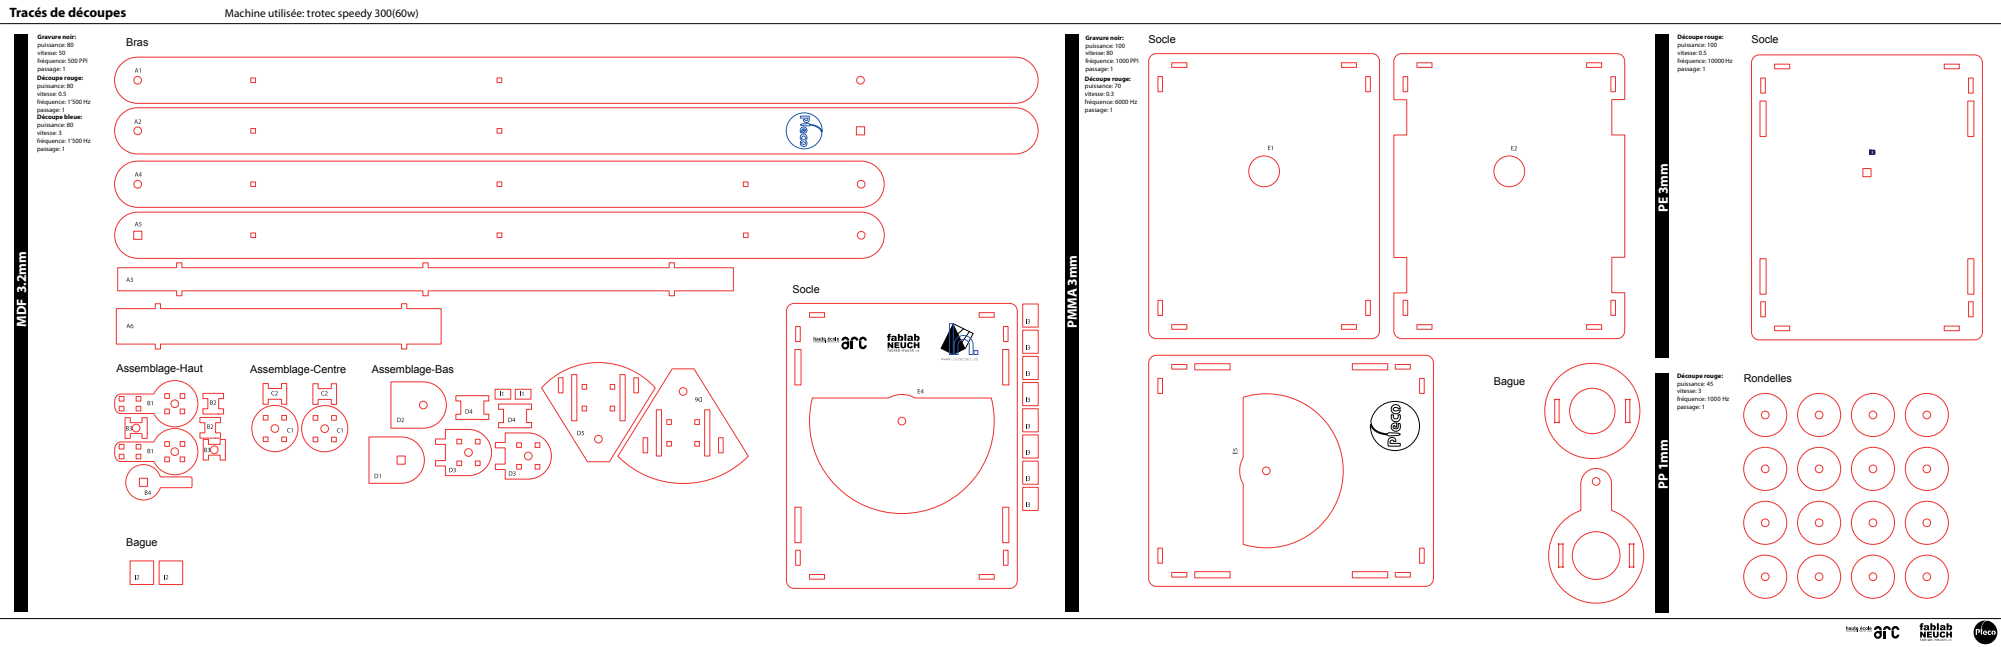
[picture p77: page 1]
Socle; Assemblage-Centre; Assemblage-Bas; Bague; Rondelles; PMMA 3mm; cou; rouge:; puissan; tesse: 0.5; réquen; passage: 1 Dé; pe bleue: puissan; tesse: 3; passage: 1; Assemblage-Haut; pes; Machine utilisée: t; tec speedy 300(60w); Gravure noir: puissan; tesse: 50; ce: 500 PPI passage: 1; tesse: 0.3; tesse: 80; ce: 1000 PPI passage: 1; MDF 3.2mm

cés de dé

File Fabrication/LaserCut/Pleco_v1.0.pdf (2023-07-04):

Tracés de découpes | Machine utilisée: trotec speedy 300 (60w)

# Piston - montant

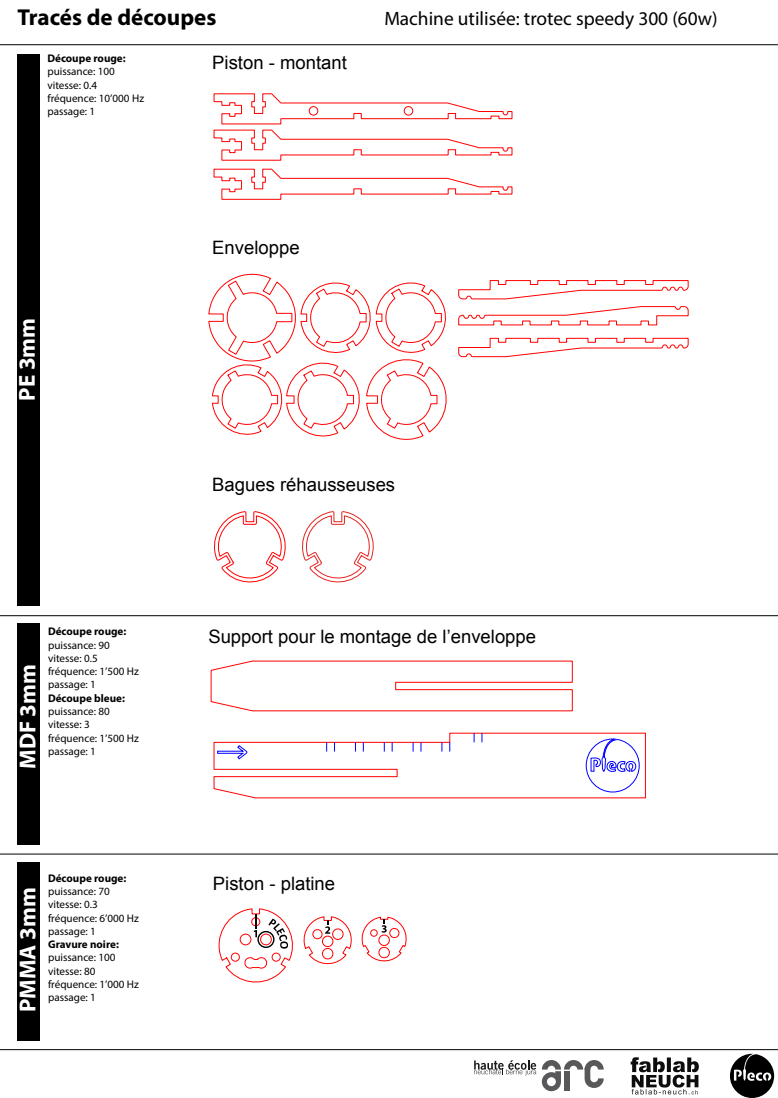
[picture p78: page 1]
Enveloppe; Découpe rouge: puissance: 100 vitesse: 0.4 fréquence: 10’000 Hz passage: 1; Bagues réhausseuses; MDF 3mm

Support pour le montage de l’enveloppe Découpe rouge:
puissance: 90
vitesse: 0.5
fréquence: 1’500 Hz
passage: 1
Découpe bleue:
puissance: 80
vitesse: 3

Piston - platine Découpe rouge:
puissance: 70
vitesse: 0.3
fréquence: 6’000 Hz
Gravure noire:
puissance: 100
vitesse: 80
fréquence: 1’000 Hz

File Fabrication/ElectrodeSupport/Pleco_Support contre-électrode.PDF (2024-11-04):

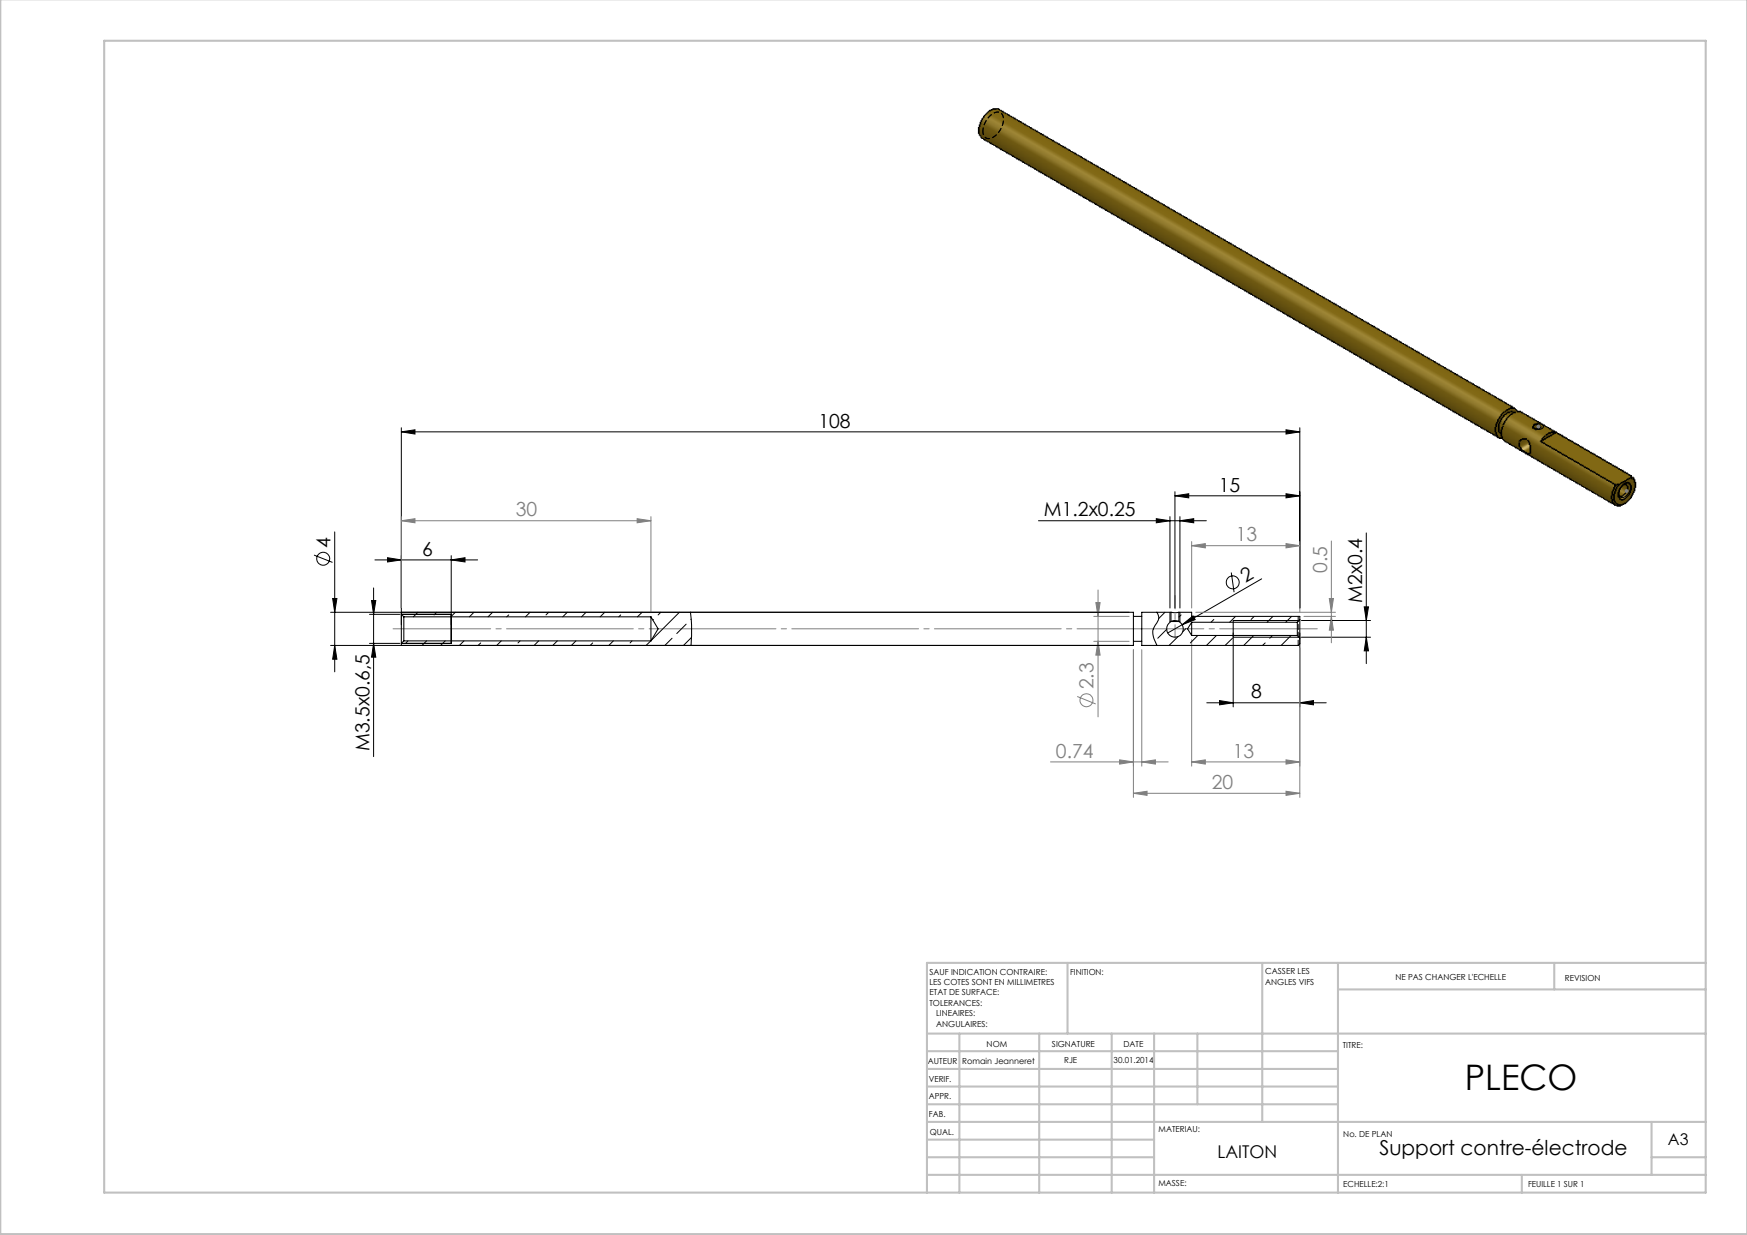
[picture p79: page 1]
ECHELLE:2:1; FEUILLE 1 SUR 1; NE PAS CHANGER L'ECHELLE; REVISION; CASSER LES ANGLES VIFS; SAUF INDICATION CONTRAIRE:; FINITION:

LES COTES SONT EN MILLIMETRES
ETAT DE SURFACE:
TOLERANCES:
LINEAIRES:
ANGULAIRES:

NOM | SIGNATURE | DATE | | | | TITRE: PLECO

AUTEUR | Romain Jeanneret | RJE | 30.01.2014
VERIF.
APPR.
FAB.
QUAL. | | | | MATERIAU: LAITON | No. DE PLAN Support contre-électrode | A3

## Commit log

2023-07-06 images pour les articles
2023-08-11 Pour ajouter la localisation
2024-11-04 update files with 2020 versions
    [BoutonPoussoir_2020.stl, BoutonPoussoir_25.03.15.stl, Embout_2020.stl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]

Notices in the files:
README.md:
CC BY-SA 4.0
